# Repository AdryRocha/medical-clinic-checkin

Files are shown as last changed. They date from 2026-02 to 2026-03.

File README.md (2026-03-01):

# Medical Clinic Check-in System

Sistema embarcado de check-in para clínicas médicas baseado em Raspberry Pi Pico W. O paciente agenda sua consulta via Telegram Bot, apresenta o QR Code no totem, o dispositivo valida o agendamento, realiza verificação/cadastro biométrico e confirma o check-in com sincronização periódica via API REST.

---

## Sumário

- [Visão Geral](#visão-geral)
- [Hardware](#hardware)
- [Arquitetura de Software](#arquitetura-de-software)
- [Máquina de Estados](#máquina-de-estados)
- [Fluxo de Check-in](#fluxo-de-check-in)
- [Configuração](#configuração)
- [Build e Flash](#build-e-flash)
- [Backend (API + Bot)](#backend-api--bot)
- [Dependências](#dependências)
- [Estrutura do Projeto](#estrutura-do-projeto)
- [Demos Standalone](#demos-standalone)

---

## Visão Geral

| Item | Detalhe |
|---|---|
| **MCU** | RP2040W — Dual-core ARM Cortex-M0+ @ 133 MHz, WiFi CYW43439 |
| **RTOS** | FreeRTOS (5 tasks, queues, event groups) |
| **UI** | LVGL v8.3.11 — 7 telas, ícones desenhados via código |
| **Linguagem** | C++17 / C11 |
| **Build** | CMake ≥ 3.13 + Ninja 1.12.1 + GCC ARM 14_2_Rel1 |

**Funcionalidades principais:**
- Leitura de QR Code via scanner GM67 (UART)
- Validação de agendamento com dados armazenados no SD Card (FatFS)
- Verificação e cadastro de impressão digital via sensor R307S
- Sincronização de agendamentos e templates biométricos com API REST (Mongoose HTTP)
- Sincronização de hora via NTP (SNTP/lwIP)
- Interface touchscreen 4.0" 480×320

---

## Hardware

| Periférico | Interface | Pinos |
|---|---|---|
| Display ST7796 4.0" TFT 480×320 | SPI0 | MOSI=GP19, SCK=GP18, CS=GP17, DC=GP20, RST=GP21 |
| Touch FT6336U (Capacitivo) | I2C1 | SDA=GP6, SCL=GP7, RST=GP8, INT=GP9 |
| Scanner QR GM67 | UART0 | TX=GP0, RX=GP1 |
| Sensor Biométrico R307S | UART1 | TX=GP4, RX=GP5 |
| SD Card (FAT32) | SPI1 | MISO=GP12, MOSI=GP15, SCK=GP14, CS=GP13 |
| WiFi CYW43439 | Integrado | — |

> Diagrama completo em [`docs/diagrams/hardware_diagram.md`](docs/diagrams/hardware_diagram.md)

---

## Arquitetura de Software

O sistema segue uma arquitetura em **6 camadas**, desacoplando hardware de lógica de negócio:

```mermaid
graph TB
    subgraph Application["Application Layer"]
        Tasks["FreeRTOS Tasks"]
        StateMachine["State Machine"]
        UI["UI Screens"]
    end

    subgraph Service["Service Layer"]
        DataStorage["Data Storage Service"]
        AppointmentSvc["Appointment Service"]
        NetworkSync["Network Sync Service"]
        TimeSvc["Time Service"]
        FingerprintSvc["Fingerprint Service"]
    end

    subgraph Adapter["Adapter Layer"]
        LVGLDisplay["LVGL Display Adapter"]
        LVGLTouch["LVGL Touch Adapter"]
    end

    subgraph Driver["Driver Layer"]
        SDCard["SDCard Driver (FatFS)"]
        ST7796["ST7796 Display Driver"]
        FT6336U["FT6336U Touch Driver"]
        GM67["GM67 QR Driver"]
        R307S["R307S Fingerprint Driver"]
    end

    subgraph HAL["HAL Layer"]
        SPIHAL["SPI HAL"]
        UARTHAL["UART HAL"]
        I2CHAL["I2C HAL"]
        WiFiHAL["WiFi HAL"]
    end

    subgraph PicoSDK["Pico SDK + FreeRTOS"]
        hw_spi["hardware_spi"]
        hw_uart["hardware_uart"]
        hw_i2c["hardware_i2c"]
        pico_cyw43["pico_cyw43_arch"]
        freertos["FreeRTOS Kernel"]
    end

    Tasks -.-> StateMachine
    StateMachine -.-> UI
    Tasks -.-> AppointmentSvc
    Tasks -.-> TimeSvc
    Tasks -.-> FingerprintSvc
    Tasks -.-> DataStorage
    UI -.-> LVGLDisplay
    UI -.-> LVGLTouch
    DataStorage -.-> SDCard
    NetworkSync -.-> WiFiHAL
    FingerprintSvc -.-> R307S
    LVGLDisplay -.-> ST7796
    LVGLTouch -.-> FT6336U
    SDCard -.-> SPIHAL
    ST7796 -.-> SPIHAL
    FT6336U -.-> I2CHAL
    GM67 -.-> UARTHAL
    R307S -.-> UARTHAL
    SPIHAL -.-> hw_spi
    UARTHAL -.-> hw_uart
    I2CHAL -.-> hw_i2c
    WiFiHAL -.-> pico_cyw43

    style Application fill:#B3E5FC
    style Service fill:#A5D6A7
    style Adapter fill:#E1BEE7
    style Driver fill:#FFF9C4
    style HAL fill:#FFAB91
    style PicoSDK fill:#BDBDBD
```

### Tasks FreeRTOS

| Task | Prioridade | Stack | Responsabilidade |
|---|:---:|:-----:|---|
| `WiFi_Time_Init` | 5 | 2048 | Conecta WiFi, sincroniza NTP, auto-deleta após sucesso |
| `LVGL` | 4 | 3072 | `lv_timer_handler()` a cada 20 ms, gerencia telas por estado |
| `QR_Reader` | 3 | 1536 | Leitura contínua do GM67, envia dados para fila |
| `QR_Validator` | 2 | 2048 | Valida QR, biometria, marca check-in (orquestrador) |
| `Network` | 2 | 3072 | Download de agendamentos/templates, atualiza status na API |

### Services (Singletons)

| Service | Função |
|---|---|
| `AppointmentService` | Valida QR JSON, busca agendamento no SD, verifica CPF e janela de horário (−20/+10 min) |
| `NetworkSyncService` | Cliente HTTP (Mongoose): autenticação JWT, download/upload de agendamentos e templates |
| `DataStorageService` | Lê/grava JSON de agendamentos e templates `.dat` de fingerprint no SD Card (FatFS) |
| `TimeService` | Sincroniza NTP → RTC do RP2040, fornece data/hora formatadas |
| `FingerprintService` | Cadastro (2 capturas → template → SD + API) e verificação de digitais via R307S |

> Todos os diagramas em [`docs/diagrams/`](docs/diagrams/): [classes](docs/diagrams/class_diagrams.md) · [sequência](docs/diagrams/sequence_diagrams.md) · [arquitetura](docs/diagrams/software_architecture_layers_diagram.md)

---

## Máquina de Estados

| Estado | Descrição | Próximos Estados |
|---|---|---|
| `INITIALIZING` | Boot, conexão WiFi e sincronização NTP | `DOWNLOADING_APPOINTMENTS`, `ERROR_CRITICAL` |
| `DOWNLOADING_APPOINTMENTS` | Autenticação na API e download dos agendamentos do dia | `IDLE`, `ERROR_CRITICAL` |
| `IDLE` | Welcome Screen aguardando leitura de QR Code | `VALIDATING` |
| `VALIDATING` | Parse e validação do QR Code (cJSON, CPF, horário) | `FINGERPRINT_*`, `APPOINTMENT`, `ERROR` |
| `FINGERPRINT_VERIFYING` | Verificação biométrica (template do SD → sensor) | `APPOINTMENT`, `ERROR` |
| `FINGERPRINT_ENROLLING` | Cadastro biométrico (2 capturas → template) | `FINGERPRINT_UPLOADING`, `ERROR` |
| `FINGERPRINT_UPLOADING` | Upload do template para API | `APPOINTMENT`, `ERROR` |
| `APPOINTMENT` | Tela de check-in confirmado | `IDLE` (timeout 5s) |
| `ERROR` | Erro recuperável (QR inválido, consulta não encontrada) | `IDLE` (timeout 3s) |
| `ERROR_CRITICAL` | Falha de hardware, SD ausente, WiFi indisponível | `RESTARTING` |
| `RESTARTING` | Reinício via watchdog | `INITIALIZING` |

> Diagrama Mermaid completo em [`docs/diagrams/state_machine_diagram.md`](docs/diagrams/state_machine_diagram.md)

---

## Fluxo de Check-in

1. **Boot** → Conecta WiFi, sincroniza NTP, inicializa drivers
2. **Download** → Autentica na API (JWT), baixa agendamentos do dia + templates biométricos para o SD Card
3. **Idle** → Welcome Screen com relógio aguardando QR Code
4. **QR Scan** → GM67 lê QR → `task_qr_reader` envia JSON para fila FreeRTOS
5. **Validação** → `task_qr_validator` faz parse (cJSON), busca agendamento no SD, valida CPF e janela de horário
6. **Biometria** (se necessário):
   - *Verificação*: carrega template do SD → sensor → captura e compara
   - *Cadastro*: 2 capturas → gera template → salva no SD + upload para API
7. **Confirmação** → Tela de check-in confirmado, marca agendamento como "realizada" (local + API)
8. **Retorno** → Timeout → volta para Idle

---

## Configuração

Todas as configurações ficam centralizadas em `config/`:

| Arquivo | Descrição |
|---|---|
| `wifi_config.hpp` | SSID, senha e país do WiFi |
| `api_config.hpp` | URL da API, endpoints, credenciais, timeouts |
| `pin_config.hpp` | Mapeamento de todos os GPIOs |
| `display_config.hpp` | Resolução, rotação, SPI speed, buffer LVGL |
| `fingerprint_config.hpp` | UART e baudrate do sensor biométrico |
| `qr_code_reader_config.hpp` | UART e rate do scanner QR |
| `FreeRTOSConfig.h` | Configuração do kernel FreeRTOS |
| `lv_conf.h` | Configuração do LVGL |
| `hw_config.c` | Configuração do SD Card (FatFS) |
| `mongoose_config.h` | Configuração do Mongoose HTTP |
| `lwipopts.h` | Configuração do lwIP (TCP/IP stack) |

Antes de compilar, edite pelo menos:

**WiFi** (`config/wifi_config.hpp`):
```cpp
#define WIFI_SSID     "SuaRede"
#define WIFI_PASSWORD "SuaSenha"
#define WIFI_COUNTRY  "BR"
```

**API** (`config/api_config.hpp`):
```cpp
#define API_BASE_URL  "http://192.168.0.13:8000"
#define API_USERNAME  "seu_usuario"
#define API_PASSWORD  "sua_senha"
```

**Pinos** (`config/pin_config.hpp`): altere caso sua fiação seja diferente.

---

## Build e Flash

### Pré-requisitos

- [VS Code](https://code.visualstudio.com/) com extensão [**Raspberry Pi Pico**](https://marketplace.visualstudio.com/items?itemName=raspberry-pi.raspberry-pi-pico)
- Pico SDK 2.1.1, GCC ARM 14_2_Rel1, CMake ≥ 3.13, Ninja 1.12.1
- (Ou use o **Dev Container** incluso — tudo já configurado)

### Compilar

**Via extensão Raspberry Pi Pico (recomendado):**
1. Abra o projeto no VS Code
2. `Ctrl+Shift+B` → selecione **Compile Project**

**Via terminal:**
```bash
mkdir -p build && cd build
cmake .. -G Ninja
ninja
```

### Flash no Pico

**Via extensão Raspberry Pi Pico (recomendado):**
1. Conecte o Pico via USB
2. Clique no botão **Run** na barra de status, ou execute a task **Run Project**

**Via terminal:**
```bash
# picotool (sem desconectar USB):
picotool load build/medical-clinic-checkin-pico.elf -fx

# Ou UF2 manual: segure BOOTSEL, conecte USB, copie o .uf2
cp build/medical-clinic-checkin-pico.uf2 /media/$USER/RPI-RP2/
```

### Monitor Serial

```bash
minicom -b 115200 -o -D /dev/ttyACM0
```

---

## Backend (API + Bot)

O sistema embarcado se comunica com um backend composto por:

- **API REST** (FastAPI + PostgreSQL) — gerencia pacientes, profissionais, agendamentos e biometria
- **Telegram Bot** — agendamento de consultas pelo paciente, com envio do QR Code

> Repositório do backend: [Luana-Menezes/Clinicas_Medicas_WebAPI](https://github.com/Luana-Menezes/Clinicas_Medicas_WebAPI)

---

## Dependências

| Biblioteca | Versão | Origem | Uso |
|---|---|---|-----|
| [Pico SDK](https://github.com/raspberrypi/pico-sdk) | 2.1.1 | SDK | `pico_stdlib`, `hardware_spi`, `hardware_i2c`, `hardware_uart`, `hardware_rtc`, `pico_cyw43_arch`, lwIP |
| [FreeRTOS-Kernel](https://github.com/FreeRTOS/FreeRTOS-Kernel) | — | Submodule | RTOS: tasks, queues, event groups, semáforos |
| [LVGL](https://github.com/lvgl/lvgl) | 8.3.11 | FetchContent | Interface gráfica touchscreen |
| [no-OS-FatFS](https://github.com/carlk3/no-OS-FatFS-SD-SPI-RPi-Pico) | — | Submodule | Sistema de arquivos FAT32 no SD Card via SPI |
| [cJSON](https://github.com/DaveGamble/cJSON) | 1.7.18 | FetchContent | Parser JSON (agendamentos, QR Code) |
| [Mongoose](https://github.com/cesanta/mongoose) | 7.20 | FetchContent | Cliente HTTP para comunicação com a API |

---

## Estrutura do Projeto

```
├── CMakeLists.txt
├── pico_sdk_import.cmake
│
├── config/
│   ├── api_config.hpp                  # URL da API, endpoints, credenciais, timeouts
│   ├── display_config.hpp              # Resolução, rotação, SPI speed, buffer LVGL
│   ├── fingerprint_config.hpp          # UART e baudrate do sensor biométrico
│   ├── FreeRTOSConfig.h                # Configuração do kernel FreeRTOS
│   ├── hw_config.c                     # Configuração do SD Card (FatFS)
│   ├── lv_conf.h                       # Configuração do LVGL
│   ├── lvgl_tick_custom.h              # Tick customizado do LVGL para FreeRTOS
│   ├── lwipopts.h                      # Configuração do lwIP (TCP/IP stack)
│   ├── mongoose_config.h               # Configuração do Mongoose HTTP
│   ├── pin_config.hpp                  # Mapeamento de todos os GPIOs
│   ├── qr_code_reader_config.hpp       # UART e baudrate do scanner QR
│   ├── sntp_callbacks.h                # Callbacks de sincronização NTP
│   └── wifi_config.hpp                 # SSID, senha e país do WiFi
│
├── src/
│   ├── main.cpp                        # Entry point: init drivers → create tasks → scheduler
│   │
│   ├── core/
│   │   ├── state_machine.hpp           # Máquina de estados (singleton, 11 estados)
│   │   └── state_machine.cpp
│   │
│   ├── hal/
│   │   ├── interfaces/
│   │   │   ├── hal_spi_interface.hpp   # Interface abstrata SPI
│   │   │   ├── hal_i2c_interface.hpp   # Interface abstrata I2C
│   │   │   ├── hal_uart_interface.hpp  # Interface abstrata UART
│   │   │   └── hal_wifi_interface.hpp  # Interface abstrata WiFi
│   │   └── rp2040/
│   │       ├── hal_spi_rp2040.hpp/.cpp
│   │       ├── hal_i2c_rp2040.hpp/.cpp
│   │       ├── hal_uart_rp2040.hpp/.cpp
│   │       └── hal_wifi_rp2040.hpp/.cpp
│   │
│   ├── drivers/
│   │   ├── display/
│   │   │   ├── interface/display_interface.hpp
│   │   │   └── st7796/st7796_driver.hpp/.cpp
│   │   ├── touch/
│   │   │   ├── interface/touch_interface.hpp
│   │   │   └── ft6336u/ft6336u_driver.hpp/.cpp
│   │   ├── qr_code_reader/
│   │   │   ├── interface/qr_interface.hpp
│   │   │   └── gm67/gm67_driver.hpp/.cpp
│   │   └── fingerprint/
│   │       ├── interface/fingerprint_interface.hpp
│   │       └── r307s/r307s_driver.hpp/.cpp
│   │
│   ├── adapters/lvgl/
│   │   ├── lvgl_display_adapter.hpp/.cpp
│   │   └── lvgl_touch_adapter.hpp/.cpp
│   │
│   ├── services/
│   │   ├── appointment_service.hpp/.cpp     # Validação de QR e agendamentos
│   │   ├── data_storage_service.hpp/.cpp    # Leitura/escrita no SD Card
│   │   ├── fingerprint_service.hpp/.cpp     # Cadastro e verificação biométrica
│   │   ├── network_sync_service.hpp/.cpp    # Cliente HTTP (Mongoose)
│   │   └── time_service.hpp/.cpp            # NTP → RTC, data/hora
│   │
│   ├── tasks/
│   │   ├── task_wifi_time_init.hpp/.cpp     # Conexão WiFi + sincronização NTP
│   │   ├── task_lvgl.hpp/.cpp               # Loop LVGL + gerência de telas
│   │   ├── task_qr_reader.hpp/.cpp          # Leitura contínua do scanner QR
│   │   ├── task_qr_validator.hpp/.cpp       # Validação e orquestração do check-in
│   │   └── task_network.hpp/.cpp            # Download de agendamentos e templates
│   │
│   ├── ui/screens/
│   │   ├── welcome_screen.hpp/.cpp          # Tela principal (idle)
│   │   ├── init_status_screen.hpp/.cpp      # Tela de boot (WiFi, NTP, SD)
│   │   ├── appointment_screen.hpp/.cpp      # Check-in confirmado
│   │   ├── error_screen.hpp/.cpp            # Erro recuperável
│   │   ├── error_critical_screen.hpp/.cpp   # Erro crítico + countdown reboot
│   │   ├── fingerprint_operation_screen.hpp/.cpp  # Verificação/cadastro digital
│   │   └── fingerprint_upload_screen.hpp/.cpp     # Upload de template
│   │
│   └── tests/code_examples/
│       ├── README.md                        # Instruções dos demos
│       ├── lvgl_rtos_demo.cpp               # Demo display + touch
│       ├── qr_code_reader_demo.cpp          # Demo scanner QR
│       ├── fingerprint_demo.cpp             # Demo sensor biométrico
│       ├── sdcard_fatfs_demo.cpp            # Demo SD Card
│       └── wifi_demo.cpp                    # Demo WiFi
│
├── lib/
│   ├── FreeRTOS-Kernel/                     # Submodule
│   └── no-OS-FatFS/                         # Submodule
│
└── docs/
    ├── dev/                                 # Notas de desenvolvimento por periférico
    └── diagrams/
        ├── hardware_diagram.md
        ├── software_architecture_layers_diagram.md
        ├── class_diagrams.md
        ├── sequence_diagrams.md
        └── state_machine_diagram.md
```

---

## Demos Standalone

O projeto inclui demos para testar cada periférico isoladamente. Para compilar um demo específico, altere `BUILD_TARGET` no CMake:

```bash
cd build
cmake .. -G Ninja -DBUILD_TARGET=QR_DEMO
ninja
```

| Target | Testa |
|---|---|
| `MAIN` | Aplicação completa (padrão) |
| `LVGL_DEMO` | Display + touchscreen com widgets LVGL |
| `QR_DEMO` | Scanner GM67 em modo contínuo |
| `FINGERPRINT_DEMO` | Sensor R307S — cadastro, verificação, busca, exclusão |
| `SDCARD_DEMO` | SD Card — mount, leitura, escrita, listagem |
| `WIFI_DEMO` | WiFi — conexão, scan, DNS, TCP echo server, RSSI |

> Instruções detalhadas em [`src/tests/code_examples/README.md`](src/tests/code_examples/README.md)

---

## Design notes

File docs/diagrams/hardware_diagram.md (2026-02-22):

# Hardware Architecture

```mermaid
graph TB
    subgraph RPI["Raspberry Pi Pico<br/>"]
        CPU["RP2040W<br/>Dual Core<br/>"]
        
        subgraph Interfaces["Interfaces de Comunicação"]
            UART0["UART0"]
            UART1["UART1"]
            SPI0["SPI0"]
            SPI1["SPI1"]
            I2C1["I2C1"]
        end
        
        CPU --> UART0
        CPU --> UART1
        CPU --> SPI0
        CPU --> SPI1
        CPU --> I2C1
    end
    
    UART0 <-->|"TX/RX (GP0/GP1)"| QR["GM67<br/>Leitor QR Code<br/>Serial TTL"]
    UART1 <-->|"TX/RX (GP4/GP5)"| FP["R307S<br/>Leitor Biométrico<br/>Fingerprint"]
    SPI0 -->|"MOSI/SCK/CS DC(RS)/RST (GP19/18/17 20/21)"| DISPLAY["Display 4.0&quot;<br/>TFT 480x320<br/>Driver ST7796<br/>Touch Capacitivo"]
    SPI1 <-->|"MOSI/MISO/SCK/CS (GP15/12/14/13)"| SD["Módulo SD Card<br/>Armazenamento<br/>FAT32"]
    I2C1 <--> |"SDA/SCL/RST/INT (GP6/7/8/9)"| TOUCH["TouchScreen"]

    style RPI fill:#e3f2fd,stroke:#1565c0,stroke-width:4px,color:#000
    style CPU fill:#bbdefb,stroke:#1976d2,stroke-width:3px,color:#000
    style Interfaces fill:#ffe082,stroke:#fbc02d,stroke-width:3px,color:#000
    style UART0 fill:#fff9c4,stroke:#fbc02d,stroke-width:2px,color:#000
    style UART1 fill:#fff9c4,stroke:#fbc02d,stroke-width:2px,color:#000
    style SPI0 fill:#c8e6c9,stroke:#388e3c,stroke-width:2px,color:#000
    style SPI1 fill:#c8e6c9,stroke:#388e3c,stroke-width:2px,color:#000
    style I2C1 fill:#ffccbc,stroke:#d84315,stroke-width:2px,color:#000
    style QR fill:#b3e5fc,stroke:#0288d1,stroke-width:2px,color:#000
    style FP fill:#f8bbd0,stroke:#ad1457,stroke-width:2px,color:#000
    style DISPLAY fill:#fffde7,stroke:#fbc02d,stroke-width:3px,color:#000
    style SD fill:#e1bee7,stroke:#6a1b9a,stroke-width:2px,color:#000
    style TOUCH fill:#80deea,stroke:#00838f,stroke-width:2px,color:#000

    linkStyle default stroke:#000,stroke-width:1px,color:#000
```

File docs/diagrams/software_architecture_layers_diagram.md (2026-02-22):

# Software Architecture

```mermaid
graph TB
    subgraph Application["Application Layer"]
        Tasks["FreeRTOS Tasks"]
        StateMachine["State Machine"]
        UI["UI Screens"]
    end

    subgraph Service["Service Layer"]
        DataStorage["Data Storage Service*"]
        AppointmentSvc["Appointment Service*"]
        NetworkSync["Network Sync Service*"]
        TimeSvc["Time Service*"]
        FingerprintSvc["Fingerprint Service*"]
    end

    subgraph Adapter["Adapter Layer"]
        LVGLDisplay["LVGL Display Adapter"]
        LVGLTouch["LVGL Touch Adapter"]
    end

    subgraph Driver["Driver Layer"]
        SDCard["SDCard Driver (FatFS)"]
        ST7796["ST7796 Display Driver"]
        FT6336U["FT6336U Touch Driver"]
        GM67["GM67 QR Driver"]
        R307S["R307S Fingerprint Driver"]
    end

    subgraph HAL["HAL Layer"]
        SPIHAL["SPI HAL"]
        GPIOHAL["GPIO HAL"]
        UARTHAL["UART HAL"]
        I2CHAL["I2C HAL"]
        WiFiHAL["WiFi HAL"]
    end

    subgraph PicoSDK["Pico SDK + FreeRTOS"]
        hw_spi["hardware_spi"]
        hw_gpio["hardware_gpio"]
        hw_uart["hardware_uart"]
        hw_i2c["hardware_i2c"]
        pico_stdlib["pico_stdlib"]
        pico_cyw43["pico_cyw43_arch (WiFi)"]
        freertos["FreeRTOS Kernel"]
    end

    subgraph Hardware["Hardware"]
        RP2040W["RP2040W Silicon"]
    end

    %% Application internal connections
    Tasks -.-> StateMachine
    StateMachine -.-> UI
    
    %% Application to Service connections
    Tasks -.-> DataStorage
    Tasks -.-> AppointmentSvc
    Tasks -.-> TimeSvc
    Tasks -.-> FingerprintSvc
    AppointmentSvc -.-> TimeSvc

    %% Application to Adapter connections
    UI -.-> LVGLDisplay
    UI -.-> LVGLTouch

    %% Service to Driver/HAL connections
    DataStorage -.-> SDCard
    AppointmentSvc -.-> GM67
    NetworkSync -.-> SDCard
    NetworkSync -.-> WiFiHAL
    TimeSvc -.-> WiFiHAL
    FingerprintSvc -.-> R307S
    FingerprintSvc -.-> DataStorage

    %% Adapter to Driver connections
    LVGLDisplay -.-> ST7796
    LVGLTouch -.-> FT6336U

    %% Driver to HAL connections
    SDCard -.-> SPIHAL
    ST7796 -.-> SPIHAL
    FT6336U -.-> I2CHAL
    GM67 -.-> UARTHAL
    R307S -.-> UARTHAL

    SPIHAL -.-> hw_spi
    GPIOHAL -.-> hw_gpio
    UARTHAL -.-> hw_uart
    I2CHAL -.-> hw_i2c
    WiFiHAL -.-> pico_cyw43

    hw_spi -.-> RP2040W
    hw_gpio -.-> RP2040W
    hw_uart -.-> RP2040W
    hw_i2c -.-> RP2040W
    pico_stdlib -.-> RP2040W
    pico_cyw43 -.-> RP2040W
    freertos -.-> RP2040W

    style Application fill:#B3E5FC
    style Service fill:#A5D6A7
    style Adapter fill:#E1BEE7
    style Driver fill:#FFF9C4
    style HAL fill:#FFAB91
    style PicoSDK fill:#BDBDBD
    style Hardware fill:#757575
```

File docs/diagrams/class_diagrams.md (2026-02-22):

# Class Diagrams

Diagramas de classes de todas as camadas do sistema.

---

## 1. Services Layer

Camada de serviços com lógica de negócio.

```mermaid
classDiagram
    direction TB

    class StateMachine {
        <<Singleton>>
        -State state_
        +getInstance() StateMachine&
        +setState(State newState) void
        +getState() State
        +getStateName() const char*
        +getStateName(State state) const char*
    }

    class State {
        <<enumeration>>
        INITIALIZING
        DOWNLOADING_APPOINTMENTS
        IDLE
        VALIDATING
        FINGERPRINT_VERIFYING
        FINGERPRINT_ENROLLING
        FINGERPRINT_UPLOADING
        APPOINTMENT
        ERROR
        ERROR_CRITICAL
        RESTARTING
    }

    class AppointmentService {
        <<Singleton>>
        +getInstance() AppointmentService&
        +validateAndParseQRCode(qr_json, qr_data) bool
        +validateAppointmentById(qr_data, info) bool
        +markAppointmentCompleted(appointment_id) bool
        +maskCPF(cpf) string$
        -findAppointmentById(root, appt_id, appointment_out) bool
        -extractAppointmentData(appointment, info) void
        -validateCPFMatch(qr_cpf, db_cpf) bool
        -validateAppointmentTime(appointment_time) bool
        -cleanCPF(cpf) string
    }

    class FingerprintService {
        <<Singleton>>
        -R307S_Driver* fp_driver_
        -HAL_UART_RP2040* uart_hal_
        -bool is_initialized_
        +getInstance() FingerprintService&
        +init() bool
        +isInitialized() bool
        +enrollFingerprint(template_data, timeout_per_scan_ms) bool
        +verifyFingerprint(patient_id, confidence, timeout_ms) bool
        +clearSensorMemory() bool
        +getTemplateCount(count) bool
        -loadTemplateToSensor(data, slot) bool
        -waitForFinger(timeout_ms) bool
        -waitForFingerRemoval(timeout_ms) bool
    }

    class NetworkSyncService {
        <<Singleton>>
        -string access_token_
        +getInstance() NetworkSyncService&
        +authenticate(timeout_ms) bool
        +downloadAppointments(date, json_response, timeout_ms) bool
        +updateAppointmentStatus(appointment_id, new_status, timeout_ms) bool
        +downloadFingerprintTemplate(patient_id, template_data, timeout_ms) bool
        +uploadFingerprintTemplate(patient_id, template_data, timeout_ms) bool
        +downloadFingerprintsForAppointments(json_appointments) int
        +hasToken() bool
        -httpCallback(c, ev, ev_data) void$
    }

    class DataStorageService {
        <<Singleton>>
        +getInstance() DataStorageService&
        +init() bool
        +saveAppointments(date, json_data) bool
        +hasAppointments(date) bool
        +readAppointments(date, json_data) bool
        +getTodayDate() string
        +getTomorrowDate() string
        +isReady() bool
        +markAppointmentCompleted(date, appointment_id) bool
        +isAppointmentCompleted(date, appointment_id) bool
        +saveFingerprintTemplate(patient_id, template_data) bool
        +loadFingerprintTemplate(patient_id, template_data) bool
        +hasFingerprintTemplate(patient_id) bool
        +deleteFingerprintTemplate(patient_id) bool
        +clearAllFingerprints() bool
    }

    class TimeService {
        <<Singleton>>
        -bool initialized_
        -bool time_synced_
        +getInstance() TimeService&
        +init() bool
        +getTimeString() string
        +getDateString() string
        +getDateTimeString() string
        +isTimeSynced() bool
        +markTimeSynced() void
        +extractHourMinute(time_str, hour, min) bool$
    }

    class AppointmentInfo {
        <<struct>>
        +int id
        +string patient_name
        +string patient_cpf
        +string professional_name
        +string category
        +string time
        +string status
        +string qr_hash
        +bool found
        +PatientBiometry patient
        +bool requires_fingerprint_verification
        +bool requires_fingerprint_enrollment
    }

    class PatientBiometry {
        <<struct>>
        +int id
        +bool aceita_digital
        +bool fingerprint_uploaded
    }

    class QRCodeData {
        <<struct>>
        +string cmd
        +int appt_id
        +string cpf
        +string name
        +string hash
        +bool valid
    }

    %% Relacionamentos
    StateMachine *-- State : contains
    AppointmentInfo *-- PatientBiometry : contains

    AppointmentService ..> QRCodeData : uses
    AppointmentService ..> AppointmentInfo : uses
    AppointmentService ..> DataStorageService : depends
    AppointmentService ..> NetworkSyncService : depends
    AppointmentService ..> TimeService : depends

    FingerprintService ..> DataStorageService : loads templates
    FingerprintService ..> R307S_Driver : controls sensor

    NetworkSyncService ..> DataStorageService : saves to

    DataStorageService ..> TimeService : gets date
```

---

## 2. HAL Layer (Hardware Abstraction)

Interfaces abstratas e implementações específicas do RP2040.

```mermaid
classDiagram
    direction TB

    class HAL_SPI_Interface {
        <<interface>>
        +init(baudrate) bool*
        +write(data, len) size_t*
        +read(data, len) size_t*
        +setCS(state) void*
        +setDC(state) void*
        +reset() void*
    }

    class HAL_I2C_Interface {
        <<interface>>
        +init(baudrate) bool*
        +write(address, data, length, sendStop) bool*
        +read(address, data, length, sendStop) bool*
        +writeRead(address, writeData, writeLength, readData, readLength) bool*
    }

    class HAL_UART_Interface {
        <<interface>>
        +init(baudrate, data_bits, stop_bits, parity) bool*
        +write(data, length) size_t*
        +read(data, length) size_t*
        +available() size_t*
        +writeByte(byte) void*
        +readByte() uint8_t*
    }

    class HAL_SPI_RP2040 {
        -spi_inst_t* spi_instance_
        -uint8_t pin_mosi_
        -uint8_t pin_miso_
        -uint8_t pin_sck_
        -uint8_t pin_cs_
        -uint8_t pin_dc_
        -uint8_t pin_rst_
        +init(baudrate) bool
        +write(data, len) size_t
        +read(data, len) size_t
        +setCS(state) void
        +setDC(state) void
        +reset() void
    }

    class HAL_I2C_RP2040 {
        -i2c_inst_t* i2c_instance_
        -uint8_t pin_sda_
        -uint8_t pin_scl_
        +init(baudrate) bool
        +write(address, data, length, sendStop) bool
        +read(address, data, length, sendStop) bool
        +writeRead(...) bool
    }

    class HAL_UART_RP2040 {
        -uart_inst_t* uart_instance_
        -uint8_t pin_tx_
        -uint8_t pin_rx_
        +init(baudrate, data_bits, stop_bits, parity) bool
        +write(data, length) size_t
        +read(data, length) size_t
        +available() size_t
    }

    HAL_SPI_Interface <|.. HAL_SPI_RP2040 : implements
    HAL_I2C_Interface <|.. HAL_I2C_RP2040 : implements
    HAL_UART_Interface <|.. HAL_UART_RP2040 : implements
```

---

## 3. Driver Layer

Drivers de hardware com interfaces abstratas.

```mermaid
classDiagram
    direction TB

    class DisplayInterface {
        <<interface>>
        +init() bool*
        +getWidth() uint16_t*
        +getHeight() uint16_t*
        +drawPixels(x1, y1, x2, y2, color_data) void*
        +fillRect(x1, y1, x2, y2, color) void*
        +setBacklight(brightness) void*
        +setPower(state) void*
        +setRotation(rotation) void*
    }

    class TouchInterface {
        <<interface>>
        +init() bool*
        +readTouch(point) bool*
        +isTouched() bool*
        +getMaxTouchPoints() uint8_t*
    }

    class QR_Interface {
        <<interface>>
        +init() bool*
        +readScan(buffer, max_length, timeout_ms) size_t*
        +isScanAvailable() bool*
        +setScanCallback(callback) void*
        +process() void*
        +enableScan(enable) bool*
        +triggerScan() bool*
    }

    class FingerprintInterface {
        <<interface>>
        +init() bool*
        +verifyPassword() bool*
        +getImage() FingerprintStatus*
        +image2Tz(slot) FingerprintStatus*
        +createModel() FingerprintStatus*
        +storeModel(id) FingerprintStatus*
        +fingerFastSearch(match) FingerprintStatus*
        +deleteModel(id) FingerprintStatus*
        +emptyDatabase() FingerprintStatus*
        +getTemplateCount(count) FingerprintStatus*
        +enrollFingerprint(id) FingerprintStatus*
        +matchFingerprint(match) FingerprintStatus*
        +loadTemplate(id, slot) FingerprintStatus*
        +uploadTemplate(slot, data) FingerprintStatus*
        +downloadTemplate(slot, data) FingerprintStatus*
        +compareTemplates(confidence) FingerprintStatus*
        +setLED(on) bool*
    }

    class ST7796Driver {
        -HAL_SPI_Interface* hal_spi_
        -uint16_t width_
        -uint16_t height_
        -uint8_t rotation_
        +init() bool
        +drawPixels(...) void
        +fillRect(...) void
        +setRotation(rotation) void
    }

    class FT6336U_Driver {
        -HAL_I2C_Interface* i2c_
        -uint8_t i2c_address_
        -uint16_t screen_width_
        -uint16_t screen_height_
        +init() bool
        +readTouch(point) bool
        +isTouched() bool
        +reset() void
    }

    class GM67_Driver {
        -HAL_UART_Interface* uart_hal_
        -ScanCallback scan_callback_
        -char rx_buffer_[1024]
        +init() bool
        +readScan(buffer, max_length, timeout_ms) size_t
        +isScanAvailable() bool
        +process() void
        +sendCommand(command) bool
    }

    class R307S_Driver {
        -HAL_UART_Interface* uart_hal_
        -uint32_t password_
        -uint32_t address_
        -bool is_initialized_
        -size_t data_packet_size_
        +init() bool
        +verifyPassword() bool
        +getImage() FingerprintStatus
        +image2Tz(slot) FingerprintStatus
        +createModel() FingerprintStatus
        +storeModel(id) FingerprintStatus
        +fingerFastSearch(match) FingerprintStatus
        +deleteModel(id) FingerprintStatus
        +emptyDatabase() FingerprintStatus
        +getTemplateCount(count) FingerprintStatus
        +enrollFingerprint(id) FingerprintStatus
        +matchFingerprint(match) FingerprintStatus
        +loadTemplate(id, slot) FingerprintStatus
        +uploadTemplate(slot, data) FingerprintStatus
        +downloadTemplate(slot, data) FingerprintStatus
        +compareTemplates(confidence) FingerprintStatus
        +setLED(on) bool
        +readSysPara(status, system_id, library_size, security_level) FingerprintStatus
    }

    class TouchPoint {
        <<struct>>
        +uint16_t x
        +uint16_t y
        +uint8_t event
        +bool valid
    }

    class FingerprintStatus {
        <<enumeration>>
        OK
        ERROR_COMM
        ERROR_NO_FINGER
        ERROR_ENROLL_FAIL
        ERROR_BAD_IMAGE
        ERROR_TOO_MESSY
        ERROR_FEATURE_FAIL
        ERROR_NO_MATCH
        ERROR_NOT_FOUND
        ERROR_MERGE_FAIL
        ERROR_DELETE_FAIL
        ERROR_CLEAR_FAIL
        ERROR_WRONG_PASSWORD
        ERROR_NO_TEMPLATE
        ERROR_UPLOAD_FAIL
        ERROR_RECV_FAIL
        ERROR_TIMEOUT
    }

    class FingerprintMatch {
        <<struct>>
        +uint16_t id
        +uint16_t confidence
        +bool matched
    }

    DisplayInterface <|.. ST7796Driver : implements
    TouchInterface <|.. FT6336U_Driver : implements
    QR_Interface <|.. GM67_Driver : implements
    FingerprintInterface <|.. R307S_Driver : implements

    ST7796Driver --> HAL_SPI_Interface : uses
    FT6336U_Driver --> HAL_I2C_Interface : uses
    GM67_Driver --> HAL_UART_Interface : uses
    R307S_Driver --> HAL_UART_Interface : uses

    TouchInterface ..> TouchPoint : returns
    FingerprintInterface ..> FingerprintStatus : returns
    FingerprintInterface ..> FingerprintMatch : returns
```

---

## 4. Adapter Layer

Adaptadores entre LVGL e drivers de hardware.

```mermaid
classDiagram
    direction TB

    class LVGLDisplayAdapter {
        -DisplayInterface* display_
        -lv_disp_drv_t disp_drv_
        -lv_disp_draw_buf_t draw_buf_
        -lv_color_t* buf1_
        -lv_color_t* buf2_
        +LVGLDisplayAdapter(display, buf1, buf2, buf_size)
        +registerDisplay() lv_disp_t*
        -flushCallback(disp_drv, area, color_p) void$
    }

    class LVGLTouchAdapter {
        -TouchInterface* touch_
        -lv_indev_drv_t indev_drv_
        -lv_indev_t* indev_
        -uint16_t display_width_
        -uint16_t display_height_
        -uint8_t rotation_
        +LVGLTouchAdapter(touch, width, height, rotation)
        +registerInputDevice() lv_indev_t*
        -readCallback(drv, data) void$
        -transformCoordinates(point, x_out, y_out) void
    }

    class DisplayInterface {
        <<interface>>
    }

    class TouchInterface {
        <<interface>>
    }

    LVGLDisplayAdapter --> DisplayInterface : uses
    LVGLTouchAdapter --> TouchInterface : uses
```

---

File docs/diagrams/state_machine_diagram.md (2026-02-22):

# State Machine Diagram

## 1. Fluxo Principal

Inicialização, check-in e tratamento de erros.

```mermaid
stateDiagram-v2
    [*] --> INITIALIZING : Power On

    INITIALIZING : Conecta WiFi, NTP e drivers

    DOWNLOADING_APPOINTMENTS : Autentica API e baixa agendamentos

    IDLE : Aguardando QR Code
    IDLE : Welcome Screen + data/hora

    VALIDATING : Parse JSON + valida agendamento

    APPOINTMENT : Exibe confirmação de check-in

    ERROR : Erro recuperável (3-5s)

    ERROR_CRITICAL : Falha de hardware / WiFi / SD

    RESTARTING : Reiniciando via watchdog

    %% Transições
    INITIALIZING --> DOWNLOADING_APPOINTMENTS : WiFi + NTP OK
    INITIALIZING --> ERROR_CRITICAL : Falha crítica

    DOWNLOADING_APPOINTMENTS --> IDLE : Download OK
    DOWNLOADING_APPOINTMENTS --> ERROR_CRITICAL : Falha persistente

    IDLE --> VALIDATING : QR Code recebido

    VALIDATING --> APPOINTMENT : Válida (sem biometria)
    VALIDATING --> FINGERPRINT : Requer biometria
    VALIDATING --> ERROR : Inválido

    state FINGERPRINT {
        direction LR
        [*] --> Ver_Diagrama_2
    }

    FINGERPRINT --> APPOINTMENT : Biometria OK
    FINGERPRINT --> ERROR : Biometria falhou

    APPOINTMENT --> IDLE : Timeout (5s)
    ERROR --> IDLE : Timeout (3s)
    ERROR_CRITICAL --> RESTARTING : Timeout ou botão
    RESTARTING --> [*] : Watchdog reset
```

---

## 2. Sub-estados Biométricos

Detalhamento do fluxo de fingerprint dentro do check-in.

```mermaid
stateDiagram-v2
    state "Biometria" as BIO {
        [*] --> DECISION

        state DECISION <<choice>>
        DECISION --> FINGERPRINT_VERIFYING : Template existe
        DECISION --> FINGERPRINT_ENROLLING : Sem template

        FINGERPRINT_VERIFYING : Carrega template do SD
        FINGERPRINT_VERIFYING : Captura dedo + compara

        FINGERPRINT_ENROLLING : Captura em 2 etapas
        FINGERPRINT_ENROLLING : Gera modelo + salva SD

        FINGERPRINT_UPLOADING : Envia template para API

        FINGERPRINT_VERIFYING --> [*] : Digital verificada
        FINGERPRINT_VERIFYING --> ERROR : Não reconhecida

        FINGERPRINT_ENROLLING --> FINGERPRINT_UPLOADING : Cadastro OK
        FINGERPRINT_ENROLLING --> ERROR : Falha no cadastro

        FINGERPRINT_UPLOADING --> [*] : Upload concluído/offline

        ERROR --> [*] : Retorna erro
    }
```

## Descrição dos Estados

| Estado | Descrição | Próximos Estados |
|---|---|---|
| `INITIALIZING` | Boot do sistema, conexão WiFi e sincronização NTP | `DOWNLOADING_APPOINTMENTS`, `ERROR_CRITICAL` |
| `DOWNLOADING_APPOINTMENTS` | Autenticação na API e download dos agendamentos do dia | `IDLE`, `ERROR_CRITICAL` |
| `IDLE` | Aguardando leitura de QR Code na Welcome Screen | `VALIDATING` |
| `VALIDATING` | Processando e validando dados do QR Code | `FINGERPRINT_VERIFYING`, `FINGERPRINT_ENROLLING`, `APPOINTMENT`, `ERROR` |
| `FINGERPRINT_VERIFYING` | Verificando digital do paciente contra template armazenado | `APPOINTMENT`, `ERROR` |
| `FINGERPRINT_ENROLLING` | Cadastrando digital do paciente (captura em 2 etapas) | `FINGERPRINT_UPLOADING`, `ERROR` |
| `FINGERPRINT_UPLOADING` | Enviando template biométrico para API | `APPOINTMENT` |
| `APPOINTMENT` | Exibindo confirmação de check-in ao paciente | `IDLE` |
| `ERROR` | Erro recuperável (QR inválido, consulta não encontrada, digital falhou) | `IDLE` |
| `ERROR_CRITICAL` | Erro crítico que requer intervenção | `RESTARTING` |
| `RESTARTING` | Sistema reiniciando via watchdog | `INITIALIZING` |

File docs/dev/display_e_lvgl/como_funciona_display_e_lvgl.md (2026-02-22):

# Display, HAL, Adapters e LVGL

## 📋 Visão Geral da Arquitetura

O sistema usa **3 camadas** para controlar o display:

```
┌─────────────────────────────────────────┐
│         LVGL (Biblioteca GUI)           │  ← Interface gráfica
├─────────────────────────────────────────┤
│      LVGLDisplayAdapter (Bridge)        │  ← Conecta LVGL ao driver
├─────────────────────────────────────────┤
│   ST7796Driver (Display Controller)     │  ← Controla o display
├─────────────────────────────────────────┤
│   HAL_SPI_RP2040 (Hardware Abstraction) │  ← Acessa hardware SPI
└─────────────────────────────────────────┘
```

---

## 🔧 1. HAL (Hardware Abstraction Layer)

### O que é?
Camada que **isola o hardware específico** (RP2040) do resto do código.

### Interface: `HAL_SPI_Interface`
```cpp
class HAL_SPI_Interface {
    virtual bool init(uint32_t baudrate) = 0;
    virtual size_t write(const uint8_t* data, size_t len) = 0;
    virtual void setCS(bool state) = 0;  // Chip Select
    virtual void setDC(bool state) = 0;  // Data/Command
    virtual void reset() = 0;
};
```

### Implementação: `HAL_SPI_RP2040`
- Usa **hardware/spi.h** do Pico SDK
- Configura pinos GPIO (MOSI, SCK, CS, DC, RST)
- Velocidade: até 20 MHz

**Por que existe?** 
- Trocar de microcontrolador (ex: STM32) só requer reimplementar o HAL
- Resto do código permanece igual

---

## 🖥️ 2. Driver de Display

### Interface: `DisplayInterface`
```cpp
class DisplayInterface {
    virtual bool init() = 0;
    virtual uint16_t getWidth() const = 0;
    virtual uint16_t getHeight() const = 0;
    virtual void drawPixels(uint16_t x1, uint16_t y1, 
                           uint16_t x2, uint16_t y2, 
                           const uint16_t* color_data) = 0;
    virtual void setRotation(uint8_t rotation) = 0;
};
```

### Implementação: `ST7796Driver`
- Controla display **ST7796** (480x320, RGB565)
- Envia **comandos** via SPI:
  - `CMD_SWRESET` - Reset de software
  - `CMD_CASET/RASET` - Define área de desenho
  - `CMD_RAMWR` - Escreve pixels
  - `CMD_MADCTL` - Controla rotação

**Método principal:**
```cpp
void ST7796Driver::drawPixels(uint16_t x1, uint16_t y1, 
                              uint16_t x2, uint16_t y2, 
                              const uint16_t* color_data) {
    setAddressWindow(x1, y1, x2, y2);  // Define região
    hal_spi_->write((uint8_t*)color_data, len * 2);  // Envia pixels
}
```

**Por que Interface?**
- Trocar para outro display (ILI9341, GC9A01) é fácil
- Basta criar novo driver implementando `DisplayInterface`

---

## 🔌 3. Adapter LVGL

### O que é?
**Ponte** entre LVGL (biblioteca genérica) e nosso driver específico.

### `LVGLDisplayAdapter`
```cpp
class LVGLDisplayAdapter {
private:
    DisplayInterface* display_;       // Nosso driver
    lv_disp_drv_t disp_drv_;         // Estrutura LVGL
    lv_disp_draw_buf_t draw_buf_;    // Buffers LVGL
    
    static void flushCallback(lv_disp_drv_t* disp_drv, 
                             const lv_area_t* area, 
                             lv_color_t* color_p);
};
```

### Como funciona?
1. **LVGL desenha** em buffers internos
2. Quando termina, chama `flushCallback()`
3. Callback pega os pixels e chama `display_->drawPixels()`
4. Pixels aparecem no display

**Inicialização:**
```cpp
// 1. Cria HAL
HAL_SPI_RP2040 hal_spi(spi0, pins...);

// 2. Cria driver
ST7796Driver display(&hal_spi, 480, 320);
display.init();

// 3. Cria adapter
LVGLDisplayAdapter adapter(&display, buf1, buf2, buf_size);
adapter.registerDisplay();

// 4. LVGL pronto para usar!
lv_obj_t* btn = lv_btn_create(lv_scr_act());
```

---

## 🎯 4. LVGL (Light and Versatile Graphics Library)

### Configuração: `lv_conf.h`
```c
#define LV_COLOR_DEPTH 16        // RGB565
#define LV_COLOR_16_SWAP 1       // Byte swap para SPI
#define LV_MEM_SIZE (48 * 1024)  // 48KB RAM para widgets
#define LV_TICK_CUSTOM 1         // Usa FreeRTOS tick
```

### Buffers
- **Buffer único**: Menor uso de RAM, mais lento
- **Double buffer**: Mais suave, usa 2x RAM

```cpp
#define LVGL_BUFFER_LINES 40  // 480 * 40 * 2 = ~38KB por buffer
lv_color_t buf1[480 * 40];
lv_color_t buf2[480 * 40];  // Opcional
```

### Com FreeRTOS
```cpp
void lvgl_task(void* param) {
    while (1) {
        xSemaphoreTake(lvgl_mutex, portMAX_DELAY);
        lv_timer_handler();  // Processa eventos e atualiza tela
        xSemaphoreGive(lvgl_mutex);
        vTaskDelay(pdMS_TO_TICKS(5));
    }
}
```

---

## 🔄 Fluxo Completo de Renderização

```
1. LVGL decide o que desenhar
   ↓
2. Renderiza em buf1/buf2 (RGB565)
   ↓
3. Chama flushCallback() do Adapter
   ↓
4. Adapter chama display_->drawPixels()
   ↓
5. ST7796Driver define janela (CASET/RASET)
   ↓
6. ST7796Driver envia via hal_spi_->write()
   ↓
7. HAL_SPI_RP2040 usa spi_write_blocking()
   ↓
8. Pixels aparecem no display físico!
```

---

## 🎨 Exemplo Prático

```cpp
// Setup (executar uma vez)
lv_init();

HAL_SPI_RP2040 hal_spi(spi0, mosi, miso, sck, cs, dc, rst);
ST7796Driver display(&hal_spi, 480, 320);
display.init();

LVGLDisplayAdapter adapter(&display, buf1, buf2, 480*40);
adapter.registerDisplay();

// Criar UI
lv_obj_t* label = lv_label_create(lv_scr_act());
lv_label_set_text(label, "Hello World!");
lv_obj_center(label);

// Loop (chamar repetidamente)
while (1) {
    lv_timer_handler();
    sleep_ms(5);
}
```

---

## 📁 Estrutura de Arquivos

```
src/
├── hal/
│   ├── interfaces/
│   │   └── hal_spi_interface.hpp      ← Interface abstrata
│   └── rp2040/
│       ├── hal_spi_rp2040.hpp         ← Implementação RP2040
│       └── hal_spi_rp2040.cpp
│
├── drivers/
│   └── display/
│       ├── interface/
│       │   └── display_interface.hpp   ← Interface abstrata
│       └── st7796/
│           ├── st7796_driver.hpp       ← Driver ST7796
│           └── st7796_driver.cpp
│
└── adapters/
    └── lvgl/
        ├── lvgl_display_adapter.hpp    ← Adapter LVGL
        └── lvgl_display_adapter.cpp

config/
└── lv_conf.h                           ← Configuração LVGL
```

---

## ⚡ Pontos-Chave

1. **Separação de responsabilidades**: cada camada tem uma função clara
2. **Interfaces abstratas**: facilita troca de hardware/displays
3. **Adapter pattern**: desacopla LVGL dos drivers específicos
4. **HAL isola hardware**: portabilidade entre microcontroladores
5. **LVGL é agnóstico**: não sabe nada sobre ST7796 ou RP2040

---

## 🐛 Troubleshooting

| Problema | Causa Provável | Solução |
|---|---|---|
| Tela branca | `flushCallback` não configurado | Verificar `adapter.registerDisplay()` |
| Cores erradas | Byte swap incorreto | `LV_COLOR_16_SWAP 1` no lv_conf.h |
| Tela lenta | Buffer muito pequeno | Aumentar `LVGL_BUFFER_LINES` |
| Crash | RAM insuficiente | Reduzir `LV_MEM_SIZE` ou buffers |
| SPI não funciona | Pinos errados | Conferir pin_config.hpp |

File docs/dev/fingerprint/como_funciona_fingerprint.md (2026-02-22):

# R307S Fingerprint Sensor - Como Funciona

## O que é o Sensor R307S?

O R307S é um sensor de impressão digital que funciona como um "mini computador especializado" em reconhecer dedos. Ele tem sua própria memória interna onde guarda as impressões digitais cadastradas (até 1000 fingerprints).

**Analogia**: Pense no sensor como um cofre digital. Ele:
- Tira "fotos" do seu dedo
- Transforma essas fotos em "códigos secretos" (templates)
- Guarda esses códigos na sua memória interna
- Compara novos dedos com os códigos guardados

## Conexão e Hardware

### Pinos de Conexão
```
Sensor R307S          Raspberry Pi Pico
┌─────────────┐       ┌─────────────┐
│  VCC (Red)  │ ───── │ 5V          │
│  GND (Black)│ ───── │ GND         │
│  TX (White) │ ───── │ GPIO 5 (RX) │
│  RX (Green) │ ───── │ GPIO 4 (TX) │
└─────────────┘       └─────────────┘
```

**Importante**: 
- VCC precisa de **5V**
- A comunicação é **serial UART** a 57600 baud
- TX do sensor conecta no RX do Pico (e vice-versa)

### Protocolo de Comunicação

O sensor não entende português - ele só fala "pacotes". Cada pacote tem uma estrutura específica:

```
┌────────┬─────────┬─────┬────────┬──────────┬──────────┐
│ Header │ Address │ PID │ Length │   Data   │ Checksum │
│  2B    │   4B    │ 1B  │   2B   │    nB    │    2B    │
└────────┴─────────┴─────┴────────┴──────────┴──────────┘
```

**Explicação dos campos**:

1. **Header (0xEF01)**: É como dizer "Atenção, começa uma mensagem aqui!"
2. **Address (0xFFFFFFFF)**: Endereço do sensor (padrão aceita qualquer)
3. **PID (Package Identifier)**:
   - `0x01` = Comando (você mandando uma ordem)
   - `0x07` = Resposta (sensor te respondendo)
   - `0x02` / `0x08` = Dados grandes sendo enviados em partes
4. **Length**: Tamanho do que vem depois
5. **Data**: O comando/dados em si
6. **Checksum**: Soma para verificar se a mensagem não foi corrompida

## Como o Sensor Processa uma Digital

### Entendendo o Fluxo Completo

O sensor não guarda "fotos" das digitais. Ele trabalha em 3 etapas:

```
1. CAPTURAR           2. EXTRAIR              3. GUARDAR/COMPARAR
   [Foto]     ──►    [Características]   ──►    [Template]
                      (pontos únicos)           (código final)
```

**Passo a passo detalhado**:

#### 1️⃣ Captura de Imagem (`getImage()`)
O sensor tira uma "foto" do dedo colocado no sensor.
- **Tempo**: Espera até 5 segundos para detectar um dedo
- **Retorno**: OK se conseguiu, ERROR_NO_FINGER se ninguém colocou o dedo

#### 2️⃣ Extração de Características (`image2Tz(slot)`)
Transforma a foto em características únicas (pontos marcantes da digital).

**O que é o "slot"?**
- O sensor tem 2 "gavetas" temporárias de memória (CharBuffer1 e CharBuffer2)
- Slot 1 = CharBuffer1
- Slot 2 = CharBuffer2
- Você precisa escolher em qual gaveta vai guardar temporariamente

**Por que 2 gavetas?**
- Para cadastrar: você compara 2 scans do mesmo dedo
- Para verificar: você compara o dedo atual com um template guardado

#### 3️⃣ Criar Modelo (`createModel()`)
Combina as características das 2 gavetas em um modelo final confiável.
- Pega CharBuffer1 + CharBuffer2 → cria template final
- Se os 2 scans forem muito diferentes, falha (ERROR_MERGE_FAIL)

#### 4️⃣ Guardar na Memória (`storeModel(id)`)
Salva o template final na memória permanente do sensor.
- Você escolhe um ID (1 a 1000)
- O sensor guarda esse template com esse ID

---

## As 3 Operações Principais

### 🆕 CADASTRAR (Enroll)

**Objetivo**: Cadastrar uma nova impressão digital no banco de dados do sensor.

**Fluxograma**:
```
┌─────────────────────────────────────────────┐
│ 1. Coloque o dedo                           │
│    └─► getImage() → image2Tz(slot=1)       │
├─────────────────────────────────────────────┤
│ 2. REMOVA o dedo                            │
│    └─► Aguarda sensor não detectar dedo    │
├─────────────────────────────────────────────┤
│ 3. Coloque o MESMO dedo novamente           │
│    └─► getImage() → image2Tz(slot=2)       │
├─────────────────────────────────────────────┤
│ 4. Combinar os 2 scans                      │
│    └─► createModel()                        │
├─────────────────────────────────────────────┤
│ 5. Salvar no ID escolhido                   │
│    └─► storeModel(id)                       │
└─────────────────────────────────────────────┘
```

**Por que escanear 2 vezes?**
- Aumenta a precisão (evita falsos positivos)
- Se você colocar o dedo de forma diferente nas 2 vezes, o sensor percebe e rejeita
- O modelo final é uma "média" dos 2 scans

**Código**:
```cpp
// Método de alto nível (recomendado - já faz tudo)
FingerprintStatus status = fp_sensor->enrollFingerprint(100);  // Cadastra no ID 100

// Método de baixo nível (controle manual)
fp_sensor->getImage();           // 1. Primeira captura
fp_sensor->image2Tz(1);          //    Guarda na gaveta 1

// Usuário remove e recoloca o dedo

fp_sensor->getImage();           // 2. Segunda captura  
fp_sensor->image2Tz(2);          //    Guarda na gaveta 2
fp_sensor->createModel();        // 3. Combina gaveta 1 + gaveta 2
fp_sensor->storeModel(100);      // 4. Salva como ID 100
```

---

### 🔍 BUSCAR (Search - 1:N)

**Objetivo**: "Quem é essa pessoa?" - busca em TODAS as digitais cadastradas.

**Fluxograma**:
```
┌─────────────────────────────────────────────┐
│ 1. Coloque o dedo                           │
│    └─► getImage() → image2Tz(slot=1)       │
├─────────────────────────────────────────────┤
│ 2. Buscar em TODO o banco de dados          │
│    └─► fingerFastSearch()                   │
│        ├─► Se encontrou: retorna ID         │
│        └─► Se não: ERROR_NO_MATCH           │
└─────────────────────────────────────────────┘
```

**O que acontece internamente?**
1. Sensor compara CharBuffer1 com TODOS os templates salvos
2. Se achar correspondência: retorna o ID + score de confiança
3. Se não achar ninguém: retorna ERROR_NO_MATCH

**Código**:
```cpp
// Método de alto nível
FingerprintMatch match;
FingerprintStatus status = fp_sensor->matchFingerprint(match);

if (status == FingerprintStatus::OK && match.matched) {
    printf("Encontrado: ID %d (confiança: %d)\n", match.id, match.confidence);
}

// Método de baixo nível
fp_sensor->getImage();
fp_sensor->image2Tz(1);
FingerprintMatch match;
fp_sensor->fingerFastSearch(match);  // Busca no banco todo
```

**Confiança (Confidence Score)**:
- Valor entre 0-65535 (quanto maior, melhor a correspondência)
- Valores típicos: 100-200 = boa correspondência
- Abaixo de 50 = duvidoso

---

### ✅ VERIFICAR (Verify - 1:1)

**Objetivo**: "Esse dedo é realmente do ID 100?" - compara com 1 digital específica.

**Diferença para BUSCAR**:
- **Buscar (Search)**: "Quem é você?" (compara com todos)
- **Verificar (Verify)**: "Você é o João (ID 100)?" (compara só com 1)

**Fluxograma**:
```
┌─────────────────────────────────────────────┐
│ 1. Coloque o dedo                           │
│    └─► getImage() → image2Tz(slot=1)       │
├─────────────────────────────────────────────┤
│ 2. Carregar template do ID específico       │
│    └─► loadTemplate(id, slot=2)            │
├─────────────────────────────────────────────┤
│ 3. Comparar gaveta 1 com gaveta 2           │
│    └─► compareTemplates()                   │
│        ├─► Match: retorna confiança         │
│        └─► No match: ERROR_NO_MATCH         │
└─────────────────────────────────────────────┘
```

**Código**:
```cpp
// Verificar se o dedo atual é do ID 100
fp_sensor->getImage();
fp_sensor->image2Tz(1);                    // Dedo atual → CharBuffer1
fp_sensor->loadTemplate(100, 2);           // ID 100 → CharBuffer2

uint16_t confidence = 0;
FingerprintStatus status = fp_sensor->compareTemplates(confidence);

if (status == FingerprintStatus::OK) {
    printf("Verificado! Confiança: %d\n", confidence);
} else {
    printf("NÃO é o ID 100\n");
}
```

---

## Gerenciamento do Banco de Dados

### Quantos templates estão salvos?
```cpp
uint16_t count;
fp_sensor->getTemplateCount(count);
printf("Total cadastrados: %d\n", count);
```

### Deletar uma digital específica
```cpp
fp_sensor->deleteModel(100);  // Deleta o ID 100
```

### Limpar TUDO
```cpp
fp_sensor->emptyDatabase();  // APAGA TODAS as digitais!
```

### Ver configurações do sensor
```cpp
uint16_t status_reg, sys_id, lib_size, sec_level;
fp_sensor->readSysPara(status_reg, sys_id, lib_size, sec_level);

printf("Capacidade: %d templates\n", lib_size);      // Ex: 1000
printf("Nível de segurança: %d\n", sec_level);       // 1-5 (quanto maior, mais rigoroso)
```

---

## Códigos de Status (Erros Comuns)

| Código | Nome | O que significa | O que fazer |
|---|---|---|---|
| `0x00` | `OK` | ✅ Sucesso | Tudo certo! |
| `0x02` | `ERROR_NO_FINGER` | Nenhum dedo detectado | Coloque o dedo no sensor |
| `0x06` | `ERROR_BAD_IMAGE` | Imagem não ficou boa | Limpe o dedo e tente de novo |
| `0x07` | `ERROR_TOO_MESSY` | Imagem muito confusa | Dedo pode estar sujo ou molhado |
| `0x08` | `ERROR_FEATURE_FAIL` | Não conseguiu extrair características | Pressione o dedo com mais força |
| `0x09` | `ERROR_NO_MATCH` | Nenhuma correspondência | Dedo não está cadastrado |
| `0x0A` | `ERROR_NOT_FOUND` ou `ERROR_MERGE_FAIL` | **No cadastro**: Os 2 scans estão muito diferentes<br>**Na busca**: ID não existe | Use a mesma posição do dedo<br>ou verifique se o ID existe |
| `0x10` | `ERROR_DELETE_FAIL` | Falha ao deletar | ID pode não existir |
| `0x11` | `ERROR_CLEAR_FAIL` | Falha ao limpar banco | Problema no sensor |
| `0xFF` | `ERROR_TIMEOUT` | Operação demorou muito | Verifique a conexão |

---

## 🔧 Configurações Importantes

**Nível de Segurança (1-5)**:
- **1**: Muito permissivo (aceita fácil, mais falsos positivos)
- **3**: Balanceado (padrão recomendado)
- **5**: Muito rigoroso (pode rejeitar o próprio dono)

**Baud Rate**:
- Padrão: 57600
- Pode ser mudado, mas 57600 é o mais confiável

**Capacidade**:
- R307S típico: 1000 templates
- Cada template ocupa ~512 bytes na memória do sensor

---

## Diferenças: Buscar vs Verificar

| Aspecto | **BUSCAR (Search)** | **VERIFICAR (Verify)** |
|---|---|---|
| **Pergunta** | "Quem é você?" | "Você é o João?" |
| **Compara com** | TODOS os templates | 1 template específico |
| **Função** | `fingerFastSearch()` | `loadTemplate() + compareTemplates()` |
| **Velocidade** | Mais lento (1-2 segundos) | Rápido (milissegundos) |
| **Uso típico** | Identificação (ex: relógio de ponto) | Autenticação (ex: confirmar senha) |
| **Retorna** | ID encontrado | Match/No match |

**Quando usar cada um?**

- **Search**: Quando você quer saber QUEM é a pessoa
  - Exemplo: Portaria, relógio de ponto, lista de presença
  
- **Verify**: Quando você já sabe QUEM deveria ser, só quer confirmar
  - Exemplo: "Confirme sua identidade para fazer esta operação", 2FA

---

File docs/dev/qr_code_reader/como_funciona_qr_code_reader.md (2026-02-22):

# Como Funciona o Sistema de Leitura QR Code (GM67)

## Índice
1. [Visão Geral](#visão-geral)
2. [Hardware - GM67](#hardware---gm67)
3. [Camada HAL - UART](#camada-hal---uart)
4. [Driver GM67](#driver-gm67)

---

## Visão Geral

O sistema é dividido em 2 camadas principais:

```
┌─────────────────────────────────────┐
│  DRIVER (gm67_driver.cpp)           │  ← Protocolo GM67
│  - Envia comandos AT para scanner   │
│  - Processa dados recebidos         │
│  - Chama callback quando lê QR      │
└─────────────────────────────────────┘
              ↓
┌─────────────────────────────────────┐
│  HAL (hal_uart_rp2040.cpp)          │  ← Hardware abstrato
│  - Envia/recebe bytes pela UART     │
│  - Específico do RP2040             │
└─────────────────────────────────────┘
              ↓
┌─────────────────────────────────────┐
│  HARDWARE (GM67 Scanner)            │  ← Dispositivo físico
└─────────────────────────────────────┘
```

**Por que essa separação?**
- **HAL**: Isola o hardware. Se trocar de microcontrolador (RP2040 → STM32), só muda o HAL.
- **Driver**: Isolado do hardware. Funciona em qualquer plataforma que tenha UART HAL.

---

## Hardware - GM67

### O que é?

O GM67 é um **módulo scanner de QR code e códigos de barras** que se comunica via UART (serial).

### Características

- **Comunicação**: UART (serial)
- **Velocidade padrão**: 115200 baud (alguns modelos vêm em 9600)
- **Protocolo**: Comandos AT (como modem)
- **Alimentação**: 5V 
- **Pinos Pico W**:
  - VCC (vermelho): 5V
  - GND (preto): terra
  - TX (branco): transmite dados para o scanner
  - RX (verde): recebe comandos do scanner

### Como funciona fisicamente?

1. **Você liga o scanner** (5V + GND)
2. **LED acende** (scanner está ligado)
3. **Aponta para um QR code**
4. **LED muda de cor/pisca** (está lendo)
5. **Scanner envia os dados pela UART** (pelo pino TX)
6. **Você recebe os dados** (pelo pino RX do microcontrolador)

### Modos de Operação

O GM67 tem 2 modos principais:

#### Modo 1: Contínuo (Auto-scan)
```
Scanner fica sempre ligado
    ↓
Aponta para QR code
    ↓
Lê automaticamente
    ↓
Envia dados pela UART
```

**Comando**: `AT+MODE=1\r\n`

#### Modo 2: Trigger (Sob demanda)
```
Scanner fica em standby
    ↓
Você envia comando AT+SCAN
    ↓
Scanner lê uma vez
    ↓
Volta para standby
```

**Comando**: `AT+MODE=0\r\n`

### Protocolo de Comunicação

O GM67 usa **comandos AT** (tipo modem antigo):

| Comando | Descrição |
|---|---|
| `AT+MODE=1\r\n` | Modo contínuo |
| `AT+MODE=0\r\n` | Modo trigger |
| `AT+SCAN\r\n` | Scan uma vez |
| `AT+STOP\r\n` | Para de escanear |

**Formato dos dados recebidos:**
```
DADOS_DO_QR_CODE\r\n
```

Exemplo: Se você escanear um QR com "TESTE123", o scanner envia:
```
T E S T E 1 2 3 \r \n
```

O `\r\n` (CR+LF) indica o fim dos dados.

---

## Camada HAL - UART

### O que é HAL?

HAL = **Hardware Abstraction Layer** (Camada de Abstração de Hardware)

**Propósito**: Esconder os detalhes do hardware para que o driver seja portável.

### Estrutura

```cpp
// Interface abstrata (não depende de hardware)
class HAL_UART_Interface {
    virtual bool init(baudrate, ...) = 0;
    virtual size_t write(data, len) = 0;
    virtual size_t read(data, len) = 0;
    virtual size_t available() = 0;
    // ...
};

// Implementação para RP2040
class HAL_UART_RP2040 : public HAL_UART_Interface {
    // Usa funções específicas do RP2040 SDK
    uart_init(uart_instance, baudrate);
    uart_write_blocking(...);
    uart_read_blocking(...);
};
```

### Como funciona?

1. **Você cria uma instância do HAL**
```cpp
HAL_UART_RP2040* uart = new HAL_UART_RP2040(uart1, GPIO_TX, GPIO_RX);
```

2. **Inicializa a UART com parâmetros**
```cpp
uart->init(
    115200,  // baudrate (velocidade)
    8,       // data bits
    1,       // stop bits
    0        // parity (sem paridade)
);
```

3. **HAL configura o hardware do RP2040**
```cpp
uart_init(uart1, 115200);
uart_set_format(uart1, 8, 1, UART_PARITY_NONE);
gpio_set_function(GPIO_TX, GPIO_FUNC_UART);
gpio_set_function(GPIO_RX, GPIO_FUNC_UART);
```

4. **Agora você pode usar métodos abstratos**
```cpp
uart->write(data, len);     // Envia bytes
uart->read(buffer, len);    // Recebe bytes
uart->available();          // Quantos bytes tem para ler
```

### Por que usar HAL?

**Sem HAL** (código acoplado ao hardware):
```cpp
// Driver diretamente usa funções do RP2040
uart_write_blocking(uart1, data, len);  // Só funciona no RP2040!
```

**Com HAL** (código portável):
```cpp
// Driver usa interface abstrata
uart_hal->write(data, len);  // Funciona em qualquer plataforma!
```

Se você trocar de microcontrolador (RP2040 → STM32), basta criar um novo HAL:
```cpp
class HAL_UART_STM32 : public HAL_UART_Interface {
    // Implementa com funções da STM32
    HAL_UART_Transmit(...);
    HAL_UART_Receive(...);
};
```

O driver **não muda nada**!

---

## Driver GM67

### O que faz?

O driver é responsável por:
1. Enviar comandos AT para o scanner
2. Receber dados da UART
3. Processar os dados (identificar fim de linha, etc.)
4. Chamar callback quando um QR code completo é lido

### Estrutura

```cpp
class GM67_Driver : public QR_Interface {
private:
    HAL_UART_Interface* uart_hal_;  // Interface abstrata (não sabe se é RP2040 ou STM32)
    ScanCallback scan_callback_;    // Função chamada quando lê QR
    char rx_buffer_[256];           // Buffer para dados recebidos
    size_t rx_index_;               // Posição atual no buffer
    
public:
    GM67_Driver(HAL_UART_Interface* uart_hal);
    
    bool init();
    bool setContinuousMode();
    void setScanCallback(ScanCallback callback);
    void process();
};
```

### Fluxo de Funcionamento

#### 1. Inicialização

```cpp
bool GM67_Driver::init() {
    // Limpa buffer UART (dados antigos)
    uart_hal_->clearRxBuffer();
    
    // Aguarda scanner estabilizar
    sleep_ms(100);
    
    is_initialized_ = true;
    return true;
}
```

**Não inicializa UART!** O HAL já foi inicializado antes.

#### 2. Configuração do Modo

```cpp
bool GM67_Driver::setContinuousMode() {
    return sendCommand("AT+MODE=1\r\n");
}

bool GM67_Driver::sendCommand(const char* command) {
    // Converte string para bytes
    // Envia pela UART usando o HAL
    uart_hal_->write((uint8_t*)command, strlen(command));
    uart_hal_->flush();
}
```

Quando você chama `setContinuousMode()`:
1. Driver monta o comando "AT+MODE=1\r\n"
2. Envia para o scanner via HAL
3. Scanner recebe e entra em modo contínuo

#### 3. Processamento de Dados

```cpp
void GM67_Driver::process() {
    // Verifica se tem bytes disponíveis na UART
    while (uart_hal_->available()) {
        // Lê um byte
        char ch = uart_hal_->readByte();
        
        // Processa o caractere
        processChar(ch);
    }
}
```

```cpp
void GM67_Driver::processChar(char ch) {
    // Se é fim de linha (\r ou \n)
    if (ch == '\r' || ch == '\n') {
        if (rx_index_ > 0) {
            // Termina a string
            rx_buffer_[rx_index_] = '\0';
            
            // Chama callback com os dados
            handleScanComplete();
            
            // Reseta buffer para próxima leitura
            rx_index_ = 0;
        }
        return;
    }
    
    // Adiciona caractere ao buffer
    if (rx_index_ < BUFFER_SIZE - 1) {
        rx_buffer_[rx_index_++] = ch;
    }
}
```

**Exemplo prático:**

Scanner lê QR code "TESTE" e envia: `T E S T E \r \n`

```
Byte recebido: 'T'  → rx_buffer_ = "T"       rx_index_ = 1
Byte recebido: 'E'  → rx_buffer_ = "TE"      rx_index_ = 2
Byte recebido: 'S'  → rx_buffer_ = "TES"     rx_index_ = 3
Byte recebido: 'T'  → rx_buffer_ = "TEST"    rx_index_ = 4
Byte recebido: 'E'  → rx_buffer_ = "TESTE"   rx_index_ = 5
Byte recebido: '\r' → Fim! Chama callback com "TESTE"
```

#### 4. Callback

```cpp
void GM67_Driver::handleScanComplete() {
    if (scan_callback_) {
        std::string data(rx_buffer_, rx_index_);
        scan_callback_(data);  // Chama sua função!
    }
}
```
---

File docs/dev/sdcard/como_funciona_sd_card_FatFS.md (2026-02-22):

# Como Usar SD Card com FatFS no RP2040

## 📖 O que é FatFS?

**FatFS** é uma biblioteca de sistema de arquivos FAT/exFAT genérica e completa para sistemas embarcados. Ela permite que você trabalhe com cartões SD da mesma forma que trabalha com arquivos em um computador - criar, ler, escrever, deletar arquivos e diretórios.

**Biblioteca usada:** [carlk3/no-OS-FatFS-SD-SPI-RPi-Pico](https://github.com/carlk3/no-OS-FatFS-SD-SPI-RPi-Pico)
- ✅ Produção-ready
- ✅ Thread-safe para FreeRTOS
- ✅ Suporte completo a FAT32
- ✅ API padrão POSIX-like

---

## 🔌 Configuração de Hardware

### Pinagem do SD Card

Seu projeto está configurado com os seguintes pinos (veja `config/hw_config.c`):

| Sinal | GPIO | Descrição |
|---|---|---|
| MISO  | 12 | Master In Slave Out (dados do SD para Pico) |
| MOSI  | 15 | Master Out Slave In (dados do Pico para SD) |
| SCK | 14 | SPI Clock (sincronização) |
| CS | 13 | Chip Select (habilita o SD card) |

### Preparando o SD Card

1. **Formate como FAT32** (importante!)
2. Insira no módulo SD
3. Conecte os pinos conforme a tabela acima

---

## 🚀 Inicialização Básica

### Passo 1: Incluir os Headers

```cpp
#include "f_util.h"      // Utilitários do FatFS
#include "ff.h"          // API principal do FatFS
#include "hw_config.h"   // Configuração de hardware
```

### Passo 2: Montar o Sistema de Arquivos

Antes de fazer qualquer operação, você precisa **montar** o SD card:

```cpp
// Obter a instância do SD card (definida em hw_config.c)
sd_card_t *pSD = sd_get_by_num(0);  // 0 = primeiro (e único) SD card

// Montar o filesystem
FRESULT fr = f_mount(&pSD->fatfs, pSD->pcName, 1);

if (FR_OK != fr) {
    printf("ERRO ao montar: %s (%d)\n", FRESULT_str(fr), fr);
    // Verifique: SD inserido? Formatado FAT32? Fiação correta?
} else {
    printf("SD card montado com sucesso!\n");
}
```

**O que acontece aqui:**
- `sd_get_by_num(0)` - Pega a configuração do SD card definida em `hw_config.c`
- `f_mount()` - Monta o sistema de arquivos FAT
- `FR_OK` - Código de retorno indicando sucesso

---

## 📝 Operações Comuns com Arquivos

### 1. Criar e Escrever em um Arquivo

```cpp
FIL fil;  // Estrutura de arquivo
FRESULT fr;

// Abrir arquivo para escrita (cria se não existir)
fr = f_open(&fil, "dados.txt", FA_WRITE | FA_CREATE_ALWAYS);

if (FR_OK == fr) {
    // Escrever usando f_printf (similar ao printf)
    f_printf(&fil, "Paciente: João Silva\n");
    f_printf(&fil, "ID: 12345\n");
    f_printf(&fil, "Data: 09/11/2025\n");
    
    // Sempre fechar o arquivo!
    f_close(&fil);
    printf("Arquivo criado com sucesso!\n");
} else {
    printf("Erro ao criar arquivo: %s\n", FRESULT_str(fr));
}
```

**Modos de abertura disponíveis:**
- `FA_READ` - Somente leitura
- `FA_WRITE` - Somente escrita
- `FA_CREATE_NEW` - Cria novo (falha se já existe)
- `FA_CREATE_ALWAYS` - Cria novo (sobrescreve se existe)
- `FA_OPEN_ALWAYS` - Abre existente ou cria novo
- `FA_OPEN_APPEND` - Abre para adicionar no final

Você pode combinar com `|`:
```cpp
FA_WRITE | FA_CREATE_ALWAYS  // Escrever, criar novo (sobrescreve)
FA_WRITE | FA_OPEN_APPEND    // Escrever no final do arquivo
```

### 2. Ler um Arquivo Linha por Linha

```cpp
FIL fil;
FRESULT fr;

fr = f_open(&fil, "dados.txt", FA_READ);

if (FR_OK == fr) {
    char linha[128];
    
    // Ler linha por linha até o fim do arquivo
    while (f_gets(linha, sizeof(linha), &fil)) {
        printf("Lido: %s", linha);  // linha já inclui \n
    }
    
    f_close(&fil);
} else {
    printf("Erro ao abrir arquivo: %s\n", FRESULT_str(fr));
}
```

### 3. Ler Bytes Específicos

```cpp
FIL fil;
FRESULT fr;

fr = f_open(&fil, "dados.bin", FA_READ);

if (FR_OK == fr) {
    uint8_t buffer[512];
    UINT bytes_lidos;
    
    // Ler até 512 bytes
    fr = f_read(&fil, buffer, sizeof(buffer), &bytes_lidos);
    
    if (FR_OK == fr) {
        printf("Lidos %u bytes\n", bytes_lidos);
        // Use os dados em buffer...
    }
    
    f_close(&fil);
}
```

### 4. Adicionar Dados no Final (Append)

```cpp
FIL fil;
FRESULT fr;

// Abrir para append - adiciona no final sem apagar o conteúdo
fr = f_open(&fil, "log.txt", FA_WRITE | FA_OPEN_APPEND);

if (FR_OK == fr) {
    // Obter timestamp atual (você precisa implementar isso)
    uint32_t tempo_ms = to_ms_since_boot(get_absolute_time());
    
    f_printf(&fil, "[%lu] Paciente check-in realizado\n", tempo_ms);
    
    f_close(&fil);
}
```

**Exemplo prático - Log de eventos:**

```cpp
void salvar_log(const char* mensagem) {
    FIL fil;
    
    if (f_open(&fil, "eventos.log", FA_WRITE | FA_OPEN_APPEND) == FR_OK) {
        uint32_t tempo = to_ms_since_boot(get_absolute_time());
        f_printf(&fil, "[%lu ms] %s\n", tempo, mensagem);
        f_close(&fil);
    }
}

// Uso:
salvar_log("Sistema iniciado");
salvar_log("Leitor QR conectado");
salvar_log("Paciente 12345 fez check-in");
```

### 5. Escrever Dados Binários

```cpp
FIL fil;
FRESULT fr;

// Estrutura de exemplo
struct Paciente {
    uint32_t id;
    char nome[64];
    uint8_t idade;
};

Paciente p = {12345, "João Silva", 45};

fr = f_open(&fil, "paciente.dat", FA_WRITE | FA_CREATE_ALWAYS);

if (FR_OK == fr) {
    UINT bytes_escritos;
    
    // Escrever estrutura inteira
    fr = f_write(&fil, &p, sizeof(Paciente), &bytes_escritos);
    
    if (FR_OK == fr && bytes_escritos == sizeof(Paciente)) {
        printf("Dados binários salvos: %u bytes\n", bytes_escritos);
    }
    
    f_close(&fil);
}
```

---

## 📁 Operações com Arquivos e Diretórios

### 6. Verificar se Arquivo Existe

```cpp
FILINFO fno;
FRESULT fr;

fr = f_stat("arquivo.txt", &fno);

if (FR_OK == fr) {
    printf("Arquivo existe!\n");
    printf("Tamanho: %lu bytes\n", (unsigned long)fno.fsize);
} else if (FR_NO_FILE == fr) {
    printf("Arquivo não existe\n");
}
```

### 7. Obter Informações do Arquivo

```cpp
FILINFO fno;

if (f_stat("dados.txt", &fno) == FR_OK) {
    printf("Nome: %s\n", fno.fname);
    printf("Tamanho: %lu bytes\n", (unsigned long)fno.fsize);
    
    // Data de modificação
    int ano = 1980 + ((fno.fdate >> 9) & 0x7F);
    int mes = (fno.fdate >> 5) & 0x0F;
    int dia = fno.fdate & 0x1F;
    printf("Data: %04d-%02d-%02d\n", ano, mes, dia);
    
    // Hora de modificação
    int hora = (fno.ftime >> 11) & 0x1F;
    int min = (fno.ftime >> 5) & 0x3F;
    int seg = (fno.ftime & 0x1F) * 2;
    printf("Hora: %02d:%02d:%02d\n", hora, min, seg);
    
    // Atributos
    if (fno.fattrib & AM_DIR) printf("É um diretório\n");
    if (fno.fattrib & AM_RDO) printf("Somente leitura\n");
    if (fno.fattrib & AM_HID) printf("Oculto\n");
}
```

### 8. Deletar um Arquivo

```cpp
FRESULT fr = f_unlink("arquivo_velho.txt");

if (FR_OK == fr) {
    printf("Arquivo deletado\n");
} else {
    printf("Erro ao deletar: %s\n", FRESULT_str(fr));
}
```

### 9. Renomear/Mover Arquivo

```cpp
// Renomear
FRESULT fr = f_rename("nome_velho.txt", "nome_novo.txt");

// Mover para diretório
fr = f_rename("arquivo.txt", "pasta/arquivo.txt");
```

### 10. Criar Diretório

```cpp
FRESULT fr = f_mkdir("pacientes");

if (FR_OK == fr) {
    printf("Diretório criado\n");
} else if (FR_EXIST == fr) {
    printf("Diretório já existe\n");
}
```

### 11. Listar Arquivos de um Diretório

```cpp
DIR dir;
FILINFO fno;
FRESULT fr;

// Abrir diretório raiz
fr = f_opendir(&dir, "/");

if (FR_OK == fr) {
    printf("Conteúdo do SD card:\n");
    
    // Ler cada entrada
    while (true) {
        fr = f_readdir(&dir, &fno);
        
        // Parar quando não houver mais entradas
        if (fr != FR_OK || fno.fname[0] == 0) break;
        
        // Mostrar informação
        if (fno.fattrib & AM_DIR) {
            printf("  [DIR]  %s\n", fno.fname);
        } else {
            printf("  [FILE] %-20s %8lu bytes\n", 
                   fno.fname, (unsigned long)fno.fsize);
        }
    }
    
    f_closedir(&dir);
}
```

**Listar diretório específico:**

```cpp
DIR dir;
FILINFO fno;

if (f_opendir(&dir, "pacientes") == FR_OK) {
    while (f_readdir(&dir, &fno) == FR_OK && fno.fname[0] != 0) {
        printf("%s\n", fno.fname);
    }
    f_closedir(&dir);
}
```

---

## 💾 Informações de Armazenamento

### 12. Espaço Livre no SD Card

```cpp
FATFS *fs;
DWORD clusters_livres;
FRESULT fr;

// Obter informações do filesystem
fr = f_getfree("0:", &clusters_livres, &fs);

if (FR_OK == fr) {
    // Calcular setores
    DWORD total_setores = (fs->n_fatent - 2) * fs->csize;
    DWORD setores_livres = clusters_livres * fs->csize;
    
    // Converter para MB (cada setor = 512 bytes)
    DWORD total_mb = total_setores / 2048;
    DWORD livre_mb = setores_livres / 2048;
    DWORD usado_mb = total_mb - livre_mb;
    
    printf("SD Card:\n");
    printf("  Total: %lu MB\n", total_mb);
    printf("  Livre: %lu MB\n", livre_mb);
    printf("  Usado: %lu MB\n", usado_mb);
    
    // Percentual de uso
    float uso_pct = ((total_setores - setores_livres) * 100.0f) / total_setores;
    printf("  Uso: %.1f%%\n", uso_pct);
}
```

---

## 🎯 Exemplos Práticos para Sistema Médico

### Exemplo 1: Salvar Check-in em CSV

```cpp
bool salvar_checkin(const char* paciente_id, const char* nome) {
    FIL fil;
    
    // Abrir CSV em modo append
    FRESULT fr = f_open(&fil, "checkins.csv", FA_WRITE | FA_OPEN_APPEND);
    
    if (FR_OK != fr) {
        // Se falhou, talvez seja porque não existe - criar com cabeçalho
        fr = f_open(&fil, "checkins.csv", FA_WRITE | FA_CREATE_NEW);
        if (FR_OK == fr) {
            f_printf(&fil, "Timestamp,ID_Paciente,Nome,Status\n");
        } else {
            return false;
        }
    }
    
    // Obter timestamp
    uint32_t tempo_ms = to_ms_since_boot(get_absolute_time());
    
    // Escrever linha do CSV
    f_printf(&fil, "%lu,%s,%s,CHECKED_IN\n", tempo_ms, paciente_id, nome);
    
    f_close(&fil);
    return true;
}

// Uso:
salvar_checkin("12345", "João Silva");
salvar_checkin("67890", "Maria Santos");
```

### Exemplo 2: Salvar Dados de Paciente

```cpp
bool salvar_dados_paciente(const char* id, const char* dados_json) {
    FIL fil;
    char caminho[80];
    
    // Garantir que diretório existe
    f_mkdir("pacientes");
    
    // Criar nome do arquivo
    snprintf(caminho, sizeof(caminho), "pacientes/%s.json", id);
    
    // Salvar arquivo JSON
    FRESULT fr = f_open(&fil, caminho, FA_WRITE | FA_CREATE_ALWAYS);
    
    if (FR_OK == fr) {
        f_printf(&fil, "%s", dados_json);
        f_close(&fil);
        return true;
    }
    
    return false;
}

// Uso:
const char* dados = "{\n"
    "  \"id\": \"12345\",\n"
    "  \"nome\": \"João Silva\",\n"
    "  \"idade\": 45,\n"
    "  \"telefone\": \"11-98765-4321\"\n"
    "}";
    
salvar_dados_paciente("12345", dados);
```

### Exemplo 3: Ler Dados de Paciente

```cpp
bool ler_dados_paciente(const char* id, char* buffer, size_t buffer_size) {
    FIL fil;
    char caminho[80];
    
    snprintf(caminho, sizeof(caminho), "pacientes/%s.json", id);
    
    FRESULT fr = f_open(&fil, caminho, FA_READ);
    
    if (FR_OK == fr) {
        UINT bytes_lidos;
        fr = f_read(&fil, buffer, buffer_size - 1, &bytes_lidos);
        
        if (FR_OK == fr) {
            buffer[bytes_lidos] = '\0';  // Terminar string
            f_close(&fil);
            return true;
        }
        
        f_close(&fil);
    }
    
    return false;
}

// Uso:
char dados[512];
if (ler_dados_paciente("12345", dados, sizeof(dados))) {
    printf("Dados do paciente:\n%s\n", dados);
}
```

### Exemplo 4: Classe Gerenciadora de Logs

```cpp
class LogManager {
public:
    LogManager(const char* arquivo_log) : arquivo_(arquivo_log) {
        // Montar SD card
        sd_card_t *pSD = sd_get_by_num(0);
        FRESULT fr = f_mount(&pSD->fatfs, pSD->pcName, 1);
        montado_ = (FR_OK == fr);
    }
    
    bool log(const char* nivel, const char* mensagem) {
        if (!montado_) return false;
        
        FIL fil;
        FRESULT fr = f_open(&fil, arquivo_, FA_WRITE | FA_OPEN_APPEND);
        
        if (FR_OK != fr) return false;
        
        uint32_t tempo = to_ms_since_boot(get_absolute_time());
        f_printf(&fil, "[%lu][%s] %s\n", tempo, nivel, mensagem);
        
        f_close(&fil);
        return true;
    }
    
    bool info(const char* msg) { return log("INFO", msg); }
    bool warning(const char* msg) { return log("WARN", msg); }
    bool error(const char* msg) { return log("ERROR", msg); }
    
private:
    const char* arquivo_;
    bool montado_;
};

// Uso:
LogManager logger("sistema.log");
logger.info("Sistema iniciado");
logger.info("QR Scanner conectado");
logger.warning("Fingerprint sensor não respondendo");
logger.error("Falha ao salvar dados");
```

---

## ⚠️ Tratamento de Erros

### Códigos de Retorno Comuns

```cpp
FRESULT fr = f_open(&fil, "arquivo.txt", FA_READ);

switch (fr) {
    case FR_OK:
        printf("Sucesso\n");
        break;
    case FR_NO_FILE:
        printf("Arquivo não encontrado\n");
        break;
    case FR_NO_PATH:
        printf("Caminho não encontrado\n");
        break;
    case FR_DENIED:
        printf("Acesso negado\n");
        break;
    case FR_DISK_ERR:
        printf("Erro no disco\n");
        break;
    case FR_NOT_READY:
        printf("SD card não está pronto\n");
        break;
    default:
        printf("Erro: %s (%d)\n", FRESULT_str(fr), fr);
        break;
}
```

### Função Helper para Erros

```cpp
const char* obter_mensagem_erro(FRESULT fr) {
    switch (fr) {
        case FR_OK: return "Sucesso";
        case FR_DISK_ERR: return "Erro de disco";
        case FR_INT_ERR: return "Erro interno";
        case FR_NOT_READY: return "Disco não está pronto";
        case FR_NO_FILE: return "Arquivo não encontrado";
        case FR_NO_PATH: return "Caminho não encontrado";
        case FR_INVALID_NAME: return "Nome de arquivo inválido";
        case FR_DENIED: return "Acesso negado";
        case FR_EXIST: return "Já existe";
        case FR_INVALID_OBJECT: return "Objeto inválido";
        case FR_WRITE_PROTECTED: return "Protegido contra escrita";
        case FR_INVALID_DRIVE: return "Drive inválido";
        case FR_NOT_ENABLED: return "Não habilitado";
        case FR_NO_FILESYSTEM: return "Sem sistema de arquivos";
        default: return "Erro desconhecido";
    }
}
```

---

## 🔒 Uso com FreeRTOS (Multi-threading)

### Proteger Acesso com Mutex

Se você usa FatFS em múltiplas tasks, proteja com mutex:

```cpp
#include "FreeRTOS.h"
#include "semphr.h"

// Mutex global
static SemaphoreHandle_t sd_mutex = NULL;

// Inicializar no início
void inicializar_sd() {
    sd_mutex = xSemaphoreCreateMutex();
    
    // Montar filesystem...
}

// Usar em cada operação
bool escrever_log_seguro(const char* mensagem) {
    bool sucesso = false;
    
    // Adquirir mutex (espera até 1 segundo)
    if (xSemaphoreTake(sd_mutex, pdMS_TO_TICKS(1000)) == pdTRUE) {
        
        // Operação segura aqui
        FIL fil;
        if (f_open(&fil, "log.txt", FA_WRITE | FA_OPEN_APPEND) == FR_OK) {
            f_printf(&fil, "%s\n", mensagem);
            f_close(&fil);
            sucesso = true;
        }
        
        // Liberar mutex
        xSemaphoreGive(sd_mutex);
    }
    
    return sucesso;
}
```

---

## 🧪 Testando o SD Card

Veja o arquivo demo completo em: `src/tests/code_examples/sdcard_fatfs_demo.cpp`

Para rodar o demo:

1. Edite `CMakeLists.txt` na raiz do projeto:
```cmake
set(BUILD_TARGET "SDCARD_DEMO" CACHE STRING "...")
```

2. Compile e faça upload
3. Abra o monitor serial
4. Veja os testes sendo executados

---

## 📚 Referências

- **FatFS Official**: http://elm-chan.org/fsw/ff/00index_e.html
- **carlk3's Library**: https://github.com/carlk3/no-OS-FatFS-SD-SPI-RPi-Pico
- **Demo completo**: `src/tests/code_examples/sdcard_fatfs_demo.cpp`
- **Configuração HW**: `config/hw_config.c`

---

## 🎓 Resumo das Funções Mais Usadas

| Operação | Função | Exemplo |
|---|---|---|
| Montar SD | `f_mount()` | `f_mount(&fs, "0:", 1)` |
| Abrir arquivo | `f_open()` | `f_open(&fil, "file.txt", FA_READ)` |
| Fechar arquivo | `f_close()` | `f_close(&fil)` |
| Ler bytes | `f_read()` | `f_read(&fil, buf, 100, &br)` |
| Ler linha | `f_gets()` | `f_gets(linha, 128, &fil)` |
| Escrever bytes | `f_write()` | `f_write(&fil, data, len, &bw)` |
| Escrever formatado | `f_printf()` | `f_printf(&fil, "ID: %d\n", id)` |
| Info do arquivo | `f_stat()` | `f_stat("file.txt", &fno)` |
| Deletar | `f_unlink()` | `f_unlink("old.txt")` |
| Renomear | `f_rename()` | `f_rename("a.txt", "b.txt")` |
| Criar diretório | `f_mkdir()` | `f_mkdir("pasta")` |
| Abrir diretório | `f_opendir()` | `f_opendir(&dir, "/")` |
| Ler entrada dir | `f_readdir()` | `f_readdir(&dir, &fno)` |
| Espaço livre | `f_getfree()` | `f_getfree("0:", &free, &fs)` |

**Pronto! Agora você sabe como usar FatFS para todas as operações comuns de arquivo! 🎉**

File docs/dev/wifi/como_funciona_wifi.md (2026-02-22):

# WiFi no Raspberry Pi Pico W - Como Funciona

## Visão Geral

O Pico W possui o chip **CYW43439** que fornece conectividade WiFi 802.11n (2.4 GHz). A implementação usa:
- **SDK Pico** (versão 2.1.1) com driver CYW43
- **lwIP** (Lightweight IP stack) para TCP/IP
- **FreeRTOS** para multitarefa
- **HAL WiFi** (camada de abstração de hardware)

## Arquitetura

```
HAL WiFi (hal_wifi_rp2040.cpp)
         ↓
SDK CYW43 (pico_cyw43_arch_lwip_sys_freertos)
         ↓
lwIP Stack (TCP/IP)
         ↓
Driver CYW43439 (Hardware WiFi)
```

## Componentes Principais

### 1. HAL WiFi (`hal_wifi_rp2040.cpp`)

Camada de abstração que encapsula todas as funções do CYW43 SDK:

**Funções principais:**
- `init()` - Inicializa o chip WiFi com código de país
- `connect()` - Conecta a uma rede WiFi
- `disconnect()` - Desconecta da rede
- `scanNetworks()` - Escaneia redes disponíveis
- `getIPAddress()` - Obtém endereço IP
- `getMACAddress()` - Obtém endereço MAC
- `getRSSI()` - Mede intensidade do sinal
- `testDNSConnectivity()` - Testa resolução DNS
- `setHostname()` - Define nome do dispositivo
- `startAP()` / `stopAP()` - Modo Access Point
- `setLED()` - Controla LED do Pico W

**Características:**
- Thread-safe para FreeRTOS
- Retorna `bool` ou códigos de erro claros

### 2. lwIP Configuration (`lwipopts.h`)

Configurações críticas da pilha TCP/IP:

```c
#define MEM_SIZE                    20000   // Pool de memória (20KB) CRÍTICO
#define PBUF_POOL_SIZE              48      // Buffers de pacotes
#define MEMP_NUM_TCP_PCB            10      // Conexões TCP simultâneas
#define LWIP_NETCONN                1       // API Netconn habilitada
#define TCPIP_THREAD_STACKSIZE      1024    // Stack da thread TCP/IP
#define DEFAULT_THREAD_STACKSIZE    1024    // Stack padrão
```

### 3. FreeRTOS Integration

A biblioteca `pico_cyw43_arch_lwip_sys_freertos` integra:
- lwIP roda em thread separada (TCPIP thread)
- WiFi **deve** ser inicializado **após** `vTaskStartScheduler()`
- Callbacks são executados no contexto FreeRTOS

## Fluxo de Inicialização

### Passo 1: Inicialização
```cpp
wifi_hal = new HAL_WiFi_RP2040();
wifi_hal->init("BR");  // Código de país (Brasil)
```

**Internamente:**
1. `cyw43_arch_init_with_country()` - Inicializa driver
2. `cyw43_arch_enable_sta_mode()` - Ativa modo estação
3. Carrega firmware CYW43439
4. Configura país para conformidade regulatória

### Passo 2: Conexão
```cpp
wifi_hal->connect(SSID, PASSWORD, WiFiSecurityMode::WPA2_AES_PSK, 30000);
```

**Internamente:**
1. `cyw43_arch_wifi_connect_async()` - Inicia conexão assíncrona
2. Aguarda conexão com timeout
3. DHCP obtém endereço IP automaticamente
4. Retorna `true` se conectado

### Passo 3: Uso da Rede

Após conectado, usa-se APIs lwIP:
- **DNS:** `dns_gethostbyname()`
- **TCP:** `tcp_new()`, `tcp_connect()`, `tcp_write()`
- **UDP:** `udp_new()`, `udp_sendto()`

## Modos de Operação

### Station Mode (Cliente WiFi)
```cpp
wifi_hal->init("BR");
wifi_hal->connect("MinhaRede", "senha123", WiFiSecurityMode::WPA2_AES_PSK);
```

### Access Point Mode (Servidor WiFi)
```cpp
wifi_hal->init("BR");
wifi_hal->startAP("PicoW-AP", "senha123", WiFiSecurityMode::WPA2_AES_PSK, 6);
```

## Scan de Redes

```cpp
WiFiNetworkInfo networks[10];
int32_t count = wifi_hal->scanNetworks(networks, 10, 10000);

for (int i = 0; i < count; i++) {
    printf("SSID: %s, RSSI: %d dBm, Canal: %d\n", 
           networks[i].ssid, networks[i].rssi, networks[i].channel);
}
```

**Tipos de Segurança:**
- `OPEN` - Sem senha
- `WPA_TKIP_PSK` - WPA1
- `WPA2_AES_PSK` - WPA2 (mais comum)
- `WPA2_MIXED_PSK` - WPA2 modo misto

## DNS e Conectividade

```cpp
// Testa resolução DNS
if (wifi_hal->testDNSConnectivity("google.com", 5000)) {
    printf("DNS funcionando!\n");
}
```

Internamente usa `dns_gethostbyname()` para resolver hostname → IP.

## TCP Echo Server (Exemplo)

```cpp
struct tcp_pcb* pcb = tcp_new();
tcp_bind(pcb, IP_ADDR_ANY, 7);  // Porta 7
pcb = tcp_listen(pcb);
tcp_accept(pcb, accept_callback);

// Cliente conecta: telnet <pico-ip> 7
```

## Indicador LED

O LED do Pico W está conectado ao chip CYW43:

```cpp
wifi_hal->setLED(true);   // Acende
wifi_hal->setLED(false);  // Apaga
```

**Nota:** LED só funciona **após** `init()` WiFi.

## Medição de Sinal (RSSI)

```cpp
int32_t rssi = wifi_hal->getRSSI();
printf("Sinal: %d dBm\n", rssi);
```

**Valores típicos:**
- -30 a -50 dBm: Excelente
- -50 a -70 dBm: Bom
- -70 a -80 dBm: Fraco
- < -80 dBm: Muito fraco

## Configuração de País

Obrigatório para conformidade regulatória:

```cpp
wifi_hal->init("BR");  // Brasil
wifi_hal->init("US");  // Estados Unidos
wifi_hal->init("JP");  // Japão
```

Define canais WiFi permitidos e potência máxima de transmissão.

## Troubleshooting

### Problema: Panic "size > 0"
**Causa:** `MEM_SIZE` muito pequeno em `lwipopts.h`  
**Solução:** Aumentar para `20000` ou mais

### Problema: WiFi não inicializa
**Causa:** Inicialização antes do scheduler FreeRTOS  
**Solução:** Chamar `init()` dentro de uma task FreeRTOS

### Problema: Conexão timeout
**Causas possíveis:**
- SSID ou senha incorretos
- Rede fora de alcance (RSSI < -80 dBm)
- Modo de segurança incompatível
- Timeout muito curto (< 15000 ms)

### Problema: DNS falha
**Causas possíveis:**
- Não conectado à rede
- Servidor DNS não configurado
- Firewall bloqueando porta 53

## Referências

- **Pico SDK:** https://github.com/raspberrypi/pico-sdk
- **CYW43 Driver:** Incluído no Pico SDK
- **lwIP:** https://savannah.nongnu.org/projects/lwip/
- **Datasheet CYW43439:** Broadcom/Infineon
- **HAL WiFi:** `/src/hal/rp2040/hal_wifi_rp2040.cpp`
- **Config lwIP:** `/config/lwipopts.h`

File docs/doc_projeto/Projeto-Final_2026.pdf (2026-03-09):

## Instituto Hardware BR Programa EmbarcaTech

# Projeto 1:

# Controle de Acesso (Check-In): DOCUMENTAÇÃO

## Adriana Rocha Castro de Paula Luana Maria da Silva Menezes

## Turma Campinas - 2026

# Sumário

1. SISTEMA EMBARCADO | 5
1.1. Introdução | 5
1.1.1. Contextualização | 5
1.1.2. Definição do Problema | 5
1.1.3. Objetivos | 5
1.1.4. Justificativa | 6
1.2. Fundamentação Teórica | 6
1.2.1. Sistemas Embarcados | 7
1.2.2. Sistemas Operacionais de Tempo Real (RTOS) | 7
1.2.3. Arquitetura de Software em Camadas | 7
1.2.4. Padrões de Projeto Utilizados | 8
1.2.5. Interface Gráfica Embarcada | 8
1.3. Metodologia | 9
1.3.1. Abordagem de Desenvolvimento | 9
1.3.2. Ferramentas Utilizadas | 9
1.3.3. Bibliotecas Externas | 9
1.4. Especificação de Requisitos | 10
1.4.1. Requisitos Funcionais | 10
1.4.2. Requisitos Não-Funcionais | 11
1.5. Arquitetura do Sistema | 11
1.5.1. Arquitetura de Hardware | 11
1.5.2. Arquitetura de Software | 12
1.6. Implementação | 13
1.6.1. Estrutura do Projeto | 13
1.6.2. Controle de Versão | 15
1.7. Testes e Validação | 15
1.7.1. Estratégia de Testes | 15
1.7.2. Demos Standalone | 16
1.7.3. Testes Integrados | 16
1.8. Resultados | 16
1.8.1. Funcionalidades Implementadas | 16
1.8.2. Nível de Maturidade Tecnológica (TRL) | 17
2. AGENDAMENTOS DE CONSULTAS POR WEB API E BOT DO TELEGRAM | 18
2.1. INTRODUÇÃO | 18
2.2. ARQUITETURA DO SISTEMA | 19
2.2.1. Componentes Principais | 19
2.2.2. Stack Tecnológico | 19
2.3. API REST | 19
2.3.1. Visão Geral | 19
2.3.2. Autenticação e Segurança | 19

2.3.3. Estrutura de Dados | 20
2.3.3.1. Pacientes | 20
2.3.3.2. Categorias | 20
2.3.3.3. Profissionais | 20
2.3.3.4. Horários Profissionais | 20
2.3.3.5. Consultas | 21
2.4. BOT TELEGRAM | 21
2.4.1. Visão Geral | 21
2.4.2. Funcionalidades | 21
2.4.2.1. Comandos Disponíveis | 21
2.4.3. Fluxo de Agendamento | 22
3. INTEGRAÇÃO WEB API COM SISTEMA EMBARCADO | 23
3.1. Visão Geral da Integração | 23
3.2. Arquitetura de Integração | 23
4. PROTÓTIPO FÍSICO | 23
5. TRABALHOS FUTUROS | 24
6. CONCLUSÃO | 25
7. APÊNDICE A: Manual do Usuário | 26
7.1. Manual do usuário do bot de agendamento | 26
7.1.1. Sobre o Bot | 26
7.1.2. Como Iniciar | 26
7.1.3. Como Agendar uma Consulta | 26
7.1.4. Como Recuperar o QR Code de uma Consulta | 28
7.1.5. Capturas de Tela do Agendamento por Telegram | 28
7.2. Manual do usuário Totem de Check-in (Sistema Embarcado) | 30
8. APÊNDICE B: Documentação Técnica | 33
8.1. Protocolos de Comunicação | 33
8.2. Detalhes de Implementação (HAL, Drivers, Serviços, Tasks) | 34
8.2.1. Camada HAL (Hardware Abstraction Layer) | 34
8.3. Camada de Drivers | 35
8.4. Camada de Serviços | 36
8.5. Camada de Aplicação | 38
8.6. API REST Completa (endpoints, banco) | 40
8.6.1. Endpoints da API | 40
8.6.1.1. Autenticação | 40
8.6.1.2. Pacientes | 40
8.6.1.3. Categorias | 41
8.6.1.4. Profissionais | 42
8.6.1.5. Horários Profissionais | 43
8.6.1.6. Consultas | 43
8.6.1.7. QR Code | 45
8.6.2. Tratamento de Erros | 45

8.6.3. Padrões Arquiteturais | 46
8.6.4. BANCO DE DADOS | 46
8.6.4.1. Sistema de Gerenciamento | 46
8.6.4.2. Diagrama de Relacionamentos | 46
8.6.4.3. Migrations | 46
8.7. BOT TELEGRAM | 46
8.7.1. Integração com API | 46
8.7.2. Tratamento de Erros | 47
8.7.3. Experiência do Usuário | 47
8.8. Integração (detalhes de comunicação embarcado-API) | 47
8.8.1. Endpoints Relevantes para Integração | 47
8.8.2. Protocolo de Comunicação | 48
8.8.3. Segurança na Integração | 48
8.9. Protótipo Físico - Fotos | 49
8.10. Capturas de Tela do Sistema | 51
9. REFERÊNCIAS | 56

# 1. SISTEMA EMBARCADO

# 1.1. Introdução

## 1.1.1. Contextualização

O setor de saúde enfrenta desafios constantes relacionados à gestão do fluxo de pacientes em clínicas

e consultórios médicos. O processo tradicional de check-in, realizado manualmente por recepcionistas,

frequentemente resulta em filas de espera, erros de identificação e sobrecarga da equipe

administrativa. Com o avanço da tecnologia embarcada e a popularização de dispositivos de

autoatendimento, torna-se viável o desenvolvimento de soluções que automatizam e agilizam esse

processo.

Neste contexto, os sistemas embarcados apresentam-se como uma alternativa de baixo custo e alta

confiabilidade para a implementação de totens de autoatendimento. A utilização de

microcontroladores modernos, como o Raspberry Pi Pico W, aliada a sistemas operacionais de tempo

real (RTOS), permite o desenvolvimento de aplicações responsivas e robustas, capazes de operar de

forma autônoma em ambientes clínicos.

## 1.1.2. Definição do Problema

O processo convencional de check-in em clínicas médicas apresenta diversas limitações:

- Filas de espera: Pacientes aguardam atendimento na recepção, especialmente em horários de pico;
- Erros de identificação: A conferência manual de documentos está sujeita a falhas humanas;
- Sobrecarga da recepção: Funcionários dividem atenção entre check-in, atendimento telefônico e

outras demandas;

- Experiência do paciente: O processo burocrático impacta negativamente a percepção de qualidade

do atendimento.

## 1.1.3. Objetivos

Objetivo Geral

Desenvolver um sistema embarcado de autoatendimento para check-in de pacientes em clínicas

médicas, utilizando microcontrolador Raspberry Pi Pico W, capaz de validar agendamentos através da

leitura de QR Code, autenticar pacientes por biometria digital e exibir informações da consulta em

interface gráfica touchscreen.

Objetivos Específicos

- Projetar e implementar arquitetura de software em camadas que promova modularidade e

manutenibilidade

- Desenvolver drivers de hardware para integração de display TFT, touchscreen capacitivo, leitor de

QR Code e sensor biométrico

- Implementar comunicação com API REST para download de agendamentos e sincronização de

dados

- Utilizar sistema operacional de tempo real (FreeRTOS) para gerenciamento de tarefas concorrentes
- Desenvolver interface gráfica intuitiva utilizando a biblioteca LVGL
- Implementar cadastro e verificação de biometria digital com sincronização ao servidor
- Implementar persistência local de dados em cartão SD para operação com conectividade reduzida
- Validar o sistema através de testes integrados com hardware real

## 1.1.4. Justificativa

A escolha do Raspberry Pi Pico W como plataforma de desenvolvimento justifica-se por seu baixo custo,

disponibilidade no mercado brasileiro, capacidade de processamento adequada (dual-core ARM

Cortex-M0+ a 133 MHz), conectividade WiFi integrada e amplo suporte da comunidade. A utilização de

FreeRTOS permite o desenvolvimento de uma aplicação multitarefa responsiva, essencial para um

sistema que deve reagir em tempo real às interações do usuário.

Do ponto de vista acadêmico, o projeto integra conhecimentos de diversas áreas da engenharia de

sistemas embarcados: programação de baixo nível, protocolos de comunicação (SPI, I2C, UART),

sistemas operacionais de tempo real, arquitetura de software, interfaces homem-máquina e integração

de sistemas. Esta abordagem multidisciplinar proporciona uma experiência de aprendizado abrangente

e alinhada com as demandas do mercado de trabalho.

Do ponto de vista prático, o sistema proposto pode ser replicado a baixo custo por clínicas de pequeno e

médio porte, contribuindo para a modernização do atendimento em saúde e democratização do acesso

a tecnologias de autoatendimento.

# 1.2. Fundamentação Teórica

Esta seção apresenta os conceitos teóricos fundamentais que embasam o desenvolvimento do sistema de

check-in, abrangendo sistemas embarcados, sistemas operacionais de tempo real, arquitetura de software e

padrões de projeto.

## 1.2.1. Sistemas Embarcados

Um sistema embarcado é um sistema computacional dedicado a executar funções específicas,

geralmente integrado a um dispositivo maior. Diferentemente de computadores de propósito geral,

sistemas embarcados são projetados para realizar tarefas bem definidas, com restrições de recursos

como memória, processamento e consumo de energia.

O Raspberry Pi Pico W utilizado neste projeto é baseado no microcontrolador RP2040, que possui

processador dual-core ARM Cortex-M0+ operando a 133 MHz, 264 KB de memória SRAM e 2 MB de

memória Flash externa. O dispositivo conta ainda com conectividade Wi-Fi 802.11n integrada por meio

do chip CYW43439, além de diversas interfaces de comunicação, incluindo duas UART, duas SPI e duas

I2C, totalizando 26 pinos GPIO multifuncionais. Também oferece suporte a DMA, permitindo

transferências de dados mais eficientes.

## 1.2.2. Sistemas Operacionais de Tempo Real (RTOS)

Um Sistema Operacional de Tempo Real (RTOS) é projetado para processar eventos dentro de prazos

determinísticos, permitindo o gerenciamento eficiente de múltiplas tarefas concorrentes em sistemas

embarcados. O FreeRTOS, adotado neste projeto, oferece recursos como gerenciamento de tarefas com

prioridades, comunicação por filas, sincronização por semáforos e mutexes, grupos de eventos e timers

por software. Sua escolha se deve à ampla adoção na indústria, suporte ao RP2040 pela Raspberry Pi

Foundation, baixo consumo de memória e extensa documentação disponível.

## 1.2.3. Arquitetura de Software em Camadas

A arquitetura em camadas (Layered Architecture) é um padrão de projeto que organiza o software em

níveis hierárquicos, onde cada camada possui responsabilidades bem definidas e comunica-se apenas

com as camadas adjacentes. Este padrão promove:

- Separação de responsabilidades: Cada camada encapsula uma funcionalidade específica;
- Baixo acoplamento: Alterações em uma camada têm impacto mínimo nas demais;
- Testabilidade: Camadas podem ser testadas isoladamente através de mocks;
- Portabilidade: A troca de hardware requer alterações apenas nas camadas inferiores;
- Manutenibilidade: O código torna-se mais organizado e fácil de compreender.

No contexto de sistemas embarcados, uma arquitetura típica em camadas inclui:

- Camada de Hardware (HAL): Abstrai o acesso direto aos periféricos do microcontrolador;
- Camada de Drivers: Implementa a lógica de comunicação com dispositivos externos;

- Camada de Serviços: Contém a lógica de negócio da aplicação;
- Camada de Aplicação: Gerencia o fluxo da aplicação, interface com usuário e orquestração.

## 1.2.4. Padrões de Projeto Utilizados

O desenvolvimento do sistema emprega diversos padrões de projeto consagrados na engenharia de

software:

Singleton: Garante que uma classe possua apenas uma instância em toda a aplicação, fornecendo um

ponto de acesso global a ela. Este padrão é utilizado nos serviços do sistema (AppointmentService,

DataStorageService, TimeService, NetworkSyncService, FingerprintService) e na máquina de estados,

garantindo consistência de estado e evitando conflitos de acesso.

State Machine (Máquina de Estados): Modela o comportamento do sistema como um conjunto finito

de estados e transições. A máquina de estados gerencia 11 estados distintos (INITIALIZING,

DOWNLOADING_APPOINTMENTS, | IDLE, | VALIDATING, | FINGERPRINT_VERIFYING,

FINGERPRINT_ENROLLING, FINGERPRINT_UPLOADING, APPOINTMENT, ERROR, ERROR_CRITICAL,

RESTARTING). Este padrão é fundamental para sistemas embarcados reativos, pois facilita a visualização

do comportamento, torna explícitas todas as condições possíveis, simplifica a adição de novos estados e

previne estados inválidos.

Adapter: Permite que interfaces incompatíveis trabalhem juntas, convertendo a interface de uma classe

para outra esperada pelo cliente. No projeto, este padrão é utilizado para integrar a biblioteca LVGL com

os drivers de display e touch através das classes LVGLDisplayAdapter e LVGLTouchAdapter, desacoplando

a biblioteca gráfica dos drivers específicos de hardware.

Dependency Injection: Implementado de forma simplificada através de injeção por construtor, os

drivers recebem suas dependências de HAL através do construtor, permitindo a substituição de

implementações concretas para testes ou portabilidade para outras plataformas.

## 1.2.5. Interface Gráfica Embarcada

A LVGL (Light and Versatile Graphics Library) é uma biblioteca gráfica open-source voltada a sistemas

embarcados com recursos limitados, oferecendo renderização eficiente com anti-aliasing, diversos

widgets, sistema de estilos e animações, baixo consumo configurável de memória e independência de

hardware por meio de drivers abstratos.

# 1.3. Metodologia

## 1.3.1. Abordagem de Desenvolvimento

O desenvolvimento seguiu uma abordagem incremental e iterativa, com ciclos de implementação, testes

em hardware e refinamento. Cada módulo foi testado individualmente antes da integração ao sistema

principal. A metodologia adotada consistiu nas seguintes etapas:

1. Prototipação de hardware: Montagem e teste individual de cada periférico em protoboard;
2. Desenvolvimento de drivers: Implementação bottom-up (HAL → Driver → Adapter);
3. Montagem do protótipo físico: Construção da versão soldada do sistema com conectores para

facilitar manutenção;
4. Implementação de serviços: Lógica de negócio independente de hardware;
5. Integração progressiva: Adição gradual de funcionalidades ao sistema principal via tasks FreeRTOS;
6. Testes integrados: Validação do fluxo completo em hardware real.

Padrões de linguagem adotados: C11 para código de baixo nível (HAL, drivers) e C++17 para camadas

superiores (serviços, aplicação).

## 1.3.2. Ferramentas Utilizadas

VS Code: IDE com extensões para Raspberry Pi Pico, C/C++ e CMake Tools.

Pico SDK 2.1.1: SDK oficial da Raspberry Pi Foundation com APIs de hardware e suporte a FreeRTOS.

CMake ≥ 3.13: Sistema de build multiplataforma para gerenciamento de dependências e compilação.

Ninja 1.12.1: Build system focado em velocidade, backend do CMake.

GCC ARM 14.2: Compilador C/C++ para arquitetura ARM Cortex-M0+.

picotool 2.1.1: Utilitário oficial para upload de firmware e interação com o Pico.

Git: Sistema de controle de versão distribuído.

Minicom: Terminal serial para debug e visualização de logs.

## 1.3.3. Bibliotecas Externas

FreeRTOS Kernel: Sistema operacional de tempo real open-source, amplamente utilizado em sistemas

embarcados. Versão: Compatível com Pico SDK 2.1.1 (FreeRTOS Kernel 10.4.3+)

LVGL 8.3.11: Light and Versatile Graphics Library - biblioteca gráfica para interfaces embarcadas.

Repositório: https://github.com/lvgl/lvgl

Mongoose: Biblioteca de rede embarcada para servidores web e clientes HTTP/HTTPS.

Repositório: https://github.com/cesanta/mongoose

cJSON: Parser JSON leve escrito em C puro, ideal para sistemas embarcados.

Repositório: https://github.com/DaveGamble/cJSON

FatFS (no-OS-FatFS-SD-SPI-RPi-Pico): Sistema de arquivos FAT32 para cartões SD via SPI, portado para

Raspberry Pi Pico.

Repositório: https://github.com/carlk3/no-OS-FatFS-SD-SPI-RPi-Pico

# 1.4. Especificação de Requisitos

## 1.4.1. Requisitos Funcionais

Os requisitos funcionais descrevem as funcionalidades que o sistema deve oferecer, ou seja, o que o

sistema deve ser capaz de fazer para atender às necessidades dos usuários e da clínica.

ID | Requisito
RF01 | Conectar à rede WiFi e sincronizar horário via NTP
RF02 | Baixar agendamentos do dia via API REST
RF03 | Armazenar dados localmente em cartão SD
RF04 | Ler QR Code apresentado pelo paciente
RF05 | Validar agendamento (ID, CPF, horário)
RF06 | Cadastrar e verificar digital do paciente
RF07 | Enviar dados biométricos para o servidor
RF08 | Exibir informações da consulta na tela
RF09 | Mostrar mensagens de erro quando necessário
RF10 | Sincronizar dados de check-in com o servidor
RF11 | Operar com dados locais minimizando necessidade de conexão

## 1.4.2. Requisitos Não-Funcionais

Os requisitos não-funcionais especificam critérios de qualidade, desempenho e restrições técnicas que o

sistema deve atender, definindo como as funcionalidades devem ser entregues.

ID | Requisito
RNF01 | Tempo de resposta inferior a 3 segundos
RNF02 | Interface gráfica sem travamentos
RNF03 | Recuperação automática de erros
RNF04 | Reinício automático em caso de falha crítica
RNF05 | Armazenamento local para pelo menos 1 dia de operação
RNF06 | Interface simples e intuitiva
RNF07 | Operação contínua sem supervisão

# 1.5. Arquitetura do Sistema

## 1.5.1. Arquitetura de Hardware

O sistema é composto por um microcontrolador central (Raspberry Pi Pico W) conectado a diversos

periféricos através de interfaces de comunicação serial.

Componentes

Componente | Modelo | Interface | Função
Microcontrolador | RP2040W | — | Processamento central
Display TFT | 4.0" 480×320 ST7796 | SPI0 | Exibição da interface
Touch Capacitivo | FT6336U | I2C1 | Entrada do usuário
Leitor QR Code | GM67 | UART0 | Leitura de QR Codes
Leitor Biométrico | R307S | UART1 | Impressão digital (futuro)
Cartão SD | Módulo SPI | SPI1 | Armazenamento local

Pinagem Principal

Periférico | Pinos
Display (SPI0) | MOSI: GP19, SCK: GP18, CS: GP17, DC: GP20, RST: GP21

Touch (I2C1) | SDA: GP6, SCL: GP7, RST: GP8, INT: GP9
QR Reader (UART0) | TX: GP0, RX: GP1
Fingerprint (UART1) | TX: GP4, RX: GP5
SD Card (SPI1) | MOSI: GP15, MISO: GP12, SCK: GP14, CS: GP13

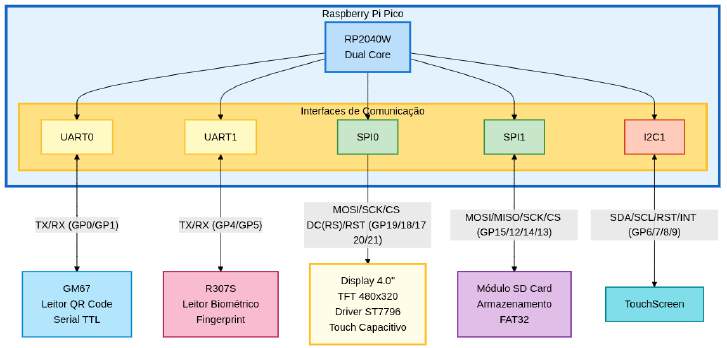
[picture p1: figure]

Figura 1: Diagrama de Hardware — ver diagrama hardware_diagram.md

## 1.5.2. Arquitetura de Software

O software foi projetado em uma arquitetura de 5 camadas, promovendo separação de

responsabilidades e baixo acoplamento:

Camada | Responsabilidade | Exemplos
Application | Fluxo da aplicação, UI, orquestração | Tasks FreeRTOS, StateMachine, Screens
Service | Lógica de negócio | AppointmentService, DataStorageService, TimeService, NetworkSyncService, FingerprintService
Adapter | Integração com bibliotecas externas | LVGLDisplayAdapter, LVGLTouchAdapter
Driver | Comunicação com periféricos | ST7796Driver, FT6336U_Driver, GM67_Driver, R307S_Driver
HAL | Abstração de hardware | HAL_SPI_RP2040, HAL_I2C_RP2040, HAL_UART_RP2040

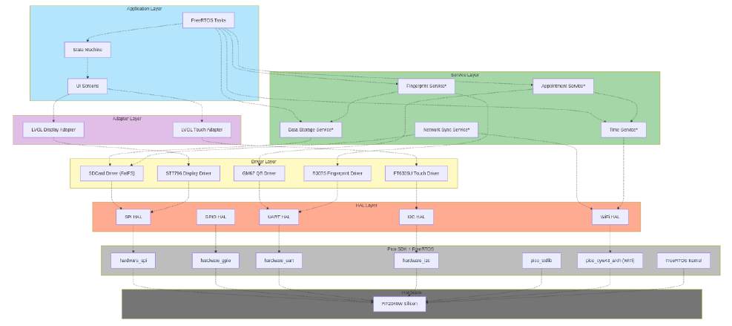
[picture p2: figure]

Figura 2: Diagrama de Arquitetura de Software em Camadas — ver diagrama

software_architecture_layers_diagram.md

# 1.6. Implementação

## 1.6.1. Estrutura do Projeto

O projeto segue uma organização modular que separa código-fonte, configurações, bibliotecas externas

e documentação:

├── CMakeLists.txt
├── pico_sdk_import.cmake
│
├── config/
│ | ├── api_config.hpp | # URL da API, endpoints, credenciais, timeouts
│ | ├── display_config.hpp | # Resolução, rotação, SPI speed, buffer LVGL
│ | ├── fingerprint_config.hpp | # UART e baudrate do sensor biométrico
│ | ├── FreeRTOSConfig.h | # Configuração do kernel FreeRTOS
│ | ├── hw_config.c | # Configuração do SD Card (FatFS)
│ | ├── lv_conf.h | # Configuração do LVGL
│ | ├── lvgl_tick_custom.h | # Tick customizado do LVGL para FreeRTOS
│ | ├── lwipopts.h | # Configuração do lwIP (TCP/IP stack)
│ | ├── mongoose_config.h | # Configuração do Mongoose HTTP
│ | ├── pin_config.hpp | # Mapeamento de todos os GPIOs
│ | ├── qr_code_reader_config.hpp | # UART e baudrate do scanner QR
│ | ├── sntp_callbacks.h | # Callbacks de sincronização NTP
│ | └── wifi_config.hpp | # SSID, senha e país do WiFi
│
├── src/
│ ├── main.cpp | # Entry point: init drivers → create tasks →
scheduler
│ | │
│ | ├── core/
│ | │ | ├── state_machine.hpp | # Máquina de estados (singleton, 11 estados)
│ | │ | └── state_machine.cpp

│ | │
│ | ├── hal/
│ | │ | ├── interfaces/
│ | │ | │ | ├── hal_spi_interface.hpp | # Interface abstrata SPI
│ | │ | │ | ├── hal_i2c_interface.hpp | # Interface abstrata I2C
│ | │ | │ | ├── hal_uart_interface.hpp # Interface abstrata UART
│ | │ | │ | └── hal_wifi_interface.hpp # Interface abstrata WiFi
│ | │ | └── rp2040/
│ | │ | | ├── hal_spi_rp2040.hpp/.cpp
│ | │ | | ├── hal_i2c_rp2040.hpp/.cpp
│ | │ | | ├── hal_uart_rp2040.hpp/.cpp
│ | │ | | └── hal_wifi_rp2040.hpp/.cpp
│ | │
│ | ├── drivers/
│ | │ | ├── display/
│ | │ | │ | ├── interface/display_interface.hpp
│ | │ | │ | └── st7796/st7796_driver.hpp/.cpp
│ | │ | ├── touch/
│ | │ | │ | ├── interface/touch_interface.hpp
│ | │ | │ | └── ft6336u/ft6336u_driver.hpp/.cpp
│ | │ | ├── qr_code_reader/
│ | │ | │ | ├── interface/qr_interface.hpp
│ | │ | │ | └── gm67/gm67_driver.hpp/.cpp
│ | │ | └── fingerprint/
│ | │ | ├── interface/fingerprint_interface.hpp
│ | │ | └── r307s/r307s_driver.hpp/.cpp
│ | │
│ | ├── adapters/lvgl/
│ | │ | ├── lvgl_display_adapter.hpp/.cpp
│ | │ | └── lvgl_touch_adapter.hpp/.cpp
│ | │
│ | ├── services/
│ | │ | ├── appointment_service.hpp/.cpp | # Validação de QR e agendamentos
│ | │ | ├── data_storage_service.hpp/.cpp | # Leitura/escrita no SD Card
│ | │ | ├── fingerprint_service.hpp/.cpp | # Cadastro e verificação biométrica
│ | │ | ├── network_sync_service.hpp/.cpp | # Cliente HTTP (Mongoose)
│ │ └── time_service.hpp/.cpp | # NTP → RTC, data/hora
│ | │
│ | ├── tasks/
│ | │ | ├── task_wifi_time_init.hpp/.cpp | # Conexão WiFi + sincronização NTP
│ | │ | ├── task_lvgl.hpp/.cpp | # Loop LVGL + gerência de telas
│ | │ | ├── task_qr_reader.hpp/.cpp | # Leitura contínua do scanner QR
│ | │ | ├── task_qr_validator.hpp/.cpp | # Validação e orquestração do check-in
│ | │ | └── task_network.hpp/.cpp | # Download de agendamentos e templates
│ | │
│ | ├── ui/screens/
│ | │ | ├── welcome_screen.hpp/.cpp | # Tela principal (idle)
│ | │ | ├── init_status_screen.hpp/.cpp | # Tela de boot (WiFi, NTP, SD)
│ | │ | ├── appointment_screen.hpp/.cpp | # Check-in confirmado
│ | │ | ├── error_screen.hpp/.cpp | # Erro recuperável
│ | │ | ├── error_critical_screen.hpp/.cpp | # Erro crítico + countdown reboot
│ | │ | ├── fingerprint_operation_screen.hpp/.cpp # Verificação/cadastro digital
│ | │ | └── fingerprint_upload_screen.hpp/.cpp | # Upload de template
│ | │
│ | └── tests/code_examples/
│ | ├── README.md | # Instruções dos demos
│ | ├── lvgl_rtos_demo.cpp | # Demo display + touch
│ | ├── qr_code_reader_demo.cpp | # Demo scanner QR
│ | ├── fingerprint_demo.cpp | # Demo sensor biométrico
│ | ├── sdcard_fatfs_demo.cpp | # Demo SD Card
│ | └── wifi_demo.cpp | # Demo WiFi
│
├── lib/
│ | ├── FreeRTOS-Kernel/ | # Submodule
│ | └── no-OS-FatFS/ | # Submodule
│

└── docs/
├── dev/ | # Notas de desenvolvimento por periférico
└── diagrams/
├── hardware_diagram.md
├── software_architecture_layers_diagram.md
├── class_diagrams.md
├── sequence_diagrams.md
└── state_machine_diagram.md

Observações importantes:

- Bibliotecas externas: LVGL, Mongoose e cJSON são baixadas automaticamente pelo CMake via

FetchContent. FreeRTOS e FatFS são submodules Git em lib/.
- Build: A pasta build/ é gerada automaticamente e não é versionada (incluída no .gitignore).
- Configurações: Todas as configurações de hardware e rede estão centralizadas em config/ para

facilitar adaptação a diferentes ambientes.

Repositório do projeto desenvolvido:

AdryRocha/medical-clinic-checkin: Repositório com o desenvolvimento de código embarcado para

funcionalidades de check-in em clínicas médicas. (https://github.com/AdryRocha/medical-clinic-checkin)

## 1.6.2. Controle de Versão

O projeto utiliza Git com estratégia de branching baseada em GitFlow simplificado para garantir código

estável e facilitar colaboração.

Estrutura de Branches

main: Branch principal de produção contendo apenas código estável e testado. Recebe commits

exclusivamente da branch dev via merge, e cada merge recebe uma tag de versão semântica (ex: v1.0.0,

v1.1.0). Mantém histórico linear e limpo para rastreamento de releases.

dev: Branch de integração e desenvolvimento contínuo onde todas as features são integradas e

testadas. Testes manuais em hardware são realizados aqui antes de mesclar na main. Serve como ponto

de partida para criar novas branches feature/* e deve estar sempre sincronizada e em estado funcional.

feature/*: Branches de desenvolvimento isolado de funcionalidades específicas com nomenclatura

descritiva (ex: feature/hal-drivers, feature/qr-validation, feature/biometric-auth). Código novo é escrito

nestas branches sem afetar dev e são mescladas na dev via Pull Request após revisão de código.

# 1.7. Testes e Validação

## 1.7.1. Estratégia de Testes

O projeto adotou uma estratégia de testes bottom-up, validando cada componente isoladamente antes

da integração.

## 1.7.2. Demos Standalone

Foram desenvolvidos demos standalone para validação individual de cada componente de hardware:

Demo | Arquivo | Componente Testado
LVGL RTOS Demo | lvgl_rtos_demo.cpp | Display TFT + Touch + FreeRTOS + Interface gráfica
QR Code Reader Demo | qr_code_reader_demo.cpp | Scanner GM67 via UART, decodificação de dados
SD Card FatFS Demo | sdcard_fatfs_demo.cpp | Leitura/escrita de arquivos, sistema FAT32
WiFi Demo | wifi_demo.cpp | Conexão WiFi, requisições HTTP, NTP
Fingerprint Demo | fingerprint_demo.cpp | Sensor R307S (em desenvolvimento)

Localização: src/tests/code_examples/

Instruções de execução: Ver src/tests/code_examples/README.md

## 1.7.3. Testes Integrados

Após validação individual, foram realizados testes integrados do fluxo completo:

1. Teste de inicialização: Verificação de conexão WiFi, sincronização NTP e montagem do SD Card
2. Teste de download: Download de agendamentos da API de persistência local
3. Teste de validação: Leitura de QR Codes válidos e inválidos
4. Teste de atualização: Marcação de check-in e sincronização com API
5. Teste de recuperação: Simulação de erros e verificação de transições de estado

# 1.8. Resultados

## 1.8.1. Funcionalidades Implementadas

O sistema implementa com sucesso um fluxo de check-in automatizado, integrando hardware (display

touchscreen ST7796, scanner QR GM67, leitor biométrico R503 e cartão SD) e software (FreeRTOS,

LVGL, drivers customizados HAL) de forma estável.

Conectividade e Sincronização: O sistema conecta-se automaticamente à rede WiFi na inicialização,

sincroniza horário via NTP para validação temporal precisa, autentica na API REST e baixa agendamentos

com persistência local em cartão SD (formato JSON).

Validação de Check-in: A leitura e validação de QR Code ocorre de forma fluida, verificando ID, CPF,

hash, horário (janela de ±30 minutos) e status do agendamento. O sistema impede check-ins duplicados

e fornece feedback claro para todas as situações.

Autenticação Biométrica: Implementa cadastro e verificação de digitais através do sensor R503, com

armazenamento local e sincronização com o servidor. O sistema identifica automaticamente se o

paciente precisa cadastrar digital ou apenas verificá-la, enviando os templates biométricos para a API

após captura.

Operação Resiliente: Recupera-se automaticamente de erros não-críticos, retorna à tela inicial após

timeouts configurados e mantém operação estável mesmo com falhas temporárias de conectividade ou

hardware.

## 1.8.2. Nível de Maturidade Tecnológica (TRL)

A escala TRL (Technology Readiness Level) é uma metodologia desenvolvida pela NASA e amplamente

adotada para avaliar o grau de maturidade de uma tecnologia. A escala possui 9 níveis:

- TRL 1-3: Pesquisa básica (princípios observados, conceito formulado, prova de conceito

experimental)

- TRL 4-6: Desenvolvimento tecnológico (validação em laboratório, validação em ambiente

relevante, demonstração em ambiente relevante)

- TRL 7-9: Demonstração e implementação (protótipo em ambiente operacional, sistema

qualificado, sistema comprovado em operação)

TRL Atual: Nível 4 - Validação de componentes e sistema integrado em ambiente de laboratório.

O projeto encontra-se no TRL 4 com base nas seguintes evidências.

Características que comprovam TRL 4:

- ✅ Sistema integrado completo testado em bancada de laboratório
- ✅ Hardware montado em placa de prototipagem soldada com conectores crimpados
- ✅ Todos os componentes validados individualmente e em conjunto
- ✅ Comunicação WiFi e sincronização via API REST funcionais
- ✅ Autenticação biométrica implementada e operacional
- ✅ Fluxo completo de check-in (QR Code → Validação → Biometria → Confirmação) funcional
- ✅ Sincronização de dados em tempo real com servidor
- ✅ Armazenamento local em SD Card com formato JSON
- ✅ Arquitetura de software modular e documentada
- ✅ Todos os requisitos funcionais e não-funcionais atendidos

O que falta para TRL 5 (Validação em ambiente relevante):

- ❌ Ausência de PCB customizado (placa atual é de prototipagem soldada)
- ❌ Ausência de case profissional para instalação em recepção
- ❌ Hardware não preparado para ambiente clínico real
- ❌ Comunicação HTTP sem criptografia (impede uso com dados reais)
- ❌ Ausência de validação completa de hash do QR Code
- ❌ Dados no SD Card sem criptografia
- ❌ Sistema de autenticação básico (impossibilita testes com usuários reais)
- ❌ Backend não está em ambiente de produção
- ❌ Sem monitoramento e telemetria de operação
- ❌ Sem sistema de atualização remota (OTA)
- ❌ Certificações regulatórias (ANATEL, INMETRO) não obtidas

O que é necessário para TRL 5:

Para atingir TRL 5, o sistema precisa ser validado em ambiente que simule operação real de clínica, o

que exige: PCB dedicado, case profissional, implementação completa de segurança (HTTPS, criptografia),

sistema robusto de autenticação e infraestrutura de backend em produção.

# 2. AGENDAMENTOS DE CONSULTAS POR WEB API E BOT DO TELEGRAM

# 2.1. INTRODUÇÃO

O presente documento descreve a arquitetura e funcionalidades do Sistema de Gerenciamento de Clínicas Médicas, composto por uma API REST e um Bot Telegram para agendamento de consultas. Este sistema foi desenvolvido para integração com dispositivo embarcado responsável pela autenticação biométrica e check-in de pacientes.

O sistema oferece uma solução completa para gestão de clínicas médicas, abrangendo desde o cadastro de pacientes e profissionais até o agendamento de consultas e validação de presença através de QR Code. A integração com sistema embarcado permitirá a autenticação por biometria digital, proporcionando maior segurança e agilidade no processo de check-in.

Repositório do grupo em github privado com o desenvolvimento da API: https://github.com/Luana-Menezes/Clinicas_Medicas_WebAPI

# 2.2. ARQUITETURA DO SISTEMA

## 2.2.1. Componentes Principais

O sistema é dividido em dois componentes principais que trabalham de forma integrada:

a) API REST (FastAPI): Backend completo desenvolvido em Python utilizando o framework FastAPI, responsável por toda a lógica de negócio e persistência de dados.
b) Bot Telegram: Interface conversacional que permite aos pacientes agendar consultas e gerenciar suas informações através do aplicativo Telegram.

## 2.2.2. Stack Tecnológico

API REST: Desenvolvida em Python 3.12+ com FastAPI 0.104.1, utiliza SQLAlchemy 2.0.23 como ORM para PostgreSQL, Pydantic 2.5.0 para validação de dados, JWT para autenticação e Segno 1.6.1 para geração de QR Codes.

Bot Telegram: Implementado em Python 3.12+ com a biblioteca python-telegram-bot, realizando integração via HTTP com a API REST para envio de QR Codes e notificações aos pacientes.

# 2.3. API REST
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

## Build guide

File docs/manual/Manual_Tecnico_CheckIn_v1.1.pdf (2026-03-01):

MANUAL TÉCNICO | Sistema de Check-In Inteligente | v1.1

# INSTITUTO HARDWARE BR

EMBARCATEH – Campinas, SP

# MANUAL TÉCNICO

## Sistema de Check-In Inteligente

## para Clínicas Médicas

Plataforma: Raspberry Pi Pico 2W (Microcontrolador RP2350/RP2040) Metodologia: Método Cugnasca de Engenharia de Sistemas Críticos Versão: 1.1
Responsável Técnico: Adriana Rocha Castro de Paula e Luana Menezes Data: Fevereiro de 2026
Contato: suporte@hardwarebr.edu.br
Instituto Hardware BR | suporte@hardwarebr.edu.br | Página 1

## 0. Controle de Versões e Identidade Técnica

Este documento é a única fonte de verdade para operação, manutenção e desenvolvimento do Sistema de Check-In Inteligente. Toda atualização deve ser registrada na tabela abaixo antes de ser distribuída.

Versão | Data | Autor | Descrição das Alterações
1.0 | 01/02/2026 | Adriana / Luana | Lançamento inicial do protótipo funcional.
1.1 | 18/02/2026 | Adriana / Luana | Padronização visual, guia de instalação completo, HAL, seções de ambiente de desenvolvimento, cadastro biométrico, configuração GM67, protocolo R307S e parâmetros FreeRTOS.

## PARTE I — VISÃO GERAL DO SISTEMA

### 1.1 Introdução e Finalidade

O Sistema de Check-In Inteligente é um totem de atendimento autônomo que automatiza a identificação de pacientes em clínicas médicas, combinando hardware embarcado de alto desempenho com arquitetura de software robusta. O resultado é uma solução de baixo custo, alta disponibilidade e conformidade nativa com a LGPD (Lei 13.709/2018), desenvolvida e validada sob o Método Cugnasca de Engenharia de Sistemas Críticos.

### 1.2 Diagrama de Blocos do Sistema

A arquitetura opera em topologia estrela, com o RP2350 como núcleo central:

┌────────────────────────────────────┐
│ | RASPBERRY Pi PICO 2W (RP2350) │
│ | Dual-Core Cortex-M33 | │
│ | @ 150 MHz | │
┌──────────────┐ | │ ┌──────────┐ ┌─────────────────┐ │
│ Scanner QR | │ | │ │ FreeRTOS │ │ ARM TrustZone │ │
│ GM67 (UART0) │◄────►│ │ Kernel | │ │ SHA-256 accel │ │
└──────────────┘ | │ └──────────┘ └─────────────────┘ │
┌──────────────┐ | │ ┌──────────┐ ┌─────────────────┐ │
│ Biometria | │ | │ │ 520KB | │ │ MPU / WDT HW | │ │
│ R307S (UART1)│◄────►│ │ SRAM | │ │ | │ │
└──────────────┘ | │ └──────────┘ └─────────────────┘ │
┌──────────────┐ | └──────┬────────────────┬────────────┘
│ Display TFT │ | │ SPI0 | │ SPI1
│ ST7796 + | │◄────────────┘ | │
│ Touch FT6336U│ (+ I2C1) | ┌──────────▼─────────┐
└──────────────┘ | │ | Módulo SD Card | │
┌──────────────┐ | │ (FatFs / Logs) | │
│ Wi-Fi CYW43 │◄──── integrado | └────────────────────┘
│ (MQTT/HTTPS) │
└──────────────┘

ℹ

O isolamento lógico entre periféricos de entrada (sensores) e saída (display) é garantido pelo software. Uma falha em um módulo (ex: biometria danificada) não paralisa o restante do sistema — o check-in por QR Code continua operando.

### 1.3 Objetivos de Desempenho e Disponibilidade

- Tempo total de check-in: inferior a 5 segundos após identificação
- Taxa de atualização do display: superior a 30 FPS
- Watchdog Timer: reinicialização automática em até 500 ms
- Heap livre mínimo: 20% do pool de 192 KB em operação contínua
- FAR biométrica (R307S): inferior a 0,001%
- Disponibilidade offline: operação completa com sincronização posterior via SD Card

## PARTE II — AMBIENTE DE DESENVOLVIMENTO

Esta parte descreve todo o ambiente necessário para compilar, gravar e depurar o firmware do zero. Um técnico sem experiência prévia com RP2350 deve seguir esta sequência antes de qualquer outra etapa.

### 2.1 Requisitos de Sistema

- Sistema Operacional: Windows 10/11 (64-bit), Ubuntu 22.04 LTS ou macOS 13+
- Git: versão 2.30 ou superior
- CMake: versão 3.17 ou superior
- GNU Arm Toolchain: arm-none-eabi-gcc 12.2 ou superior
- Python: versão 3.9 ou superior (usado pelo Pico SDK)
- VS Code: recomendado, com extensão CMake Tools e Cortex-Debug
- Driver USB: Zadig (Windows) para reconhecer o Pico 2W em modo BOOTSEL

### 2.2 Instalação do Pico SDK (Windows)

Execute os passos abaixo em um terminal PowerShell com privilégios de administrador:

1. Instalar o pacote oficial do Pico SDK para Windows: baixe o instalador em https://github.com/raspberrypi/pico-setup-windows/releases e execute. Ele instala automaticamente o toolchain ARM, CMake, Git e o SDK v2.0+.
2. Após a instalação, abrir o atalho 'Pico - Visual Studio Code' criado na área de trabalho — ele configura as variáveis de ambiente automaticamente.
3. Verificar a instalação: abrir o terminal integrado do VS Code e executar: arm-none-eabi-gcc --version

# Saída esperada:

arm-none-eabi-gcc (Arm GNU Toolchain 12.2) 12.2.1 20221205

### 2.3 Instalação do Pico SDK (Linux/Ubuntu)

# 1. Instalar dependências do sistema

sudo apt update && sudo apt install -y git cmake gcc-arm-none-eabi \ libnewlib-arm-none-eabi libstdc++-arm-none-eabi-newlib \
python3 python3-pip build-essential

# 2. Clonar o Pico SDK (versão compatível com RP2350)

cd ~ && git clone https://github.com/raspberrypi/pico-sdk.git --branch 2.0.0 cd pico-sdk && git submodule update --init

# 3. Configurar variável de ambiente (adicionar ao ~/.bashrc)

echo 'export PICO_SDK_PATH=$HOME/pico-sdk' >> ~/.bashrc source ~/.bashrc

# 4. Verificar

echo $PICO_SDK_PATH # deve exibir: /home/usuario/pico-sdk

### 2.4 Clonando o Repositório do Projeto

git clone https://github.com/AdryRocha/checkin-inteligente.git
cd checkin-inteligente
git submodule update --init --recursive | # baixa FreeRTOS e LVGL como submodules
📌 | O projeto usa submódulos Git para FreeRTOS-Kernel e LVGL v9. Sempre execute 'git submodule update --init --recursive' após clonar ou ao fazer pull de atualizações.

### 2.5 Estrutura de Pastas do Projeto

├── CMakeLists.txt
├── pico_sdk_import.cmake
│
├── config/
│ | ├── api_config.hpp | # URL da API, endpoints, credenciais, timeouts
│ | ├── display_config.hpp | # Resolução, rotação, SPI speed, buffer LVGL
│ | ├── fingerprint_config.hpp | # UART e baudrate do sensor biométrico
│ | ├── FreeRTOSConfig.h | # Configuração do kernel FreeRTOS
│ | ├── hw_config.c | # Configuração do SD Card (FatFS)
│ | ├── lv_conf.h | # Configuração do LVGL
│ | ├── lvgl_tick_custom.h | # Tick customizado do LVGL para FreeRTOS
│ | ├── lwipopts.h | # Configuração do lwIP (TCP/IP stack)
│ | ├── mongoose_config.h | # Configuração do Mongoose HTTP
│ | ├── pin_config.hpp | # Mapeamento de todos os GPIOs
│ | ├── qr_code_reader_config.hpp | # UART e baudrate do scanner QR
│ | ├── sntp_callbacks.h | # Callbacks de sincronização NTP
│ | └── wifi_config.hpp | # SSID, senha e país do WiFi
│
├── src/
│ | ├── main.cpp | # Entry point: init drivers → create tasks →
scheduler
│ | │
│ | ├── core/
│ | │ | ├── state_machine.hpp | # Máquina de estados (singleton, 11 estados)
│ | │ | └── state_machine.cpp
│ | │
│ | ├── hal/
│ | │ | ├── interfaces/
│ | │ | │ | ├── hal_spi_interface.hpp | # Interface abstrata SPI
│ | │ | │ | ├── hal_i2c_interface.hpp | # Interface abstrata I2C
│ | │ | │ | ├── hal_uart_interface.hpp # Interface abstrata UART
│ | │ | │ | └── hal_wifi_interface.hpp # Interface abstrata WiFi
│ | │ | └── rp2040/
│ | │ | | ├── hal_spi_rp2040.hpp/.cpp
│ | │ | | ├── hal_i2c_rp2040.hpp/.cpp
│ | │ | | ├── hal_uart_rp2040.hpp/.cpp
│ | │ | | └── hal_wifi_rp2040.hpp/.cpp
│ | │
│ | ├── drivers/
│ | │ | ├── display/
│ | │ | │ | ├── interface/display_interface.hpp
│ | │ | │ | └── st7796/st7796_driver.hpp/.cpp
│ | │ | ├── touch/
│ | │ | │ | ├── interface/touch_interface.hpp

│ | │ | │ | └── ft6336u/ft6336u_driver.hpp/.cpp
│ | │ | ├── qr_code_reader/
│ | │ | │ | ├── interface/qr_interface.hpp
│ | │ | │ | └── gm67/gm67_driver.hpp/.cpp
│ | │ | └── fingerprint/
│ | │ | ├── interface/fingerprint_interface.hpp
│ | │ | └── r307s/r307s_driver.hpp/.cpp
│ | │
│ | ├── adapters/lvgl/
│ | │ | ├── lvgl_display_adapter.hpp/.cpp
│ | │ | └── lvgl_touch_adapter.hpp/.cpp
│ | │
│ | ├── services/
│ | │ | ├── appointment_service.hpp/.cpp | # Validação de QR e agendamentos
│ | │ | ├── data_storage_service.hpp/.cpp | # Leitura/escrita no SD Card
│ | │ | ├── fingerprint_service.hpp/.cpp | # Cadastro e verificação biométrica
│ | │ | ├── network_sync_service.hpp/.cpp | # Cliente HTTP (Mongoose)
│ | │ | └── time_service.hpp/.cpp | # NTP → RTC, data/hora
│ | │
│ | ├── tasks/
│ | │ | ├── task_wifi_time_init.hpp/.cpp | # Conexão WiFi + sincronização NTP
│ | │ | ├── task_lvgl.hpp/.cpp | # Loop LVGL + gerência de telas
│ | │ | ├── task_qr_reader.hpp/.cpp | # Leitura contínua do scanner QR
│ | │ | ├── task_qr_validator.hpp/.cpp | # Validação e orquestração do check-in
│ | │ | └── task_network.hpp/.cpp | # Download de agendamentos e templates
│ | │
│ | ├── ui/screens/
│ | │ | ├── welcome_screen.hpp/.cpp | # Tela principal (idle)
│ | │ | ├── init_status_screen.hpp/.cpp | # Tela de boot (WiFi, NTP, SD)
│ | │ | ├── appointment_screen.hpp/.cpp | # Check-in confirmado
│ | │ | ├── error_screen.hpp/.cpp | # Erro recuperável
│ | │ | ├── error_critical_screen.hpp/.cpp | # Erro crítico + countdown reboot
│ | │ | ├── fingerprint_operation_screen.hpp/.cpp # Verificação/cadastro digital
│ | │ | └── fingerprint_upload_screen.hpp/.cpp | # Upload de template
│ | │
│ | └── tests/code_examples/
│ | ├── README.md | # Instruções dos demos
│ | ├── lvgl_rtos_demo.cpp | # Demo display + touch
│ | ├── qr_code_reader_demo.cpp | # Demo scanner QR
│ | ├── fingerprint_demo.cpp | # Demo sensor biométrico
│ | ├── sdcard_fatfs_demo.cpp | # Demo SD Card
│ | └── wifi_demo.cpp | # Demo WiFi
│
├── lib/
│ | ├── FreeRTOS-Kernel/ | # Submodule
│ | └── no-OS-FatFS/ | # Submodule
│
└── docs/
├── dev/ | # Notas de desenvolvimento por periférico
└── diagrams/
├── hardware_diagram.md
├── software_architecture_layers_diagram.md
├── class_diagrams.md
├── sequence_diagrams.md
└── state_machine_diagram.md

⚠

NUNCA defina números de GPIO diretamente nos arquivos de driver. Use exclusivamente as definições do arquivo src/config/board_config.h. Isso é um requisito da Metodologia Cugnasca para portabilidade e manutenibilidade.

### 2.6 Compilando o Firmware

# A partir da pasta raiz do projeto:

mkdir build && cd build

# Configurar o CMake — FLAG PICO_BOARD OBRIGATÓRIA

cmake .. -DPICO_BOARD=pico2_w -DPICO_SDK_PATH=$PICO_SDK_PATH

# Compilar (use -j$(nproc) para paralelizar)

make -j$(nproc)

# Arquivo gerado para gravação:

ls build/*.uf2 # ex: checkin_inteligente.uf2

⚠

A flag -DPICO_BOARD=pico2_w é OBRIGATÓRIA. Sem ela, o driver do chip wireless CYW43 não é vinculado e todas as funções de rede ficam inoperantes após o flash — o erro não aparece em tempo de compilação.

### 2.7 Gravando o Firmware (Flash)

4. Conectar o Pico 2W ao PC via cabo USB enquanto mantém pressionado o botão BOOTSEL na placa.
5. Soltar o botão BOOTSEL. O sistema operacional montará uma unidade de armazenamento virtual chamada 'RP2350'.
6. Copiar (arrastar) o arquivo .uf2 gerado para essa unidade.
7. A unidade será desmontada automaticamente e o Pico reiniciará com o novo firmware.
8. Verificar: o LED verde da placa piscará 3 vezes indicando boot bem-sucedido.

# Alternativa via linha de comando (Linux/macOS com picotool instalado): picotool load build/checkin_inteligente.uf2 --force

picotool reboot

### 2.8 Depuração em Tempo Real

Conectar via USB Serial (115200 baud) para visualizar logs das tarefas em tempo real:

# Linux/macOS:

screen /dev/ttyACM0 115200

# Windows (PowerShell):

# Usar PuTTY ou Tera Term → porta COM (verificar Gerenciador de Dispositivos)

# Baudrate: 115200 | Data bits: 8 | Stop: 1 | Paridade: nenhuma

# Exemplo de saída esperada no boot:

[BOOT] Sistema de Check-In Inteligente v1.1
[BOOT] SD Card OK — FatFs montado
[BOOT] WiFi: conectando a 'NomeDaRede'...

[BOOT] WiFi: IP 192.168.1.105 obtido [BOOT] Watchdog armado — timeout: 500ms [UI] Tela de boas-vindas exibida

## PARTE III — HARDWARE

### 3.1 Especificações do Microcontrolador RP2350

- CPU: Dual-Core ARM Cortex-M33 @ 150 MHz com FPU e DSP
- SRAM: 520 KB on-chip, dividida em bancos para acesso DMA paralelo
- Flash: 4 MB QSPI externa (código e dados estáticos)
- Segurança: ARM TrustZone, Secure Boot, OTP, acelerador SHA-256 por hardware
- Alimentação: 5V via USB-C | Consumo médio: 250 mA | Pico: 500 mA
- Custo: R$ 127,98 (Ref. NF 24/11/2025)

⚠

O Scanner GM67 e o backlight do display DEVEM ser alimentados pelo pino VBUS (5V) — nunca pelo regulador interno de 3,3V — para evitar brown-outs e corrupção de dados no cartão SD.

### 3.2 Lista de Materiais (BOM)

# | Componente | Interface | Função | Custo Ref.

1 | Raspberry Pi Pico 2W (RP2350) | — | Processamento e Controle RTOS | R$ 127,98
2 | Display LCD TFT 4.0" (ST7796S) | SPI | Interface Humano-Máquina | R$ 110,00
3 | Sensor Biométrico R307S | UART | Autenticação por Impressão Digital | R$ 113,00
4 | Scanner QR Code GM67 | UART | Leitura de Agendamentos 1D/2D | R$ 150,00
5 | Módulo Micro SD Card | SPI | Armazenamento de Logs e Cache | R$ 25,00
6 | Fonte USB-C 5V/2A | Power | Alimentação Estabilizada | R$ 45,00
7 | Jumpers, resistores 4k7, caps 100nF/10µF | — | Conexões e desacoplamento | ~ R$ 15,00
| TOTAL ESTIMADO | | | R$ 585,98

### 3.3 Mapeamento de Pinagem (GPIO)

Use exclusivamente as definições de board_config.h. Nunca use valores fixos no código dos drivers.

Periférico | Função | Pino Periférico | GPIO RP2350 | Observação Técnica
Display ST7796 | SPI Clock | SCK | GP18 | SPI0. Freq. < 30 MHz.
Display ST7796 | Data Out | MOSI | GP19 | Linha de vídeo (alta velocidade).
Display ST7796 | Chip Select | CS | GP17 | Seleção manual via software.
Display ST7796 | Data/Cmd | DC | GP20 | Distingue dados de comandos.

Periférico | Função | Pino Periférico | GPIO RP2350 | Observação Técnica
Display ST7796 | Reset | RST | GP21 | Reset de hardware do controlador.
Display ST7796 | Backlight | BL | GP22 | Controle de brilho via PWM.
Touch FT6336U | I2C Data | SDA | GP11 | I2C1. Pull-up 4k7 obrigatório.
Touch FT6336U | I2C Clock | SCL | GP10 | I2C1. Modo Fast (400 kHz).
Scanner GM67 | UART RX | TX | GP1 | UART0. Cruzar TX→RX.
Scanner GM67 | UART TX | RX | GP0 | UART0. Baudrate: 9600 bps.
Biometria R307S | UART RX | TX | GP8 | UART1. Baudrate fixo: 57600 bps.
Biometria R307S | UART TX | RX | GP9 | UART1. Protocolo binário c/ Checksum.
SD Card | SPI MISO | DO | GP12 | SPI1. Leitura de logs.
SD Card | SPI MOSI | DI | GP15 | SPI1. Escrita de logs LGPD.
SD Card | SPI Clock | SCK | GP14 | SPI1. Sincronização.
SD Card | Chip Select | CS | GP13 | SPI1 CSn dedicado.

// src/config/board_config.h — exemplo de definições corretas
#pragma once

// Display ST7796 — SPI0
#define PIN_DISPLAY_SCK 18 #define PIN_DISPLAY_MOSI 19

#define PIN_DISPLAY_CS | 17

#define PIN_DISPLAY_DC | 20

#define PIN_DISPLAY_RST | 21

#define PIN_DISPLAY_BL | 22

// Touch FT6336U — I2C1
#define PIN_TOUCH_SDA | 11

#define PIN_TOUCH_SCL | 10

// Scanner GM67 — UART0
#define PIN_QR_TX | 0

#define PIN_QR_RX | 1

#define QR_BAUDRATE | 9600

// Biometria R307S — UART1
#define PIN_BIO_TX | 8

#define PIN_BIO_RX | 9

#define BIO_BAUDRATE | 57600

// SD Card — SPI1
#define PIN_SD_SCK | 14

#define PIN_SD_MOSI | 15

#define PIN_SD_MISO | 12

#define PIN_SD_CS | 13

Instituto Hardware BR | suporte@hardwarebr.edu.br | Página

### 3.4 Alimentação e Gerenciamento de Energia

- Tensão de entrada: 5V DC via USB-C ou pinos VSYS
- Corrente nominal: 200–300 mA
- Pico de corrente: até 500 mA (transmissão Wi-Fi + display ativo simultaneamente)
- Desacoplamento: capacitores 100 nF (HF) e 10 µF (bulk) distribuídos no barramento
- Proteção brown-out: monitoramento interno de tensão com gravação segura antes do reset

## PARTE IV — CONFIGURAÇÃO DOS PERIFÉRICOS

### 4.1 Configuração do Scanner QR GM67 para UART

O GM67 vem configurado de fábrica no modo USB-HID (teclado virtual). Para usar com o RP2350 via UART, é obrigatório executar o procedimento de configuração uma única vez antes de montar o totem.

Parâmetros UART do GM67

Parâmetro | Configuração GM67 | Observação
Baudrate padrão | 9600 bps | Padrão de fábrica. Configurável via comando serial.
Data bits | 8 | Padrão UART.
Stop bits | 1 | Padrão UART.
Paridade | Nenhuma | Sem paridade.
Modo de saída | UART (TTL 3,3V) | Deve ser configurado; padrão de fábrica é USB-HID.
Terminador de pacote | \r\n (0x0D 0x0A) | Firmware lê até encontrar \r ou \n.
Timeout de leitura | 200 ms | Descarte pacotes sem terminador após 200 ms.

Procedimento de Configuração (via PC, uma vez por módulo)

9. Conectar o GM67 ao PC via cabo USB.
10. Abrir qualquer editor de texto simples (Bloco de Notas).
11. Com o cursor posicionado no editor, escanear o QR Code 'Enable UART Mode' do manual do fabricante GM67. O módulo emitirá um bipe de confirmação.
12. Em seguida, escanear o QR Code 'Set Baud Rate 9600' do manual do fabricante.
13. Desconectar do USB e conectar ao RP2350 conforme a pinagem (GP0/GP1). O módulo agora opera em UART 9600 bps permanentemente (salvo em memória não volátil interna).

📌

Os QR Codes de configuração estão disponíveis no manual oficial do GM67 (arquivo GM67_Barcode.pdf). Guardar uma cópia impressa deste manual junto ao estoque de reposição de módulos.

Inicialização no Firmware

// Inicialização da UART0 para o GM67 (em hal/gm67_driver.cpp)
uart_init(uart0, QR_BAUDRATE); | // 9600 bps
gpio_set_function(PIN_QR_TX, GPIO_FUNC_UART); gpio_set_function(PIN_QR_RX, GPIO_FUNC_UART); uart_set_format(uart0, 8, 1, UART_PARITY_NONE); uart_set_fifo_enabled(uart0, true);

// Configurar interrupção — NUNCA usar busy-wait em produção uart_set_irq_enables(uart0, true, false); // RX IRQ habilitado irq_set_exclusive_handler(UART0_IRQ, gm67_rx_handler); irq_set_enabled(UART0_IRQ, true);

### 4.2 Configuração do Sensor Biométrico R307S

Protocolo de Pacotes do R307S
O R307S usa um protocolo binário proprietário. O firmware verifica o Checksum de cada pacote; pacotes corrompidos são descartados e uma retransmissão é solicitada automaticamente.
Byte(s) | Campo | Valor / Descrição
0–1 | Header | 0xEF 0x01 — identificador fixo do fabricante.
2–5 | Address | 0xFF 0xFF 0xFF 0xFF — endereço de broadcast (padrão).
6 | Package ID | 0x01 = Comando | 0x02 = Dados | 0x07 = Confirmação (ACK).
7–8 | Package Length | Comprimento do campo Data + Checksum (big-endian).
9 … N-2 | Data / Instruction | Código do comando (ex: 0x01 = GetImage, 0x02 = Img2Tz).
N-1 … N | Checksum | Soma de Package ID + Package Length + Data (big-endian, 2 bytes).

Principais Comandos Utilizados

Código (Hex) | Comando | Descrição
0x01 | GetImage | Captura imagem da impressão digital do sensor óptico.
0x02 | Img2Tz(1) | Converte imagem capturada em template — armazena no buffer 1.
0x02 | Img2Tz(2) | Converte segunda captura — armazena no buffer 2 (para enroll).
0x05 | Search | Busca template no banco interno (matching 1:N). Retorna ID + score.
0x06 | RegModel | Combina buffers 1 e 2 para criar template final (uso no cadastro).
0x06 | StoreChar | Armazena template gerado na memória flash interna do módulo.
0x0D | DeleteChar | Remove template pelo ID — usado na exclusão LGPD.
0x0E | Empty | Apaga TODOS os templates (usar no factory_reset).

Inicialização no Firmware

// Inicialização da UART1 para o R307S (em hal/r307s_driver.cpp)
uart_init(uart1, BIO_BAUDRATE); | // 57600 bps — fixo de fábrica
gpio_set_function(PIN_BIO_TX, GPIO_FUNC_UART); gpio_set_function(PIN_BIO_RX, GPIO_FUNC_UART);
uart_set_format(uart1, 8, 1, UART_PARITY_NONE); uart_set_fifo_enabled(uart1, true);

// Interrupção RX — mesma abordagem do GM67 uart_set_irq_enables(uart1, true, false); irq_set_exclusive_handler(UART1_IRQ, r307s_rx_handler); irq_set_enabled(UART1_IRQ, true);

### 4.3 Procedimento de Cadastro Biométrico (Enroll)

O cadastro de um novo usuário no sensor R307S exige capturar a digital duas vezes para gerar um template confiável. Este procedimento é executado pelo técnico via menu administrativo da interface LVGL ou via script de bancada.

⚠

O cadastro biométrico deve ser realizado SOMENTE após o consentimento explícito do paciente, conforme exigido pela LGPD. O menu de enroll só é acessível com credenciais de administrador.

Fluxo de Enroll (6 etapas)

14. Enviar comando GetImage → sensor captura primeira imagem da digital.
15. Verificar ACK (confirmação byte = 0x00). Se ACK = 0x02 (dedo não detectado), repetir a etapa 1.
16. Enviar comando Img2Tz(1) → converte imagem para template no buffer 1.
17. Solicitar ao usuário que levante e reposicione o dedo. Repetir GetImage e Img2Tz(2) para o buffer 2.
18. Enviar comando RegModel → sensor combina os dois buffers e valida a qualidade do template.
19. Enviar comando StoreChar(ID) → template é salvo na memória flash do R307S com o ID do paciente. Confirmar com ACK 0x00.

// Pseudocódigo do fluxo de enroll (task_sensors.cpp)
bool enroll_user(uint16_t user_id) {
if (r307s_get_image() != ACK_OK) return false; | // 1ª captura
if (r307s_img2tz(1) | != ACK_OK) return false; | // → buffer 1
vTaskDelay(pdMS_TO_TICKS(2000)); | // usuário reposiciona
if (r307s_get_image() != ACK_OK) return false; | // 2ª captura
if (r307s_img2tz(2) | != ACK_OK) return false; | // → buffer 2
if (r307s_reg_model() != ACK_OK) return false; | // combina buffers
return r307s_store(user_id) == ACK_OK; | // grava com ID
}

## PARTE V — FIRMWARE E SOFTWARE

### 5.1 Arquitetura em Camadas

- HAL (Hardware Abstraction Layer): drivers de baixo nível: hal_wifi_rp2350.cpp, st7796_driver.cpp, r307s_driver.cpp, gm67_driver.cpp
- Serviços: logger.cpp, data_storage.cpp (FatFs), lgpd_compliance.cpp (AES, hashing)
- Tarefas FreeRTOS: TaskUI, TaskSensors, TaskWiFi, Safety Monitor — concorrência gerenciada pelo kernel
- Aplicação (FSM): Máquina de Estados Finita que governa o fluxo completo de check-in

📌 Flag obrigatória no CMakeLists.txt: set(PICO_BOARD pico2_w). Bibliotecas críticas: FreeRTOS-Kernel, lvgl (v9), no-OS-FatFS, pico-sdk v2.0+.

### 5.2 Parâmetros do FreeRTOS (FreeRTOSConfig.h)

Parâmetro | Valor | Justificativa
configCPU_CLOCK_HZ | 150000000UL | Clock do RP2350 em 150 MHz.
configTICK_RATE_HZ | 1000 | 1 ms por tick — resolução adequada para timeouts biométricos.
configMAX_PRIORITIES | 5 | Safety(4), UI(3), Sensors(2), WiFi(1), Idle(0).
configTOTAL_HEAP_SIZE | (192*1024) | 192 KB reservados. Mínimo de 20% livre em operação.
configMAX_SYSCALL_INTERR UPT_PRIORITY | (5 << 4) | Shift de 4 bits para NVIC do Cortex-M33 (4 bits de prioridade).
configUSE_MUTEXES | 1 | Obrigatório para spi_mutex e fs_mutex.
configUSE_RECURSIVE_MUTE XES | 1 | Necessário para operações FatFs aninhadas.
configENABLE_TRUSTZONE | 0 | TrustZone desabilitado na v1.1. Reservado para implementação futura.
configUSE_TASK_NOTIFICATIO NS | 1 | Comunicação leve entre ISR e tarefas.

// FreeRTOSConfig.h — trecho dos parâmetros críticos
#define configCPU_CLOCK_HZ | 150000000UL

#define configTICK_RATE_HZ | 1000

#define configMAX_PRIORITIES | 5

#define configTOTAL_HEAP_SIZE | (192 * 1024)

#define configMAX_SYSCALL_INTERRUPT_PRIORITY (5 << 4) // Cortex-M33: shift 4 bits

#define configUSE_MUTEXES | 1

#define configUSE_RECURSIVE_MUTEXES | 1

#define configUSE_TASK_NOTIFICATIONS | 1

#define configENABLE_TRUSTZONE | 0 | // v1.1: desabilitado

#define configCHECK_FOR_STACK_OVERFLOW | 2 | // modo paranóico de detecção

#define configUSE_MALLOC_FAILED_HOOK | 1 | // hook para heap esgotado

### 5.3 Tarefas FreeRTOS e Prioridades

Tarefa | Priorida de | Stack | Responsabilidade
Safety Monitor Task | 4 (Máx) | 4 KB | Alimenta o WDT a cada 100 ms. Se qualquer tarefa crítica travar, o WDT expira em 500 ms e reinicia o sistema automaticamente.
TaskUI | 3 (Alta) | 16 KB | Gerencia LVGL v9 e renderização SPI. Stack generosa para evitar overflow durante renderização de fontes e imagens.
TaskSensors | 2 (Média) | 8 KB | Monitora filas de mensagens das UARTs (QR e biometria). Decodifica pacotes e envia eventos estruturados para a FSM.
TaskWiFi | 1 (Baixa) | 8 KB | Mantém conexão via CYW43, envia logs via MQTT/HTTPS e sincroniza horário via NTP de forma assíncrona.

### 5.4 Primitivas de Sincronização

- fsm_event_queue: canal principal de eventos entre tarefas (EVENT_QR_READ, EVENT_FINGER_MATCH, EVENT_TIMEOUT)
- spi_mutex: protege o barramento SPI compartilhado entre TaskUI (display) e DataStorage (SD Card)
- fs_mutex: garante atomicidade das operações de escrita/leitura no FatFs
- wifi_status_sem: sinaliza à TaskUI quando a conexão Wi-Fi está disponível (atualiza ícone)

// Criação das primitivas — em main.cpp, antes de vTaskStartScheduler()
QueueHandle_t | fsm_event_queue = xQueueCreate(10, sizeof(fsm_event_t));
SemaphoreHandle_t spi_mutex | = xSemaphoreCreateMutex();
SemaphoreHandle_t fs_mutex | = xSemaphoreCreateRecursiveMutex();
SemaphoreHandle_t wifi_status_sem = xSemaphoreCreateBinary();

// Uso correto do spi_mutex em qualquer driver SPI:
if (xSemaphoreTake(spi_mutex, pdMS_TO_TICKS(100)) == pdTRUE) { // acesso exclusivo ao barramento SPI spi_write_blocking(spi0, data, len); xSemaphoreGive(spi_mutex);
} else {
// timeout — logar erro e retornar falha logger_error('SPI mutex timeout em task_ui'); }

### 5.5 Máquina de Estados Finita (FSM)

A FSM governa todas as transições do sistema, impedindo estados indefinidos ou coleta de dados sem autorização. Cada transição possui um temporizador de guarda — se o evento esperado não ocorrer no prazo, o sistema retorna ao estado seguro anterior.

Estados da FSM (fsm_checkin.cpp):

[IDLE]
│── toque detectado ──────────────────────► [CONSENTIMENTO] │── 'ACEITAR' pressionado ───────────► [IDENTIFICACAO] │── 'RECUSAR' ou timeout 30s ─────────► [IDLE]
│── QR Code lido (EVENT_QR_READ) ──► [VALIDACAO] │── Digital OK (EVENT_FINGER_OK) ──► [VALIDACAO] │── timeout 60s ────────────────────► [IDLE]
│── usuário encontrado ──────► [CONFIRMACAO] │── não encontrado ───────────► [ERRO]
│── exibe resultado 5s ─► [IDLE]
└── TaskWiFi envia log ─► (assíncrono)

### 5.6 Inicialização (setup_minimal)

// main.cpp — ordem obrigatória de inicialização void setup_minimal() {
// 1. Configurar clock para 150 MHz set_sys_clock_khz(150000, true);

// 2. UART de debug (logs via USB Serial, 115200 baud) stdio_usb_init();

// 3. Armar o Watchdog Timer (500 ms)
watchdog_enable(500, true); // pause_on_debug=true

// 4. Inicializar SPI1 e montar FatFs — FALHA CRÍTICA se não montar
if (!data_storage_init()) {
// LED pisca em loop — indica falha no SD Card
while(true) { gpio_put(LED_PIN, !gpio_get(LED_PIN)); sleep_ms(200); } }

// 5. Inicializar drivers de periféricos
st7796_init();
ft6336u_init();
r307s_init();
gm67_init();

// 6. Criar primitivas do FreeRTOS
fsm_event_queue = xQueueCreate(10, sizeof(fsm_event_t));
spi_mutex | = xSemaphoreCreateMutex();
fs_mutex | = xSemaphoreCreateRecursiveMutex();

// 7. Criar tarefas
xTaskCreate(task_ui, | 'UI', | 16384, NULL, 3, NULL);
xTaskCreate(task_sensors, 'Sensors', 8192, NULL, 2, NULL);
xTaskCreate(task_wifi, | 'WiFi', | 8192, NULL, 1, NULL);
xTaskCreate(task_watchdog, 'WDT', | 4096, NULL, 4, NULL);

// 8. Transferir controle para o FreeRTOS vTaskStartScheduler(); // nunca retorna
}

## PARTE VI — CONFORMIDADE COM A LGPD

### 6.1 Princípios Aplicados

- Minimização de dados: coletados apenas os dados necessários para o check-in
- Consentimento explícito: firmware bloqueia fisicamente os sensores até confirmação. Inatividade de 30 s retorna ao IDLE sem coleta.
- Anonimização biométrica: DSP interno do R307S converte imagem em template matemático. Hash AES aplicado antes de qualquer persistência — reconstrução da digital é tecnicamente impossível.
- Criptografia em repouso: volume do SD Card protegido por AES simétrico
- Segurança em trânsito: HTTPS ou MQTT com TLS, aproveitando acelerador SHA-256 do RP2350

### 6.2 Estrutura do Log de Auditoria

📋 Formato de cada registro: TIMESTAMP | DEVICE_ID | EVENT_TYPE | USER_HASH_SHA256 | STATUS

Dados de QR Code contendo informações pessoais são processados apenas em memória volátil e descartados após validação, sem persistência em disco.

### 6.3 Exclusão de Dados (Direito à Remoção)

20. Para excluir um usuário específico: acessar menu de administrador → 'Gerenciar Usuários'
| → 'Excluir' → confirmar ID. O firmware executa o comando DeleteChar(ID) no R307S e remove o hash correspondente do log.
21. Para limpeza total (descarte do equipamento): criar arquivo vazio chamado
| factory_reset.flag na raiz do SD Card e reiniciar. O firmware detecta o arquivo, executa o comando Empty no R307S, apaga todos os logs criptografados e remove o arquivo de flag.

⚠

| O procedimento de factory_reset é irreversível. Fazer backup dos logs de auditoria LGPD antes de executar, se necessário para fins jurídicos.

## PARTE VII — INSTALAÇÃO E COMISSIONAMENTO

### 7.1 Checklist Completo de Instalação

Pas so | Atividade | Descrição Técnica | Critério de Sucesso
1 | Montagem Física | Fixar totem em local seco e ventilado. Evitar luz solar direta sobre o leitor GM67 (saturação óptica). | Gabinete estável e leitor livre de reflexos.
2 | Energização | Conectar fonte USB-C 5V/2A. Verificar conexão do pino VBUS para backlight e scanner QR. | LED de Power aceso. Backlight ativo sem cintilação.
3 | Setup SD Card | Formatar MicroSD Classe 10 em FAT32. Criar arquivo wifi_config.txt na raiz com SSID= e PASS=. | Arquivo salvo sem extensões ocultas.
4 | Inserção SD | Com sistema desligado, inserir cartão no slot SPI1. Nunca remover com sistema energizado. | Slot travado e cartão firmemente posicionado.
5 | Flash Firmware | Conectar USB ao PC segurando BOOTSEL. Arrastar .uf2 para unidade virtual RP2350. | Dispositivo reinicia e LED verde pisca 3 vezes.
6 | Configuração Rede | Sistema lê wifi_config.txt e tenta conexão. Status no ícone Wi-Fi da interface LVGL. | Ícone Wi-Fi ativo na barra de status.
7 | Teste Biométrico | Acessar menu técnico e realizar leitura de teste. R307S deve acender luz azul. | Mensagem 'Sensor Ok' e ID reconhecido na tela.
8 | Validação LGPD | Iniciar fluxo normal. Verificar se sistema solicita consentimento antes de ativar scanner. | Scanner só emite luz de leitura após 'ACEITAR'.

### 7.2 Arquivo wifi_config.txt

Criar na raiz do SD Card com exatamente o seguinte formato (sem espaços ao redor do '='):

SSID=NomeDaSuaRede
PASS=SuaSenhaWifi

⚠

Verificar se o sistema operacional não adicionou extensão oculta (.txt.txt). O firmware não processará o arquivo se o nome estiver incorreto. No Windows, ativar 'Mostrar extensões de arquivo' nas opções de pasta.

### 7.3 Configuração do GM67 para UART (antes de montar)

Ver seção 4.1 deste manual para o procedimento completo de configuração do GM67 de USB-HID para UART. Este passo é obrigatório e deve ser executado antes de montar o scanner no totem.

## PARTE VIII — MANUTENÇÃO E TROUBLESHOOTING

### 8.1 Logs e Diagnóstico

A análise de falhas sempre começa pelo arquivo system_error.log no SD Card. Para diagnóstico em tempo real, conectar via USB Serial (115.200 baud).

### 8.2 Tabela de Troubleshooting

Sintoma | Causa Provável | Ação Corretiva
Tela 'Offline' | Perda de conexão Wi-Fi. | Sistema opera em contingência. Dados salvos no SD. Upload automático ao retornar sinal.
Biometria Não Responsiva | Sujidade na janela óptica ou oscilação em 3,3V. | Limpar com microfibra seca. Verificar conectores GP8/GP9. Fallback para QR Code.
Erro de Escrita no SD | Corrupção FatFs. | Substituir cartão por pSLC. Verificar system_error.log.
Display sem imagem | Falha no driver SPI0 ou cabo CS. | Verificar GP17 (CS) e GP18 (SCK). Conferir tensão VBUS no backlight.
LED pisca sem parar | Erro crítico na inicialização. | Verificar system_error.log. Reconectar periféricos UART. Reflash se necessário.
QR Code não lido | GM67 ainda em modo USB-HID. | Executar procedimento de configuração UART do GM67 (seção 7.3).
Watchdog reiniciando em loop | Deadlock em tarefa crítica. | Conectar Serial 115200 baud e inspecionar logs de stack. Verificar spi_mutex.

### 8.3 Atualização de Firmware

22. Compilar e validar o novo firmware em protótipo de bancada antes de implantar em produção.
23. Verificar flag PICO_BOARD=pico2_w no CMakeLists.txt.
24. Seguir o procedimento de flash da seção 2.7.

📌

Bibliotecas críticas no CMakeLists.txt: FreeRTOS-Kernel, lvgl (v9), no-OS-FatFS. Qualquer atualização de versão dessas bibliotecas deve passar por teste completo de 24h de estabilidade antes de produção.

### 8.4 Monitoramento de Saúde (Métricas de Produção)

- Heap livre: deve permanecer acima de 20% após 1h de uso contínuo. Verificar via log 'HEAP_FREE_KB'
- Stack watermark: inspecionar com uxTaskGetStackHighWaterMark() periodicamente
- Temperatura do enclosure: manter abaixo de 45°C para garantir operação confiável do RP2350
- Ciclos de escrita do SD: substituição preventiva a cada 2 anos por modelo pSLC em uso intensivo
- Sensor biométrico: limpeza mensal da janela óptica com microfibra seca

- Conectores UART: inspeção trimestral dos cabos GP8/GP9 e GP0/GP1

## Glossário Técnico

- ACK: Acknowledgement — confirmação de recebimento de pacote
- AES: Advanced Encryption Standard — algoritmo de criptografia simétrica
- BOOTSEL: Boot Select — botão do Pico 2W para entrar em modo de gravação USB
- DMA: Direct Memory Access — transferência de dados sem intervenção da CPU
- DSP: Digital Signal Processor — processador de sinais digitais (integrado ao R307S)
- FAR: False Acceptance Rate — taxa de falsa aceitação biométrica
- FatFs: biblioteca de sistema de arquivos FAT para sistemas embarcados
- FSM: Finite State Machine — Máquina de Estados Finita
- GPIO: General Purpose Input/Output — pino de propósito geral do microcontrolador
- HAL: Hardware Abstraction Layer — camada de abstração de hardware
- IoMT: Internet of Medical Things — Internet das Coisas Médicas
- IRQ: Interrupt Request — solicitação de interrupção de hardware
- LGPD: Lei Geral de Proteção de Dados — Lei 13.709/2018
- LVGL: Light and Versatile Graphics Library — biblioteca gráfica para embarcados
- MPU: Memory Protection Unit — unidade de proteção de memória do ARM
- MQTT: Message Queuing Telemetry Transport — protocolo leve de telemetria IoT
- NTP: Network Time Protocol — sincronização de relógio via rede
- OTA: Over-the-Air — atualização de firmware por rede
- pSLC: pseudo Single Level Cell — tecnologia de SD Card de grau industrial
- SDK: Software Development Kit — kit de desenvolvimento de software
- TrustZone: tecnologia ARM de isolamento de execução segura no RP2350
- UF2: USB Flashing Format — formato de arquivo de firmware para gravação via USB
- WDT: Watchdog Timer — temporizador de hardware que reinicia o sistema em caso de travamento
Suporte Técnico: Instituto Hardware BR | suporte@hardwarebr.edu.br

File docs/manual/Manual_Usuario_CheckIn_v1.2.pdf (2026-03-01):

MANUAL DO USUÁRIO | Sistema de Check-In Inteligente

# INSTITUTO HARDWARE BR

EMBARCATEH – Campinas, SP

# MANUAL DO USUÁRIO

## Sistema de Check-In Inteligente

## para Clínicas Médicas

Destinado a: Pacientes, Recepcionistas e Administradores da Clínica
Versão: 1.2 | Fevereiro de 2026
Responsável: Adriana Rocha Castro de Paula e Luana Menezes
Instituto Hardware BR | suporte@hardwarebr.edu.br | Página 1

## Bem-vindo ao Totem de Check-In

Este totem foi desenvolvido para tornar o seu atendimento mais ágil e confortável. Com ele, você confirma sua presença na clínica em segundos, sem filas na recepção.

✅ Rápido e simples
O processo completo de check-in leva menos de 5 segundos. A tela sensível ao toque guia você em cada etapa com instruções claras.

🔒 Seus dados estão protegidos
Em conformidade com a Lei Geral de Proteção de Dados (LGPD). Sua impressão digital nunca é armazenada como imagem — apenas como um código matemático irreversível.

📞 Precisa de ajuda?
A equipe da recepção está sempre disponível caso você encontre qualquer dificuldade com o totem.

## 1. Antes de Usar o Totem — O que você precisa saber

### 1.1 Para quem é este totem?

O totem é para pacientes com consulta ou exame agendado. Ele confirma sua chegada e gera a sua senha de atendimento. Se você ainda não tem um agendamento, dirija-se à recepção.

### 1.2 Como funciona a identificação?

Existem dois métodos de identificação. Você pode usar qualquer um dos dois:

Método | O que é | Quando usar
Biometria (digital) | Leitura da impressão digital no sensor luminoso localizado abaixo da tela. | Pacientes com digital já cadastrada no sistema da clínica.
QR Code | Leitura do código QR enviado no comprovante de agendamento. | Todos os pacientes. Ideal para quem ainda não tem a digital cadastrada.

ℹ️ Primeira consulta na clínica?
Se é sua primeira vez, sua digital pode ainda não estar cadastrada no sistema. Use o QR Code do agendamento. Ao final do atendimento, a recepção pode fazer o cadastro da sua digital para as próximas visitas.

### 1.3 Onde está o QR Code do meu agendamento?

Ao confirmar sua consulta, a clínica envia um comprovante de agendamento. O QR Code está nesse comprovante. Verifique:

- E-mail: o comprovante chega como imagem ou PDF no corpo da mensagem.
- WhatsApp: mensagem com imagem do QR Code ou link para o comprovante.
- Impresso: se você agendou presencialmente, a recepcionista pode imprimir o comprovante.

⚠️ Não encontrou o QR Code?
Chame a recepção. A equipe localiza seu agendamento pelo nome e CPF e realiza o
check-in manualmente. Você não perderá sua vez.

## 2. Como Fazer seu Check-In — Passo a Passo

Siga as instruções na tela touch de 4.0". O sistema exibe instruções visuais em cada etapa.

1

Toque na tela para iniciar
Ao se aproximar do totem, a tela de boas-vindas estará ativa. Toque em qualquer área da tela para começar. O sistema está pronto quando exibir a mensagem 'Toque para iniciar'.

2

Leia o Termo de Consentimento (LGPD)
Uma tela com os Termos de Uso será exibida. Leia o texto e toque em ACEITAR para prosseguir. Se tocar em RECUSAR ou não interagir por 30 segundos, o sistema retorna ao início e nenhum dado é coletado.

3

Identifique-se (escolha Biometria ou QR Code)
Opção A — Biometria: posicione o dedo indicador direito com suavidade sobre o sensor luminoso abaixo da tela. Aguarde o sinal sonoro (bip) ou a mensagem na tela.Opção B — QR Code: abra o comprovante de agendamento no celular (ou use a versão impressa). Aponte o código para o leitor óptico, mantendo distância de 10 a 15 cm. Aguarde a leitura.

4

Confirmação do check-in
A tela exibirá a mensagem 'Check-In Realizado com Sucesso' com o número da sua senha de atendimento. Anote ou memorize o número exibido.

5

Aguarde seu chamado na sala de espera
Dirija-se à sala de espera indicada na tela ou sinalizada pela recepção. Sua senha será chamada em voz alta pelo(a) recepcionista ou exibida no painel de senhas.

✅ Check-in concluído!
Após a confirmação na tela, seu atendimento já está registrado no sistema. Não é necessário ir à recepção antes de ser chamado, a menos que você tenha dúvidas ou necessite de assistência.

## 3. Primeira Visita — Paciente Novo

### 3.1 Fluxo para quem nunca usou o totem

Se é sua primeira consulta nesta clínica, siga estas orientações:

1. Use o QR Code enviado no comprovante de agendamento para se identificar (a digital ainda não está cadastrada).
2. Realize o check-in normalmente pelo QR Code seguindo os passos da seção 2.
3. Após o atendimento — ou se desejar agilizar futuras visitas — solicite à recepção o cadastro da sua impressão digital. O processo leva menos de 2 minutos.

ℹ️ Cadastro de biometria
O cadastro é voluntário e pode ser feito a qualquer momento. Após cadastrado, você poderá fazer check-in apenas encostando o dedo no sensor, sem precisar do celular ou do comprovante impresso.

### 3.2 Acompanhantes e pacientes menores de idade

Para pacientes menores de idade ou que precisem de auxílio:

- O responsável legal realiza o check-in usando o QR Code do agendamento do menor.
- Se o menor já tiver biometria cadastrada, o responsável pode posicionar o dedo da criança no sensor.
- Em qualquer caso, a recepção pode realizar o check-in manualmente mediante apresentação do nome e data de nascimento do paciente.

## 4. Acessibilidade

### 4.1 Cadeirantes e mobilidade reduzida

O totem possui altura de tela e sensor posicionados para permitir uso a partir de cadeira de rodas. O sensor biométrico está localizado na parte frontal inferior do equipamento, acessível sem necessidade de se levantar.

📞 Precisa de assistência adicional?
Informe a recepção ao chegar. Um(a) atendente poderá auxiliar no uso do totem ou realizar o check-in diretamente na recepção, garantindo sua prioridade no atendimento.

### 4.2 Idosos e pessoas com dificuldade de visão

A interface do totem utiliza letras grandes e ícones coloridos para facilitar a leitura. Caso tenha dificuldade de enxergar a tela:

- Aproxime-se mais do totem — a tela é sensível ao toque em toda a sua superfície.
- Peça ajuda a um acompanhante ou chame a recepção.
- O check-in também pode ser realizado pela recepção, sem nenhum prejuízo ao atendimento.

### 4.3 Dificuldade com biometria (mãos úmidas, calosidades ou lesões)

Algumas condições podem dificultar a leitura da impressão digital, como:

- Mãos muito úmidas (suadas) ou muito secas — seque ou umedeça levemente o dedo antes da leitura.
- Calosidades por trabalho manual ou esportes — tente outros dedos (indicador esquerdo ou médio).
- Lesões, curativos ou unhas compridas cobrindo a polpa digital.

Nesses casos, use sempre o QR Code como alternativa. Se o problema for permanente, informe a recepção para que seu cadastro seja feito de forma especial.

## 5. Após o Check-In — O que esperar

### 5.1 Sua senha de atendimento

Ao concluir o check-in, o totem exibirá o número da sua senha de atendimento na tela. Guarde esse número — ele é a sua posição na fila de espera.

O que aparece na tela | O que significa
Senha: A-023 | Sua posição na fila. Você será chamado quando este número for anunciado.
Sala de espera: Ala B | Local onde você deve aguardar até ser chamado.
Estimativa: ~15 minutos | Tempo estimado de espera com base na fila atual (pode variar).
Check-in realizado às 14h32 | Horário registrado no sistema para fins de controle de atendimento.

⚠️ Importante
Após o check-in, dirija-se imediatamente à sala de espera indicada. Não saia da clínica — se sua senha for chamada e você não estiver presente, poderá perder sua vez na fila.

### 5.2 Como seu nome/senha será chamado

O chamado ao atendimento ocorre de uma das seguintes formas, dependendo da estrutura da clínica:

- Anúncio em voz alta pela recepcionista ou pelo sistema de som da clínica.
- Exibição no painel digital de senhas na sala de espera (se disponível).
- Chamado presencial pelo(a) enfermeiro(a) ou médico(a) diretamente na sala de espera.

Em caso de dúvida sobre sua posição na fila, pergunte à recepção informando o número da senha exibida no totem.

### 5.3 Se precisar sair temporariamente

Se precisar se ausentar brevemente (banheiro, estacionamento), informe a recepção antes de sair e diga o número da sua senha. A equipe poderá recolocar você na fila sem perda de posição, dependendo da disponibilidade.

## 6. Seus Dados e Privacidade (LGPD)

Este equipamento está em total conformidade com a Lei Geral de Proteção de Dados (Lei 13.709/2018). Veja em detalhes como suas informações são tratadas:

O que coletamos | Como protegemos | Seus direitos
Apenas o necessário para confirmar seu agendamento: identificação via biometria ou QR Code. | Sua digital nunca é armazenada como imagem. É convertida em código matemático (hash) irreversível. Todos os dados são criptografados. | Solicite exclusão dos seus dados biométricos na recepção a qualquer momento. Prazo: até 24 horas.

### 6.1 O que NÃO é armazenado

- Imagem da sua impressão digital — nunca é salva em nenhum formato.
- Foto ou vídeo seu — o totem não possui câmera.
- Conteúdo da sua consulta ou diagnóstico médico.
- Dados de pagamento ou informações financeiras.

### 6.2 Como solicitar exclusão dos seus dados

4. Dirija-se à recepção da clínica e solicite a exclusão dos seus dados biométricos.
5. Informe nome completo e CPF para localização do cadastro.
6. A exclusão no sistema local será realizada em até 24 horas.
7. Você receberá confirmação da exclusão pela recepção ou por e-mail/WhatsApp.

ℹ️ Após a exclusão
Você ainda poderá usar o totem pelo QR Code do agendamento. Apenas a biometria ficará indisponível até um novo cadastro, caso deseje.

## 7. Solução de Problemas

Consulte a tabela abaixo se encontrar alguma dificuldade. Na maioria dos casos, a situação se resolve sozinha em segundos:

Problema | O que provavelmente aconteceu | O que fazer
Tela congelada | Travamento temporário do software. | Aguarde 5 segundos. O sistema reinicia automaticamente.
Biometria não lê meu dedo | Dedo seco, úmido, sujo ou digital não cadastrada. | Limpe o dedo com pano seco e tente novamente. Se não funcionar, use o QR Code ou chame a recepção.
QR Code não é reconhecido | Tela do celular com brilho baixo ou muita luz no ambiente. | Aumente o brilho da tela. Mantenha 10–15 cm de distância. Tente inclinar levemente o celular.
'Usuário não encontrado' | Dados do agendamento não localizados ou digital não cadastrada no sistema. | Dirija-se à recepção. O atendimento será feito manualmente. Informe nome e horário da consulta.
Ícone Wi-Fi vermelho na tela | Falha temporária na rede da clínica. | Continue normalmente. O sistema salva seu check-in e sincroniza ao retornar a rede.
Mensagem 'Sistema indisponível' | Reinicialização automática em andamento. | Aguarde 30 segundos e tente novamente. Se persistir, chame a recepção.

📞 Nenhuma solução funcionou?
Chame a recepção. O atendimento pode sempre ser feito manualmente e você não perderá sua vez na fila.

## 8. Dicas para um Check-In Perfeito

Dicas para Biometria
- Use o dedo indicador direito — é o padrão de cadastro. Se não funcionar, tente o indicador esquerdo.
- Posicione o dedo com suavidade, sem pressionar com força. O sensor é óptico, não de pressão.
- Centralize a polpa digital (a parte mais macia do dedo) sobre o sensor luminoso.
- Se o dedo estiver muito seco, sopre levemente sobre ele antes de tentar.
- Se o dedo estiver suado, seque-o com um lenço seco antes de tentar.

Dicas para QR Code
- Aumente o brilho da tela do celular ao máximo antes de aproximar do leitor.
- Mantenha distância de 10 a 15 cm entre o celular e o leitor óptico.
- Evite inclinar o celular mais de 45 graus — mantenha-o o mais paralelo possível ao leitor.
- Em ambientes muito iluminados, tente sombrear levemente o leitor com a outra mão.
- Se usar a versão impressa, evite dobras ou amassados sobre o QR Code.

Dicas Gerais
- Chegue com alguns minutos de antecedência para ter tempo de fazer o check-in com calma.
- Tenha o comprovante de agendamento aberto no celular antes de chegar ao totem.
- Se houver fila no totem, aguarde distância respeitosa — a tela exibe informações pessoais.
- Após o check-in, anote o número da sua senha antes de se afastar do totem.
Instituto Hardware BR | suporte@hardwarebr.edu.br | Página
10

## 9. Perguntas Frequentes

Pergunta | Resposta
Preciso fazer o check-in se já me identifiquei na entrada? | Sim. O check-in no totem confirma sua presença para o sistema de atendimento da clínica e gera sua senha de espera.
Posso fazer o check-in de outra pessoa? | Não. O sistema identifica cada paciente individualmente por biometria ou QR Code pessoal. Em caso de necessidade, a recepção realiza o check-in manualmente.
Minha consulta foi reagendada. O QR Code muda? | Sim. Ao reagendar, um novo QR Code é gerado. Verifique o e-mail ou WhatsApp com a confirmação do novo horário.
E se eu perder o QR Code? | Chame a recepção. A equipe localiza seu agendamento pelo nome e CPF e faz o check-in manualmente.
Meus dados ficam no totem após o check-in? | Não. Dados pessoais do QR Code são processados apenas na memória temporária e descartados imediatamente. Apenas um código matemático anônimo fica registrado no log.
O totem funciona para consultas de crianças? | Sim, com acompanhante. O responsável realiza o check-in pela biometria ou QR Code do agendamento do menor.
Posso usar o totem em cadeira de rodas? | O totem possui altura ajustada para acessibilidade. Caso encontre dificuldade, a recepção realizará o atendimento com prioridade.
Instituto Hardware BR | EMBARCATEH Campinas-SP | suporte@hardwarebr.edu.br
Versão 1.2 — Fevereiro de 2026 | Em conformidade com a LGPD (Lei 13.709/2018)
Instituto Hardware BR | suporte@hardwarebr.edu.br | Página
11

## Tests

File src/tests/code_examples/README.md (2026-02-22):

# Demo Examples

This folder contains standalone demo programs to test individual hardware components and features.

## Available Demos

1. **LVGL RTOS Demo** - Tests the display and touch screen with LVGL widgets
2. **QR Code Reader Demo** - Tests the QR code scanner
3. **Fingerprint Demo** - Tests the fingerprint sensor
4. **SD Card FatFS Demo** - Tests SD card read/write operations
5. **WiFi Demo** - Tests WiFi connectivity and networking features

## How to Run a Demo

### Step 1: Select the Demo

Edit the `CMakeLists.txt` file in the project root and change the `BUILD_TARGET` variable:

```cmake
set(BUILD_TARGET "SDCARD_DEMO" CACHE STRING "...")
```

Available options:
- `"LVGL_DEMO"` - LVGL RTOS demo
- `"QR_DEMO"` - QR code reader demo
- `"FINGERPRINT_DEMO"` - Fingerprint demo
- `"SDCARD_DEMO"` - SD card FatFS demo
- `"WIFI_DEMO"` - WiFi connectivity demo
- `"MAIN"` - Main application (default)

### Step 2: Compile the Project

Run the "Compile Project" task:
- Press `Ctrl+Shift+P` (or `Cmd+Shift+P` on Mac)
- Type "Tasks: Run Task"
- Select "Compile Project"

Or use the terminal:
```bash
cmake -B build
ninja -C build
```

### Step 3: Upload to Pico

Run the "Run Project" task:
- Press `Ctrl+Shift+P`
- Type "Tasks: Run Task"
- Select "Run Project"

Or manually copy the `.uf2` file:
1. Hold BOOTSEL button while connecting the Pico
2. Copy `build/medical-clinic-checkin-pico.uf2` to the RPI-RP2 drive

### Step 4: Monitor Serial Output

Connect to the USB serial port to see debug output:

```bash
minicom -D /dev/ttyACM0
```

Or use any serial terminal (115200 baud, 8N1).

---

## Demo Details

### 1. LVGL RTOS Demo (`lvgl_rtos_demo.cpp`)

**What it does:**
- Initializes the ST7796 display driver
- Initializes the FT6336U touch controller
- Runs LVGL's demo widgets with FreeRTOS

**Hardware required:**
- ST7796 display (480x320)
- FT6336U touch panel
- SPI and I2C connections

**Expected output:**
- Display shows LVGL demo widgets
- Touch screen is responsive
- LED blinks once per second

---

### 2. QR Code Reader Demo (`qr_code_reader_demo.cpp`)

**What it does:**
- Initializes the GM67 QR code scanner
- Continuously scans for QR codes
- Prints scanned data to serial console

**Hardware required:**
- GM67 QR code scanner module
- UART connection (default: UART1)

**Expected output:**
```
=== QR Scanner Test ===
UART1 @ 9600 baud (TX=4, RX=5)

Initializing scanner...
Ready!

>>> QR: https://example.com
>>> QR: 1234567890
```

**Usage:**
- Point QR codes at the scanner
- Scanned data appears in the serial console
- LED blinks every 500ms

---

### 3. Fingerprint Demo (`fingerprint_demo.cpp`)

**What it does:**
- Initializes the R307S fingerprint sensor
- Interactive menu to enroll, verify, search, and delete fingerprints
- Manages fingerprint database

**Hardware required:**
- R307S fingerprint sensor module
- UART connection (default: UART0)

**Expected output:**
```
=============================
  R307S Fingerprint Demo
=============================
UART0 @ 57600 baud (TX=0, RX=1)

Initializing R307S fingerprint sensor...
Sensor ready
Current stored fingerprints: 0

====== Fingerprint Menu ====
1. Enroll new fingerprint
2. Verify fingerprint
3. Search fingerprint
4. Delete fingerprint by ID
5. Clear all fingerprints
6. Get template count
7. Read system parameters
0. Show menu
==============================
Enter option:
```

**Menu options:**
1. **Enroll** - Register a new fingerprint with an ID (1-1000)
2. **Verify** - Check if a finger matches a specific ID
3. **Search** - Find which ID matches the current finger
4. **Delete** - Remove a fingerprint by ID
5. **Clear all** - Erase entire fingerprint database
6. **Count** - Show how many fingerprints are stored
7. **Parameters** - Display sensor information

**Usage tips:**
- Follow on-screen instructions carefully
- Place finger firmly on sensor
- Use same finger position for both enrollment scans
- LED blinks once per second during operation

---

### 4. SD Card FatFS Demo (`sdcard_fatfs_demo.cpp`)

**What it does:**
- Mounts SD card using FatFS library
- Performs various file operations:
  - Write text file
  - Read text file
  - Append to log file
  - Get file information
  - Show storage statistics
  - List directory contents

**Hardware required:**
- SD card module
- SPI connection
- SD card formatted as FAT32

**Expected output:**
```
--- SD Card FatFS Demo ---
Build: Nov 9 2025 10:30:00

Initializing SD card...
Mounting filesystem...
Filesystem mounted ok

Test 1: Writing to file
Opening test.txt...
File opened
Writing data...
Wrote 71 bytes
File closed

Test 2: Reading from file
Opening test.txt...
File opened

--- File content:
Hello from RP2040!
SD card is working!
Medical Clinic Check-in System
--- End

File closed

Test 3: Appending to file
[... additional tests ...]

Demo complete. Files created:
  - test.txt
  - log.txt
```

**Files created on SD card:**
- `test.txt` - Test file with sample text
- `log.txt` - Log file with timestamps

**Troubleshooting:**
If you see "f_mount failed":
- Check that SD card is properly inserted
- Verify SD card is formatted as FAT32
- Check SPI wiring connections
- Try a different SD card

---

### 5. WiFi Demo (`wifi_demo.cpp`)

**What it does:**
- Initializes the CYW43439 WiFi chip
- Connects to a WiFi network
- Demonstrates all WiFi HAL functions:
  - Network information (IP, MAC, SSID, RSSI)
  - WiFi scanning
  - DNS resolution
  - TCP echo server
  - Signal strength monitoring

**Hardware required:**
- Raspberry Pi Pico W (with CYW43439 WiFi chip)
- WiFi network (2.4 GHz)

**Configuration:**
Edit `config/wifi_config.hpp` with your WiFi credentials:
```cpp
#define WIFI_SSID "YourNetworkName"
#define WIFI_PASSWORD "YourPassword"
#define WIFI_COUNTRY_CODE "BR"  // Your country code
```

**Expected output:**
```
*****************STARTING********************

Step 1: Initializing WiFi...
Creating WiFi HAL instance...
Initializing CYW43 driver (country: BR)...
SUCCESS: WiFi initialized

Step 2: Connecting to WiFi...
Network: YourNetworkName
Security: WPA2-AES
Attempting connection (timeout: 30000 ms)...
SUCCESS: Connected to network

Step 3: Displaying network info...
Querying network interface...
IP Address: 192.168.0.11
MAC Address: 28:CD:C1:XX:XX:XX
SSID: YourNetworkName
Signal Strength: -46 dBm
SUCCESS: Network info displayed

Step 4: Scanning WiFi networks...
Starting active scan (timeout: 10s)...
Found 10 network(s)

#   SSID                             Ch   Signal    Security
--- -------------------------------- ---- -------- ----------
1   YourNetworkName                  6    -46 dBm  WPA2
2   NeighborWiFi                     11   -62 dBm  WPA2
3   PublicWiFi                       1    -75 dBm  OPEN
...
SUCCESS: WiFi scan completed

Step 5: Testing DNS connectivity...
Target: google.com
Resolving hostname...
SUCCESS: DNS resolved

Step 6: Starting TCP echo server...
Creating TCP server on port 7...
Echo server on port 7
SUCCESS: Echo server running on port 7
Usage: telnet <pico-ip> 7

Step 7: Sampling RSSI...
Collecting 5 signal strength samples (1s interval)...
Sample 1: RSSI = -46 dBm
Sample 2: RSSI = -47 dBm
Sample 3: RSSI = -46 dBm
Sample 4: RSSI = -45 dBm
Sample 5: RSSI = -46 dBm
SUCCESS: RSSI samples complete

Demo completed.
Cleaning up WiFi HAL...
```

**Features tested:**
1. ✅ WiFi initialization with country code
2. ✅ WPA2 network connection
3. ✅ DHCP IP address assignment
4. ✅ MAC address retrieval
5. ✅ Active network scanning
6. ✅ DNS hostname resolution
7. ✅ TCP server (echo on port 7)
8. ✅ RSSI signal strength measurement
9. ✅ LED control via CYW43 chip

**Testing the TCP echo server:**
After the demo starts the server, you can test it from your computer:
```bash
# Replace <pico-ip> with the IP address shown in the output
telnet 192.168.0.11 7

# Type any text and press Enter
# The server will echo it back
```

**Signal strength (RSSI) interpretation:**
- `-30` to `-50 dBm`: Excellent signal
- `-50` to `-70 dBm`: Good signal
- `-70` to `-80 dBm`: Weak signal
- Below `-80 dBm`: Very weak (may have connection issues)

**Troubleshooting:**

If you see **"ERROR: WiFi initialization failed"**:
- Make sure you're using a Pico W (not a regular Pico)
- Verify the country code is valid (e.g., "BR", "US", "JP")

If you see **"ERROR: Connection failed"**:
- Check SSID and password in `wifi_config.hpp`
- Ensure the network is 2.4 GHz (5 GHz is not supported)
- Verify WPA2 security mode matches your network
- Check if signal strength is sufficient (> -80 dBm)
- Increase timeout if network is slow to respond

**Additional documentation:**
- See `/docs/dev/wifi/como_funciona_wifi.md` for detailed WiFi architecture
- HAL implementation: `/src/hal/rp2040/hal_wifi_rp2040.cpp`
- lwIP configuration: `/config/lwipopts.h`

---

## Switching Back to Main Application

To return to the main application, change `BUILD_TARGET` back to `"MAIN"`:

```cmake
set(BUILD_TARGET "MAIN" CACHE STRING "...")
```

Then recompile and upload.

---

## Hardware Connections

Refer to `config/pin_config.hpp` for the exact GPIO pin assignments for each component.

## Troubleshooting

**Problem:** Demo doesn't compile
- **Solution:** Make sure you saved the `CMakeLists.txt` file after changing `BUILD_TARGET`

**Problem:** No serial output
- **Solution:** USB stdio is enabled. Connect to the USB serial port (usually `/dev/ttyACM0` on Linux)

**Problem:** Hardware not responding
- **Solution:** Check wiring and power connections. Verify pin assignments in `config/pin_config.hpp`

**Problem:** Pico won't connect
- **Solution:** Hold BOOTSEL button while plugging in USB to enter bootloader mode

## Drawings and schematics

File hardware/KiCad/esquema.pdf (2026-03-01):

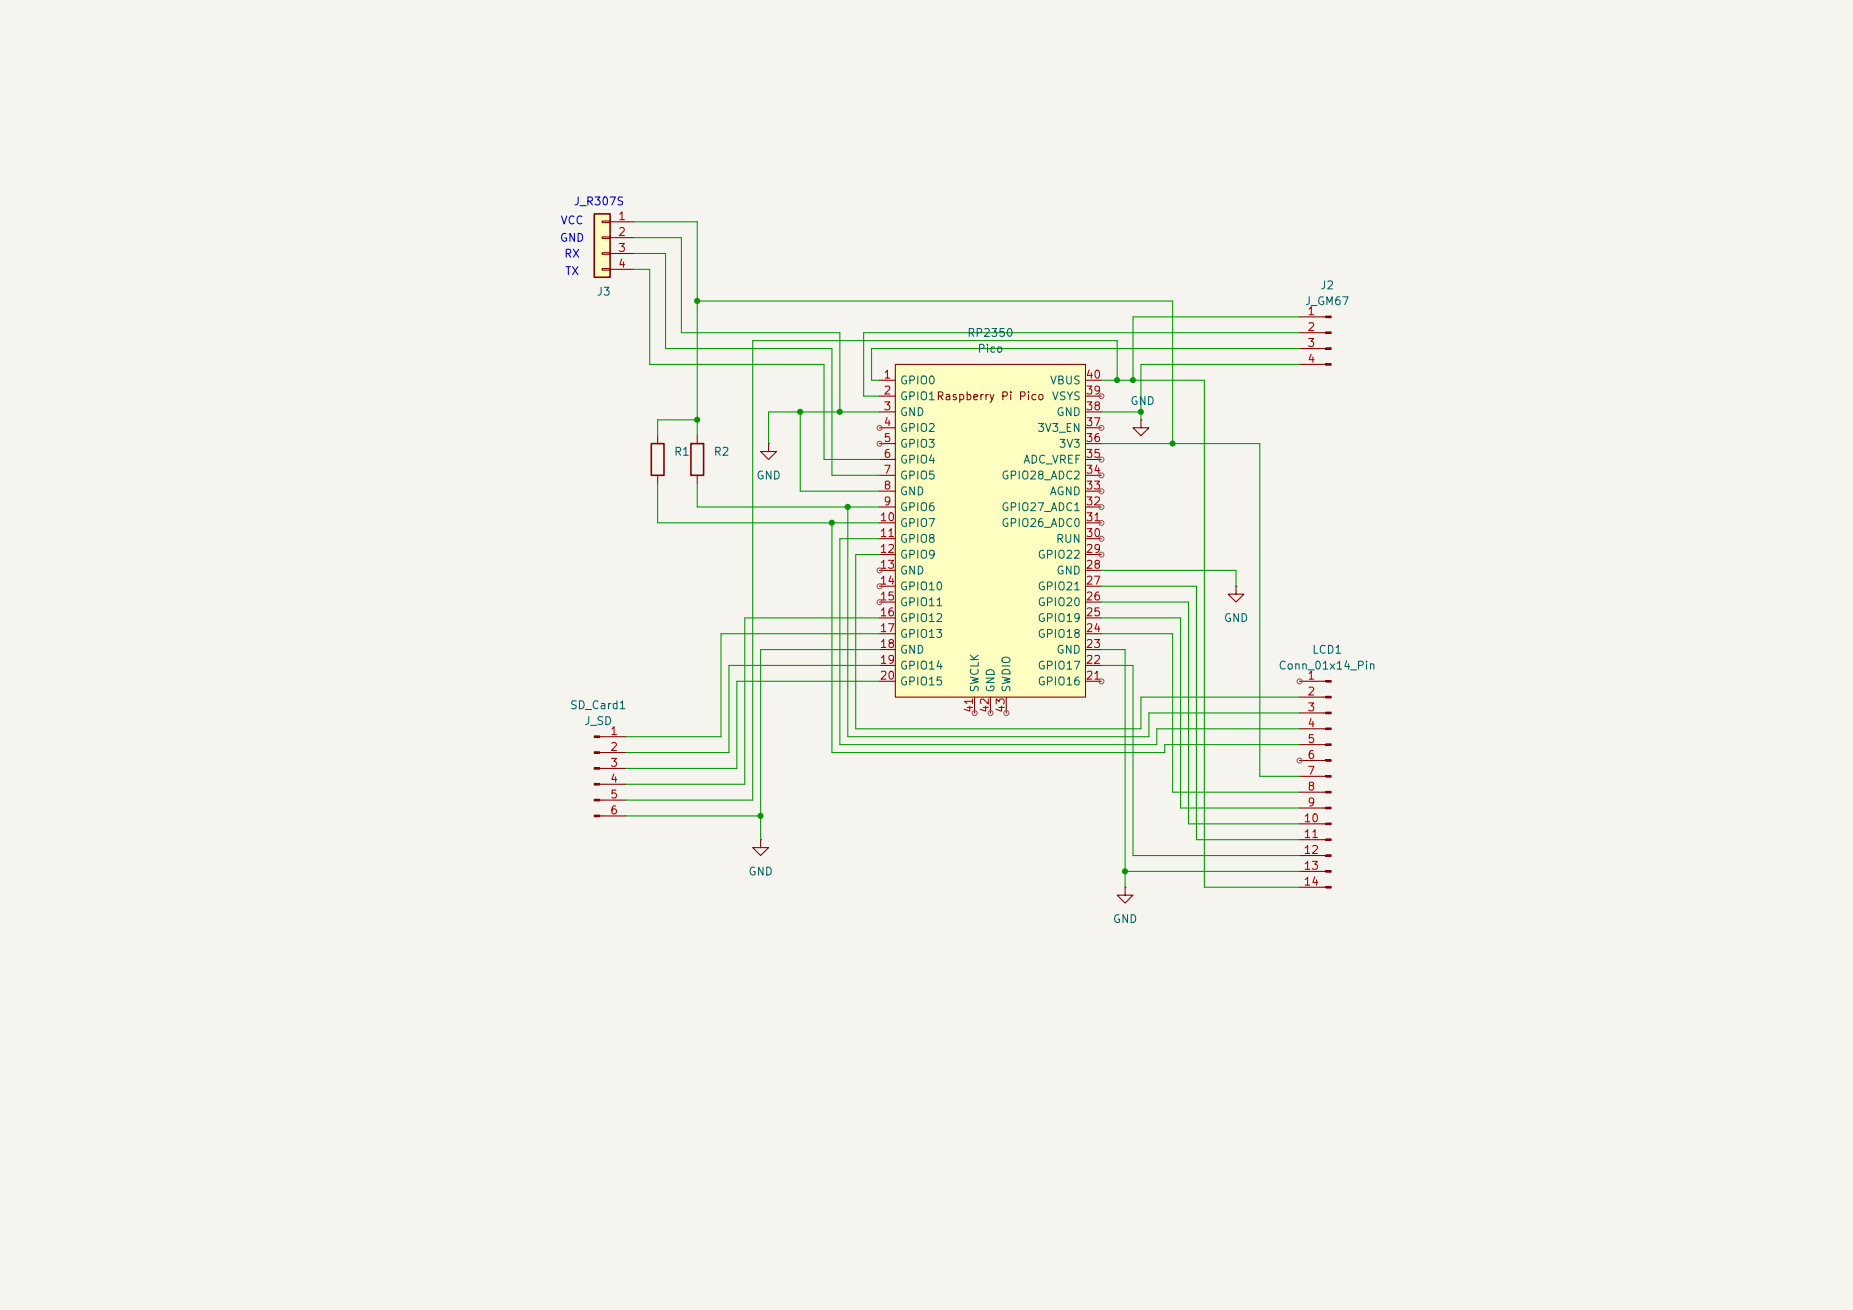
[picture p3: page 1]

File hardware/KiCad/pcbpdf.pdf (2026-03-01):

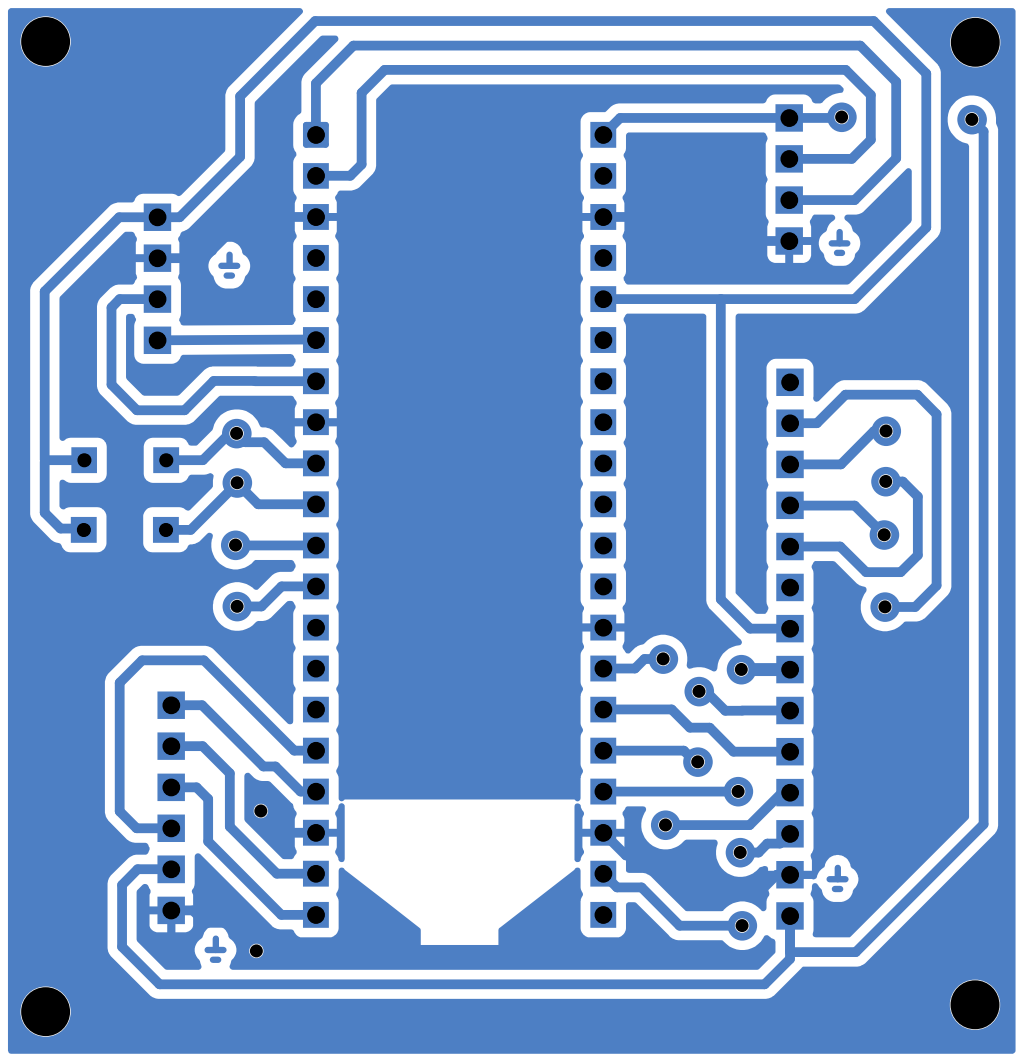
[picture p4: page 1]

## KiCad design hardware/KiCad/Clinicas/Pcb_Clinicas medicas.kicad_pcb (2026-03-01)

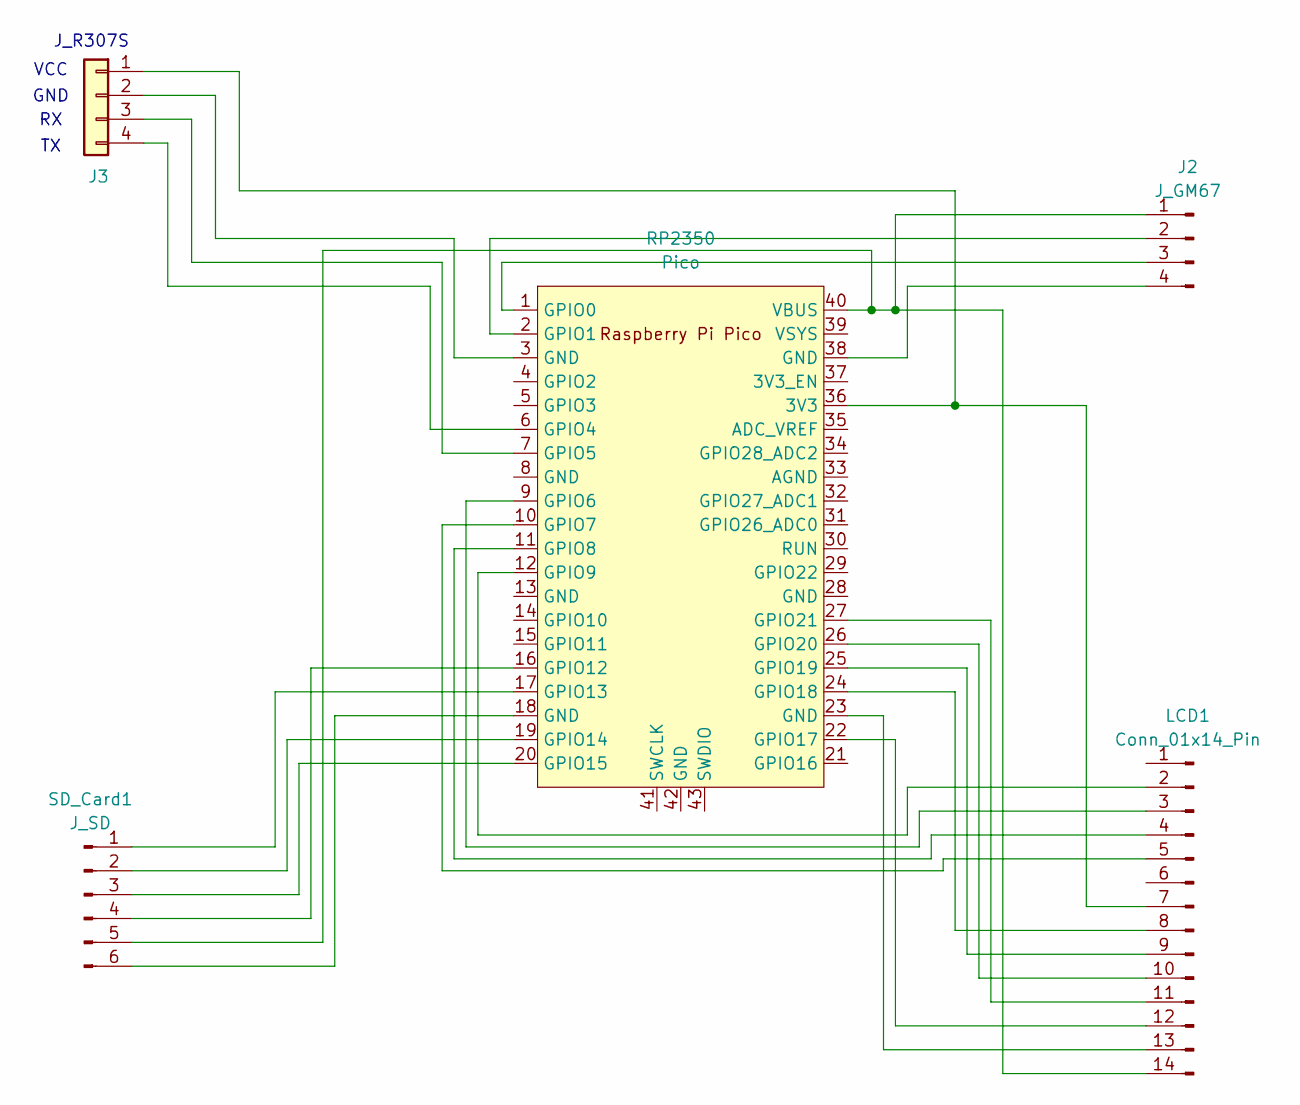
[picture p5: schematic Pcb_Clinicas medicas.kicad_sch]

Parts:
J2: J_GM67; PinHeader_1x04_P2.54mm_Vertical
J3: Conn_01x04; PinHeader_1x04_P2.54mm_Vertical
LCD1: Conn_01x14_Pin; PinHeader_1x14_P2.54mm_Vertical
RP2350: Pico; RaspberryPi_Pico_Common_THT
SD_Card1: J_SD; PinHeader_1x06_P2.54mm_Vertical

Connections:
unnamed: J2.1, LCD1.14, RP2350.40 (VBUS), SD_Card1.5
unnamed: J2.2, RP2350.2 (GPIO1)
unnamed: J2.3, RP2350.1 (GPIO0)
unnamed: J2.4, RP2350.38 (GND)
unnamed: J3.1, LCD1.7, RP2350.36 (3V3)
unnamed: J3.2, RP2350.3 (GND)
unnamed: J3.3, RP2350.7 (GPIO5)
unnamed: J3.4, RP2350.6 (GPIO4)
unnamed: LCD1.2, RP2350.12 (GPIO9)
unnamed: LCD1.3, RP2350.9 (GPIO6)
unnamed: LCD1.4, RP2350.11 (GPIO8)
unnamed: LCD1.5, RP2350.10 (GPIO7)
unnamed: LCD1.8, RP2350.24 (GPIO18)
unnamed: LCD1.9, RP2350.25 (GPIO19)
unnamed: LCD1.10, RP2350.26 (GPIO20)
unnamed: LCD1.11, RP2350.27 (GPIO21)
unnamed: LCD1.12, RP2350.22 (GPIO17)
unnamed: LCD1.13, RP2350.23 (GND)
unnamed: RP2350.16 (GPIO12), SD_Card1.4
unnamed: RP2350.17 (GPIO13), SD_Card1.1
unnamed: RP2350.19 (GPIO14), SD_Card1.2
unnamed: RP2350.20 (GPIO15), SD_Card1.3
unnamed: RP2350.18 (GND), SD_Card1.6

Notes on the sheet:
J_R307S
GND
VCC

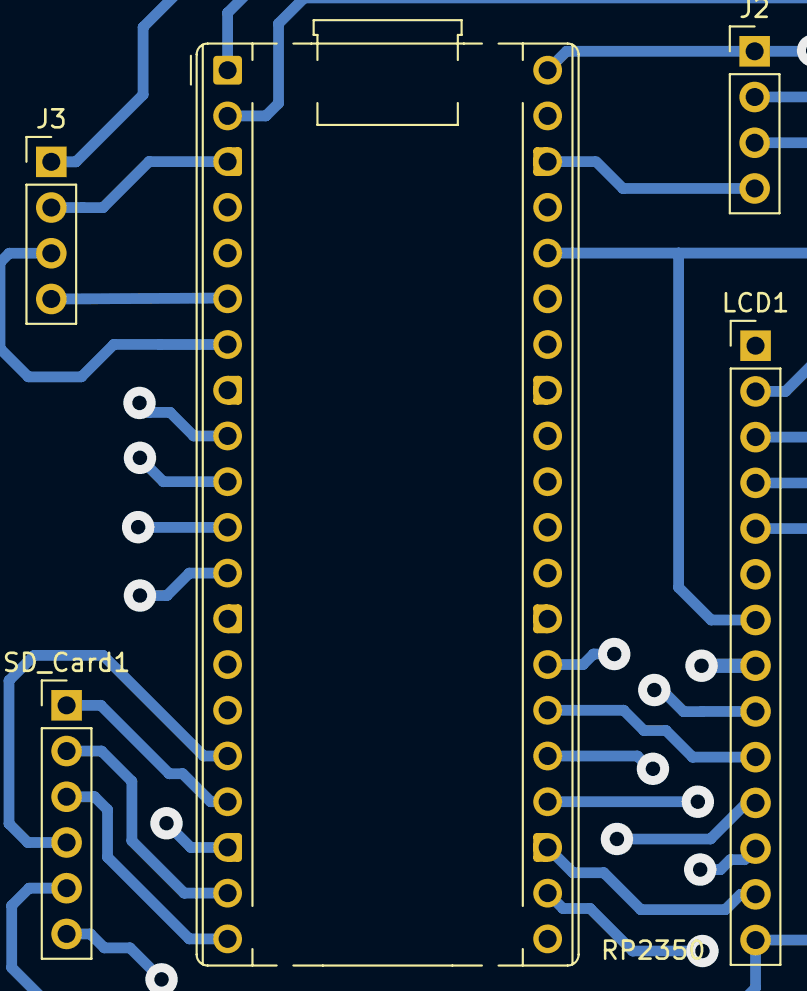
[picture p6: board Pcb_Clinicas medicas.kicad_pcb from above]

Board: 2 copper layers, 5 parts (0 on the bottom side), 23 nets.

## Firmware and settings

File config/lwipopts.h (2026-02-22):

#ifndef _LWIPOPTS_H
#define _LWIPOPTS_H

// Common settings used in most of the pico_w examples
// (see https://www.nongnu.org/lwip/2_1_x/group__lwip__opts.html for details)

// allow override in some examples
#ifndef NO_SYS
#define NO_SYS                      0
#endif

// allow override in some examples
#ifndef LWIP_SOCKET
#define LWIP_SOCKET                 1
#endif

#if PICO_CYW43_ARCH_POLL
#define MEM_LIBC_MALLOC             1
#else
// MEM_LIBC_MALLOC is incompatible with non polling versions
#define MEM_LIBC_MALLOC             0
#endif

#define MEM_ALIGNMENT               4
#define MEM_SIZE                    8000
#define MEMP_NUM_TCP_SEG            8
#define MEMP_NUM_ARP_QUEUE          6
#define MEMP_NUM_SYS_TIMEOUT        16
#define PBUF_POOL_SIZE              8
#define LWIP_ARP                    1
#define LWIP_ETHERNET               1
#define LWIP_ICMP                   1
#define LWIP_RAW                    1
#define TCP_WND                     (2 * TCP_MSS)
#define TCP_MSS                     1460
#define TCP_SND_BUF                 (2 * TCP_MSS)
#define TCP_SND_QUEUELEN            ((4 * (TCP_SND_BUF) + (TCP_MSS - 1)) / (TCP_MSS))
#define TCP_SND_QUEUELEN            ((4 * (TCP_SND_BUF) + (TCP_MSS - 1)) / (TCP_MSS))
#define LWIP_NETIF_STATUS_CALLBACK  1
#define LWIP_NETIF_LINK_CALLBACK    1
#define LWIP_NETIF_HOSTNAME         1
#define LWIP_NETCONN                1
#define MEMP_NUM_NETCONN            5
#define MEM_STATS                   0
#define SYS_STATS                   0
#define MEMP_STATS                  0
#define LINK_STATS                  0

// if (NO_SYS==1), then LWIP_NETIF_API must be 0
#define LWIP_NETIF_API              0

#define LWIP_IGMP                   0
#define LWIP_DNS                    1
#define LWIP_UDP                    1
#define LWIP_TCP                    1
#define LWIP_PROVIDE_ERRNO          1

// For FreeRTOS
#define TCPIP_THREAD_STACKSIZE      2048
#define DEFAULT_THREAD_STACKSIZE    2048
#define TCPIP_MBOX_SIZE             16
#define DEFAULT_UDP_RECVMBOX_SIZE   8
#define DEFAULT_TCP_RECVMBOX_SIZE   8
#define DEFAULT_ACCEPTMBOX_SIZE     8
#define LWIP_TCPIP_CORE_LOCKING     1
#define LWIP_COMPAT_MUTEX           1
#define LWIP_COMPAT_MUTEX_ALLOWED   1

#define LWIP_TIMEVAL_PRIVATE        0

// Enable checksum validation
#define CHECKSUM_CHECK_IP           1
#define CHECKSUM_CHECK_UDP          1
#define CHECKSUM_CHECK_TCP          1
#define CHECKSUM_CHECK_ICMP         1

// For PPP
#define PPP_SUPPORT                 0

// Minimal HTTPD
#define LWIP_HTTPD                  0

#define LWIP_SNTP                   1
#define SNTP_SERVER_DNS             1
#define SNTP_UPDATE_DELAY           86400000
#define SNTP_RETRY_TIMEOUT          5000
#define SNTP_MAX_SERVERS            3
#define SNTP_SERVER_ADDRESS         "pool.ntp.org"
#define SNTP_DEBUG                  LWIP_DBG_ON
#define SNTP_SET_SYSTEM_TIME(sec)   sntp_set_system_time(sec, 0)

#include "sntp_callbacks.h"

// For DHCP
#define LWIP_DHCP                   1
#define LWIP_DHCP_CHECK_LINK_UP     1

#ifndef NDEBUG
#define LWIP_DEBUG                  0
#define LWIP_STATS                  0
#define LWIP_STATS_DISPLAY          0
#endif

#define ETHARP_DEBUG                LWIP_DBG_OFF
#define NETIF_DEBUG                 LWIP_DBG_OFF
#define PBUF_DEBUG                 LWIP_DBG_OFF
#define API_LIB_DEBUG               LWIP_DBG_OFF
#define API_MSG_DEBUG               LWIP_DBG_OFF
#define SOCKETS_DEBUG               LWIP_DBG_OFF
#define ICMP_DEBUG                  LWIP_DBG_OFF
#define INET_DEBUG                  LWIP_DBG_OFF
#define IP_DEBUG                    LWIP_DBG_OFF
#define IP_REASS_DEBUG              LWIP_DBG_OFF
#define RAW_DEBUG                   LWIP_DBG_OFF
#define MEM_DEBUG                  LWIP_DBG_OFF
#define MEMP_DEBUG                  LWIP_DBG_OFF
#define SYS_DEBUG                   LWIP_DBG_OFF
#define TCP_DEBUG                   LWIP_DBG_OFF
#define TCP_INPUT_DEBUG             LWIP_DBG_OFF
#define TCP_OUTPUT_DEBUG            LWIP_DBG_OFF
#define TCP_RTO_DEBUG               LWIP_DBG_OFF
#define TCP_CWND_DEBUG              LWIP_DBG_OFF
#define TCP_WND_DEBUG               LWIP_DBG_OFF
#define TCP_FR_DEBUG                LWIP_DBG_OFF
#define TCP_QLEN_DEBUG              LWIP_DBG_OFF
#define TCP_RST_DEBUG               LWIP_DBG_OFF
#define UDP_DEBUG                   LWIP_DBG_OFF
#define TCPIP_DEBUG                 LWIP_DBG_OFF
#define PPP_DEBUG                   LWIP_DBG_OFF
#define SLIP_DEBUG                  LWIP_DBG_OFF
#define DHCP_DEBUG                  LWIP_DBG_OFF

#endif /* _LWIPOPTS_H */

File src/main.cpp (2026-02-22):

#include <stdio.h>
#include "pico/stdlib.h"
#include "pico/time.h"
#include "pico/cyw43_arch.h"
#include <FreeRTOS.h>
#include <task.h>
#include <queue.h>
#include <event_groups.h>
#include <semphr.h>
#include <lvgl.h>

#include "core/state_machine.hpp"
#include "tasks/task_lvgl.hpp"
#include "tasks/task_qr_reader.hpp"
#include "tasks/task_qr_validator.hpp"
#include "tasks/task_wifi_time_init.hpp"
#include "tasks/task_network.hpp"
#include "ui/screens/welcome_screen.hpp"
#include "services/time_service.hpp"
#include "services/fingerprint_service.hpp"

#include "adapters/lvgl/lvgl_display_adapter.hpp"
#include "adapters/lvgl/lvgl_touch_adapter.hpp"
#include "drivers/display/st7796/st7796_driver.hpp"
#include "drivers/touch/ft6336u/ft6336u_driver.hpp"
#include "drivers/qr_code_reader/gm67/gm67_driver.hpp"

#include "hal/rp2040/hal_spi_rp2040.hpp"
#include "hal/rp2040/hal_i2c_rp2040.hpp"
#include "hal/rp2040/hal_uart_rp2040.hpp"

#include "config/pin_config.hpp"
#include "config/display_config.hpp"
#include "config/qr_code_reader_config.hpp"
#include "config/fingerprint_config.hpp"

extern "C" void vApplicationStackOverflowHook(TaskHandle_t xTask, char* pcTaskName) {
    printf("STACK OVERFLOW in task: %s\n", pcTaskName);
    while(1) {
        tight_loop_contents();
    }
}

extern "C" void vApplicationMallocFailedHook(void) {
    printf("MALLOC FAILED - Out of heap memory!\n");
    while(1) {
        tight_loop_contents();
    }
}

#define LVGL_BUFFER_SIZE (DISP_HOR_RES * LVGL_BUFFER_LINES)
static lv_color_t lvgl_buf1[LVGL_BUFFER_SIZE];

EventGroupHandle_t wifi_time_ready_group_event = NULL;

int main()
{
    stdio_init_all();
    sleep_ms(2000);

    printf("\nStart System\n");

    lv_init();

    HAL_SPI_RP2040 *spi_hal_display = new HAL_SPI_RP2040(spi0, DISPLAY_PIN_MOSI, 0xFF, DISPLAY_PIN_SCK, DISPLAY_PIN_CS, DISPLAY_PIN_DC, DISPLAY_PIN_RST);

    ST7796Driver *display_driver = new ST7796Driver(spi_hal_display, DISP_HOR_RES, DISP_VER_RES);

    if (!display_driver->init()) {
        printf("ERROR: Failed to initialize display driver!\n");
        return -1;
    }

    display_driver->setRotation(DISP_ROTATION);

    LVGLDisplayAdapter *display_adapter = new LVGLDisplayAdapter(display_driver, lvgl_buf1, nullptr, LVGL_BUFFER_SIZE);
    display_adapter->registerDisplay();

    HAL_I2C_RP2040 *i2c_hal_touch = new HAL_I2C_RP2040(TOUCH_I2C_INSTANCE, TOUCH_PIN_SDA, TOUCH_PIN_SCL);

    if (!i2c_hal_touch->init(TOUCH_I2C_SPEED)) {
        printf("ERROR: Failed to initialize I2C for touch!\n");
        return -1;
    }

    FT6336U_Driver *touch_driver = new FT6336U_Driver(i2c_hal_touch, TOUCH_I2C_ADDR, TOUCH_WIDTH, TOUCH_HEIGHT, TOUCH_PIN_RST, TOUCH_PIN_INT);

    if (!touch_driver->init()) {
        printf("ERROR: Failed to initialize touch driver!\n");
        return -1;
    }

    LVGLTouchAdapter *touch_adapter = new LVGLTouchAdapter(touch_driver, DISP_HOR_RES, DISP_VER_RES, DISP_ROTATION);
    touch_adapter->registerInputDevice();

    HAL_UART_RP2040 *uart_hal_qr = new HAL_UART_RP2040(QR_UART_INSTANCE, QR_SCANNER_PIN_TX, QR_SCANNER_PIN_RX);

    if (!uart_hal_qr->init(QR_BAUDRATE)) {
        printf("ERROR: Failed to initialize UART for QR reader!\n");
        return -1;
    }

    GM67_Driver *qr_driver = new GM67_Driver(uart_hal_qr);

    if (!qr_driver->init()) {
        printf("ERROR: Failed to initialize QR driver!\n");
        return -1;
    }

    auto& fingerprintService = FingerprintService::getInstance();
    if (!fingerprintService.init()) {
        printf("ERROR: Failed to initialize fingerprint sensor!\n");
        return -1;
    }

    QueueHandle_t qr_data_queue = xQueueCreate(5, 512);
    if (qr_data_queue == NULL) {
        printf("ERROR: Failed to create QR data queue!\n");
        return -1;
    }

    static QRReaderParams qr_reader_params = {.qr_driver = qr_driver, .qr_data_queue = qr_data_queue};
    static QRValidatorParams qr_validator_params = {.qr_data_queue = qr_data_queue};

    wifi_time_ready_group_event = xEventGroupCreate();
    if (wifi_time_ready_group_event == NULL) {
        printf("ERROR: Failed to create WiFi/time event group!\n");
        return -1;
    }

    xEventGroupSetBits(wifi_time_ready_group_event, LVGL_READY_BIT);

    BaseType_t result;

    result = xTaskCreate(task_wifi_time_init, "WiFi_Time_Init", 2048, nullptr, 5, nullptr);
    if (result != pdPASS) {
        printf("ERROR: Failed to create WiFi/Time Init task!\n");
        return -1;
    }

    result = xTaskCreate(task_network, "Network", 3072, nullptr, 2, nullptr);
    if (result != pdPASS) {
        printf("ERROR: Failed to create Network task!\n");
        return -1;
    }

    result = xTaskCreate(task_lvgl, "LVGL", 3072, nullptr, 4, nullptr);
    if (result != pdPASS) {
        printf("ERROR: Failed to create LVGL task!\n");
        return -1;
    }

    result = xTaskCreate(task_qr_reader, "QR_Reader", 1536, &qr_reader_params, 3, nullptr);
    if (result != pdPASS) {
        printf("ERROR: Failed to create QR reader task!\n");
        return -1;
    }

    result = xTaskCreate(task_qr_validator, "QR_Validator", 2048, &qr_validator_params, 2, nullptr);
    if (result != pdPASS) {
        printf("ERROR: Failed to create QR validator task!\n");
        return -1;
    }

    printf("System ready\n");

    vTaskStartScheduler();

    printf("ERROR: Scheduler returned!\n");
    while (1) {
        tight_loop_contents();
    }

    return 0;
}

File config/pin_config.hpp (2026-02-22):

#ifndef PIN_CONFIG_HPP
#define PIN_CONFIG_HPP

/**
 * @file pin_config.hpp
 * @brief Hardware pin configuration for the Medical Clinic Check-in System
 * 
 * This file centralizes all GPIO pin assignments for the Raspberry Pi Pico
 * to make it easier to change hardware connections without modifying code.
 */

// ============================================================================
// SPI Display Pins (ST7796)
// ============================================================================
#define DISPLAY_PIN_MOSI 19  // SPI0 TX (Master Out Slave In)
#define DISPLAY_PIN_SCK  18  // SPI0 Clock
#define DISPLAY_PIN_CS   17  // Chip Select
#define DISPLAY_PIN_DC   20  // Data/Command select
#define DISPLAY_PIN_RST  21  // Display Reset

// ============================================================================
// I2C Touch Controller Pins (FT6336U)
// ============================================================================
#define TOUCH_PIN_SDA 6  // I2C1 Data
#define TOUCH_PIN_SCL 7  // I2C1 Clock
#define TOUCH_PIN_RST 8  // Touch controller Reset
#define TOUCH_PIN_INT 9  // Touch controller Interrupt

// ============================================================================
// Status LED
// ============================================================================
#ifndef PICO_DEFAULT_LED_PIN
#define STATUS_PIN_LED 25  // Default onboard LED for Pico
#else
#define STATUS_PIN_LED PICO_DEFAULT_LED_PIN
#endif

// ============================================================================
// QR Scanner (GM67) Pins
// ============================================================================
// Uses UART0 (GP0, GP1)
// Debug output via USB (stdio_usb enabled in CMakeLists.txt)
#define QR_SCANNER_PIN_TX 0
#define QR_SCANNER_PIN_RX 1

// ============================================================================
// Fingerprint Sensor (R307S) Pins
// ============================================================================
// Uses UART1 (GP4, GP5)
#define FINGERPRINT_PIN_TX 4
#define FINGERPRINT_PIN_RX 5

// ============================================================================
// SD Card Reader Pins (SPI1)
// ============================================================================
#define SDCARD_PIN_MISO 12  // SPI1 RX (Master In Slave Out) - GP12
#define SDCARD_PIN_MOSI 15  // SPI1 TX (Master Out Slave In) - GP15
#define SDCARD_PIN_SCK  14  // SPI1 Clock - GP14
#define SDCARD_PIN_CS   13  // Chip Select - GP13

#endif // PIN_CONFIG_HPP

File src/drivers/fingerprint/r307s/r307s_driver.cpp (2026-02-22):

#include "r307s_driver.hpp"
#include "pico/stdlib.h"
#include <cstring>
#include <cstdio>

R307S_Driver::R307S_Driver(HAL_UART_Interface* uart_hal, uint32_t password, uint32_t address)
    : uart_hal_(uart_hal),
      password_(password),
      address_(address),
      is_initialized_(false),
      data_packet_size_(128) {
    memset(packet_buffer_, 0, PACKET_BUFFER_SIZE);
}

bool R307S_Driver::init() {
    if (uart_hal_ == nullptr) {
        return false;
    }

    // Clear any pending data in UART buffer
    uart_hal_->clearRxBuffer();
    
    // Small delay for sensor to stabilize after power-on
    sleep_ms(500);
    
    // Verify connection with the sensor
    if (!verifyPassword()) {
        return false;
    }

    is_initialized_ = true;

    // Read sensor system parameters to get data packet size
    uint16_t status_reg, sys_id, lib_size, sec_level;
    FingerprintStatus sys_status = readSysPara(status_reg, sys_id, lib_size, sec_level);
    if (sys_status == FingerprintStatus::OK) {
        // Data packet size is at offset 12-13 in system parameters
        // In packet_buffer_: [0-1]=start, [2-5]=addr, [6]=PID, [7-8]=len, [9]=confirm,
        //   [10-11]=status_reg, [12-13]=sys_id, [14-15]=lib_size, [16-17]=sec_level,
        //   [18-21]=device_addr, [22-23]=data_packet_size_code, [24-25]=baud_rate
        uint16_t pkt_size_code = readU16(&packet_buffer_[22]);
        switch (pkt_size_code) {
            case 0: data_packet_size_ = 32; break;
            case 1: data_packet_size_ = 64; break;
            case 2: data_packet_size_ = 128; break;
            case 3: data_packet_size_ = 256; break;
            default: data_packet_size_ = 128; break;
        }
        printf("[R307S] Sensor packet size: %zu bytes (code=%d), library: %d, security: %d\n",
               data_packet_size_, pkt_size_code, lib_size, sec_level);
    } else {
        printf("[R307S] WARNING: Could not read system params, using default packet size 128\n");
        data_packet_size_ = 128;
    }

    return true;
}

bool R307S_Driver::verifyPassword() {
    uint8_t data[4];
    writeU32(data, password_);
    
    if (!sendPacket(CMD_VERIFY_PASSWORD, data, 4)) {
        return false;
    }

    if (receivePacket() == 0) {
        return false;
    }

    return getConfirmationCode() == static_cast<uint8_t>(FingerprintStatus::OK);
}

FingerprintStatus R307S_Driver::getImage() {
    if (!is_initialized_) {
        return FingerprintStatus::ERROR_COMM;
    }

    if (!sendPacket(CMD_GEN_IMAGE)) {
        return FingerprintStatus::ERROR_COMM;
    }

    if (receivePacket(IMAGE_TIMEOUT_MS) == 0) {
        return FingerprintStatus::ERROR_TIMEOUT;
    }

    return static_cast<FingerprintStatus>(getConfirmationCode());
}

FingerprintStatus R307S_Driver::image2Tz(uint8_t slot) {
    if (!is_initialized_) {
        return FingerprintStatus::ERROR_COMM;
    }

    if (slot != 1 && slot != 2) {
        return FingerprintStatus::ERROR_BAD_LOCATION;
    }

    uint8_t data[1] = { slot };
    
    if (!sendPacket(CMD_IMAGE_2_TZ, data, 1)) {
        return FingerprintStatus::ERROR_COMM;
    }

    if (receivePacket(DEFAULT_TIMEOUT_MS * 2) == 0) {
        return FingerprintStatus::ERROR_TIMEOUT;
    }

    return static_cast<FingerprintStatus>(getConfirmationCode());
}

FingerprintStatus R307S_Driver::createModel() {
    if (!is_initialized_) {
        return FingerprintStatus::ERROR_COMM;
    }

    if (!sendPacket(CMD_REG_MODEL)) {
        return FingerprintStatus::ERROR_COMM;
    }

    if (receivePacket() == 0) {
        return FingerprintStatus::ERROR_TIMEOUT;
    }

    return static_cast<FingerprintStatus>(getConfirmationCode());
}

FingerprintStatus R307S_Driver::storeModel(uint16_t id) {
    if (!is_initialized_) {
        return FingerprintStatus::ERROR_COMM;
    }

    uint8_t data[3];
    data[0] = 0x01;  // Buffer ID: 0x01 = CharBuffer1, 0x02 = CharBuffer2
    writeU16(&data[1], id);
    
    if (!sendPacket(CMD_STORE, data, 3)) {
        return FingerprintStatus::ERROR_COMM;
    }

    if (receivePacket() == 0) {
        return FingerprintStatus::ERROR_TIMEOUT;
    }

    FingerprintStatus status = static_cast<FingerprintStatus>(getConfirmationCode());
    return status;
}

FingerprintStatus R307S_Driver::fingerFastSearch(FingerprintMatch& match) {
    if (!is_initialized_) {
        return FingerprintStatus::ERROR_COMM;
    }

    match.matched = false;
    match.id = 0;
    match.confidence = 0;

    uint8_t data[5];
    data[0] = 0x01;     // Buffer ID (CharBuffer1)
    writeU16(&data[1], 0);      // Start page (0 = first page)
    writeU16(&data[3], 0xFFFF); // Page count (0xFFFF = all pages)
    
    if (!sendPacket(CMD_SEARCH, data, 5)) {
        return FingerprintStatus::ERROR_COMM;
    }

    if (receivePacket(DEFAULT_TIMEOUT_MS * 2) == 0) {
        return FingerprintStatus::ERROR_TIMEOUT;
    }

    FingerprintStatus status = static_cast<FingerprintStatus>(getConfirmationCode());
    
    if (status == FingerprintStatus::OK) {
        // Parse the response: confirmation_code + page_id(2) + match_score(2)
        if (packet_buffer_[6] == PID_ACK) {
            match.matched = true;
            match.id = readU16(&packet_buffer_[10]);
            match.confidence = readU16(&packet_buffer_[12]);
        }
    }

    return status;
}

FingerprintStatus R307S_Driver::deleteModel(uint16_t id) {
    if (!is_initialized_) {
        return FingerprintStatus::ERROR_COMM;
    }

    uint8_t data[4];
    writeU16(&data[0], id);     // Page ID (position)
    writeU16(&data[2], 1);      // Delete count (delete 1 template)
    
    if (!sendPacket(CMD_DELETE, data, 4)) {
        return FingerprintStatus::ERROR_COMM;
    }

    if (receivePacket() == 0) {
        return FingerprintStatus::ERROR_TIMEOUT;
    }

    return static_cast<FingerprintStatus>(getConfirmationCode());
}

FingerprintStatus R307S_Driver::emptyDatabase() {
    if (!is_initialized_) {
        return FingerprintStatus::ERROR_COMM;
    }

    if (!sendPacket(CMD_EMPTY)) {
        return FingerprintStatus::ERROR_COMM;
    }

    if (receivePacket(DEFAULT_TIMEOUT_MS * 2) == 0) {
        return FingerprintStatus::ERROR_TIMEOUT;
    }

    return static_cast<FingerprintStatus>(getConfirmationCode());
}

FingerprintStatus R307S_Driver::getTemplateCount(uint16_t& count) {
    if (!is_initialized_) {
        return FingerprintStatus::ERROR_COMM;
    }

    count = 0;

    if (!sendPacket(CMD_TEMPLATE_NUM)) {
        return FingerprintStatus::ERROR_COMM;
    }

    if (receivePacket() == 0) {
        return FingerprintStatus::ERROR_TIMEOUT;
    }

    FingerprintStatus status = static_cast<FingerprintStatus>(getConfirmationCode());
    
    if (status == FingerprintStatus::OK) {
        // Parse the response: confirmation_code + template_count(2)
        count = readU16(&packet_buffer_[10]);
    }

    return status;
}
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

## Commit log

2026-02-22 Adiciona arquivos de configuracoes dos modulos do projeto
2026-02-22 Adiciona arquivos para cmake
2026-03-01 Sanitize configs, ignore build/media, update docs (rp2040)
    [Clinicas.kicad_pcb, Clinicas.kicad_sch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]
